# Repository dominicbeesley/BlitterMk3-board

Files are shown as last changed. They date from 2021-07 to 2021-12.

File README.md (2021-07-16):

# BlitterMk3-board
A 6502 FPGA development board targeted at the BBC Micro/Electron range of computers but hopefully also suitable for any 6502/65c02 or 65816 based computer

## Features

- Intel MAX 10 FPGA (10MXXDCF256) in size ranging from 4000 to 50000 LEs
- HDMI output from FPGA via LVDS pins (experimental)
- stereo 1 bit DAC
- uSD card
- Battery backup with optional supervisor IC and memory lockout
- i2c Real time clock
- i2c Flash EEPROM
- parallel 8-bit 55ns flash ROM 39x040 (512kB)
- up to 4 TSOP-II 44 RAM chips for up to 8MB RAM, 1 chip can be optionally battery backed
- 6502/65C02/6512/65102/65112/65816 compatible plug (configurable with jumpers/firmware)
- 5V compatible expansion headers for hosting hard CPU or Raspberry PI Zero

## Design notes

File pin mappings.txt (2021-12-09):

PORTS:

#pins

10	PORTA = 8 bit ACT/HCT io
8	PORTB = 8 bit ACT/HCT o buffer
12	PORTC = 12 bit 74CB3T
12	PORTD = 12 bit 74CB3T
15	PORTE/D/E = 12 bit 74CB3T shared pins on fpga only one enabled at a time
57

m
brdcon	lvl	dir	Mk3 pin		Mk2 pin	(*indicates changes)		65(c)02		65816		6800		6x-09		68008_48	z80		68008_52	680x0_64	680x0_68QFP	8088			8086
																									MIN	MAX		MIN	MAX

	### CMOS LEVEL IO ###

J52	cmos	io	PORTA[0]	CPUSKT_D_io[0]				D[0]	33	D[0]	33	D[0]	33	D[0]	31	D[0]	27	D[0]	14	D[0]	30	D[0]	5	D[0]	5	AD[0]		16	AD[0]		16
J52	cmos	io	PORTA[1]	CPUSKT_D_io[1]				D[1]	32	D[1]	32	D[1]	32	D[1]	30	D[1]	26	D[1]	15	D[1]	29	D[1]	4	D[1]	4	AD[1]		15	AD[1]		15
J52	cmos	io	PORTA[2]	CPUSKT_D_io[2]				D[2]	31	D[2]	31	D[2]	31	D[2]	29	D[2]	25	D[2]	12	D[2]	28	D[2]	3	D[2]	3	AD[2]		14	AD[2]		14
J52	cmos	io	PORTA[3]	CPUSKT_D_io[3]				D[3]	30	D[3]	30	D[3]	30	D[3]	28	D[3]	24	D[3]	8	D[3]	27	D[3]	2	D[3]	2	AD[3]		13	AD[3]		13
J52	cmos	io	PORTA[4]	CPUSKT_D_io[4]				D[4]	29	D[4]	29	D[4]	29	D[4]	27	D[4]	23	D[4]	7	D[4]	26	D[4]	1	D[4]	1	AD[4]		12	AD[4]		12
J52	cmos	io	PORTA[5]	CPUSKT_D_io[5]				D[5]	28	D[5]	28	D[5]	28	D[5]	26	D[5]	22	D[5]	9	D[5]	25	D[5]	64	D[5]	68	AD[5]		11	AD[5]		11
J52	cmos	io	PORTA[6]	CPUSKT_D_io[6]				D[6]	27	D[6]	27	D[6]	27	D[6]	25	D[6]	21	D[6]	10	D[6]	24	D[6]	63	D[6]	67	AD[6]		10	AD[6]		10
J52	cmos	io	PORTA[7]	CPUSKT_D_io[7]				D[7]	26	D[7]	26	D[7]	26	D[7]	24	D[7]	20	D[7]	13	D[7]	23	D[7]	62	D[7]	66	AD[7]		9	AD[7]		9

	### CMOS LEVEL OUT ###

J52	cmos	o	PORTB[0]	CPUSKT_6BE9TSCKnVPA_o			BE	36	BE	6	TSC	39	TSC	39	nVPA	39			nVPA	43	nVPA	21	nVPA	23	MNnMX		33	MNnMX		33
J52	cmos	o	PORTB[1]	CPUSKT_9Q_o			*	[nSO]1	38	[ABRT]2 3	phi1	3	Q	35	?BERR?	40			?BERR?	44	?nBERR? 22	?nBERR?	24	
J52	cmos	o	PORTB[2]	CPUSKT_PHI09EKZCLK_o			phi0	37	phi0	37	phi2	37	E	34	CLK	34			CLK	38	CLK	15	CLK	15	CLK		19	CLK		19
J52	cmos	o	PORTB[3]	CPUSKT_RDY9KnHALTZnWAIT_o		RDY	2	RDY	2	HALT	2	HALT	40			nWAIT	24	?nBGACK?36	?nBGACK?12	?nBGACK?12	READY		22	READY		22
J52	cmos	o	PORTB[4]	CPUSKT_nIRQKnIPL1_o			nIRQ	4	nIRQ	4	nIRQ	4	nIRQ	3	IPL1	41	nIRQ	16	IPL1	45	IPL1	24	IPL1	26	INTR		18	INTR		18
J52	cmos	o	PORTB[5]	CPUSKT_nNMIKnIPL02_o			nNMI	6	nNMI	6	nNMI	6	nNMI	2	IPL0/2	42	nNMI	17	IPL0	47	IPL0	25	IPL0	27	NMI		17	NMI		17
J52	cmos	o	PORTB[6]	CPUSKT_nRES_o				nRES	40	nRES	40	nRES	40	nRES	37			nRES	26	?IPL2?	46	?IPL2?	23	?IPL2?	25	RESET		21	RESET		21
			PORTB[7]	CPUSKT_9nFIRQLnDTACK_o							DBE	36	nFIRQ	4	nDTACK	31			nDTACK	34	nDTACK	10	nDTACK	10

	### TTL I/O ###

J51		i	PORTC[0]	CPUSKT_A_i[0]				A[0]	9	A[0]	9	A[0]	9	A[0]	8	A[0]	46	A[0]	30	A[0]	51	?nLDS?	8	?nLDS?	8	nSSO	-hi-	34	BHE/S7		34
J51		i	PORTC[1]	CPUSKT_A_i[1]				A[1]	10	A[1]	10	A[1]	10	A[1]	9	A[1]	47	A[1]	31	A[1]	51	A[1]	29	A[1]	32	
J51		i	PORTC[2]	CPUSKT_A_i[2]				A[2]	11	A[2]	11	A[2]	11	A[2]	10	A[2]	48	A[2]	32	A[2]	1	A[2]	30	A[2]	33
J51		i	PORTC[3]	CPUSKT_A_i[3]				A[3]	12	A[3]	12	A[3]	12	A[3]	11	A[3]	1	A[3]	33	A[3]	2	A[3]	31	A[3]	34
J51		i	PORTC[4]	CPUSKT_A_i[4]				A[4]	13	A[4]	13	A[4]	13	A[4]	12	A[4]	2	A[4]	34	A[4]	3	A[4]	32	A[4]	35
J51		i	PORTC[5]	CPUSKT_A_i[5]				A[5]	14	A[5]	14	A[5]	14	A[5]	13	A[5]	3	A[5]	35	A[5]	4	A[5]	33	A[5]	36
J51		i	PORTC[6]	CPUSKT_A_i[6]				A[6]	15	A[6]	15	A[6]	15	A[6]	14	A[6]	4	A[6]	36	A[6]	5	A[6]	34	A[6]	37
J51		i	PORTC[7]	CPUSKT_A_i[7]				A[7]	16	A[7]	16	A[7]	16	A[7]	15	A[7]	5	A[7]	37	A[7]	6	A[7]	35	A[7]	38
J51		i	PORTC[8]	CPUSKT_A_i[16]												A[16]	16			A[16]	18	A[16]	44	A[16]	47	A[16]S3		38	A[16]S3		38
J51		i	PORTC[9]	CPUSKT_A_i[17]												A[17]	17			A[17]	19	A[17]	45	A[17]	48	A[17]S4		37	A[17]S4		37
J51		i	PORTC[10]	CPUSKT_A_i[18]												A[18]	18			A[18]	20	A[18]	46	A[18]	49	A[18]S5		36	A[18]S5		36
J51		i	PORTC[11]	CPUSKT_A_i[19]												A[19]	19			A[19]	21	A[19]	47	A[19]	50	A[19]S6		35	A[19]S6		35
	
J51		i	PORTD[0]	CPUSKT_6EKEZnRD_i			-	35	E	35					?E?	38	nRD	21	?E?	42	?E?	20	?E?	22	nRD		32	nRD		32
J51		i	PORTD[1]	CPUSKT_RnWZnWR_i			RnW	34	RnW	34	RnW	32	RnW	32	RnW	30	nWR	22	RnW	33	RnW	9	RnW	9	nWR	nLOCK	29	nWR	nLOCK	29
J51		i 	PORTD[2]	CPUSKT_PHI16ABRT9BSKnDS_i	*							BS	5	nDS	29	?nHALT?	18	nDS	32	?nUDS?	7	?nUDS?	7	nDEN	nS2	26	nDEN	nS2	26
J51		i	PORTD[3]	CPUSKT_PHI26VDAKFC0ZnMREQ_i		phi2	39	VDA	39					FC0	45	nMREQ	19	FC0	50	FC0	28	FC0	30	nINTA	QS1	24	nINTA	QS1	24
J51		i	PORTD[4]	CPUSKT_SYNC6VPA9LICKFC2ZnM1_i		SYNC	7	VPA	7			LIC	38	FC2	43	M1	27	FC2	48	FC2	26	FC2	28	DTnR	nS1	27	DTnR	nS1	27
J51		i	PORTD[5]	CPUSKT_VSS6VPA9BAKnAS_i			[vss]3	1	[VPB]3	1	BA	6	BA	6	nAS	28	?nRFSH?	28	nAS	31	nAS	6	nAS	6	ALE	QS0	25	ALE	QS0	25
J51		i	PORTD[6]	CPUSKT_nSO6MX9AVMAKFC1ZnIOREQ_i	*	phi1	3	[M/X]1	38	VMA	36	AVMA	36	FC1	44	nIOREQ	20	FC1	49	FC1	27	FC1	29	IOnM	nS0	28	MnIO	nS0	28
J51		io	PORTD[7]	CPUSKT_C6nML9BUSYKnBGZnBUSACK_i 	MLB	5	MLB	5			BUSY	33	nBG	32	nBUSACK	23	nBG	35	nBG	11	nBG	11	HLDA	RQGT0	30	HLDA	RQGT0	
J51		io	PORTD[8]	CPUSKT_KnBRZnBUSREQ_o											nBR	33	nBUSREQ	25	nBR	37	nBR	13	nBR	13	HOLD	RQGT1	31	HOLD	RQGT1	31
J51		o	PORTD[9]														nRES	37			nRES	41	nRES	18	nRES	20	?nTEST?		23	?nTEST?		23
J51		o	PORTD[10]														HALT	36			nHALT	40	nHALT	17	nHALT	19				
J51		i	PORTD[11]																		?nVMA?	19	?nVMA?	21

1 nSO/MX is selected via jumper
2 ABORT/PHI1 is selected via jumper
3 jumper to allow pull pin 3 direct to gnd

	### MULTIPLEXED I/O ### only one of these ports is active at once

J51		i	PORTE[0]	CPUSKT_A_i[8]				A[8]	17	A[8]	17	A[8]	17	A[8]	16	A[8]	6	A[8]	38	A[8]	7	A[8]	36	A[8]	39	
J51		i	PORTE[1]	CPUSKT_A_i[9]				A[9]	18	A[9]	18	A[9]	18	A[9]	17	A[9]	7	A[9]	39	A[9]	8	A[9]	37	A[9]	40	
J53		i	PORTE[2]	CPUSKT_A_i[10]				A[10]	19	A[10]	19	A[10]	19	A[10]	18	A[10]	8	A[10]	40	A[10]	9	A[10]	38	A[10]	41	
J53		i	PORTE[3]	CPUSKT_A_i[11]				A[11]	20	A[11]	20	A[11]	20	A[11]	19	A[11]	9	A[11]	1	A[11]	10	A[11]	39	A[11]	42	
J53		i	PORTE[4]	CPUSKT_A_i[12]				A[12]	22	A[12]	22	A[12]	22	A[12]	20	A[12]	10	A[12]	2	A[12]	11	A[12]	40	A[12]	43	
J53		i	PORTE[5]	CPUSKT_A_i[13]				A[13]	23	A[13]	23	A[13]	23	A[13]	21	A[13]	11	A[13]	3	A[13]	12	A[13]	41	A[13]	55	
J53		i	PORTE[6]	CPUSKT_A_i[14]				A[14]	24	A[14]	24	A[14]	24	A[14]	22	A[14]	12	A[14]	4	A[14]	14	A[14]	42	A[14]	45	
J53		i	PORTE[7]	CPUSKT_A_i[15]				A[15]	25	A[15]	25	A[15]	25	A[15]	23	A[15]	14	A[15]	5	A[15]	16	A[15]	43	A[15]	46	
J54		i	PORTE[8]																		A[20]	22	A[20]	48	A[20]	51
J54		i	PORTE[9]																		A[21]	13	A[21]	50	A[21]	53
J54		i	PORTE[10]																				A[22]	51	A[22]	54
J54		i	PORTE[11]																				A[23]	52	A[23]	55

J54		io	PORTF[4]																				D[8]	61	D[8]	65	A[8]		8	AD[8]		8
J54		io	PORTF[5]																				D[9]	60	D[9]	64	A[9]		7	AD[9]		7
J54		io	PORTF[6]																				D[10]	59	D[10]	63	A[10]		6	AD[10]		6
J54		io	PORTF[7]																				D[11]	58	D[11]	62	A[11]		5	AD[11]		5
J54		io	PORTF[8]																				D[12]	57	D[12]	61	A[12]		4	AD[12]		4
J54		io	PORTF[9]																				D[13]	56	D[13]	60	A[13]		3	AD[13]		3
J54		io	PORTF[10]																				D[14]	55	D[14]	59	A[14]		2	AD[14]		2
J54		io	PORTF[11]																				D[15]	54	D[15]	58	A[15]		39	AD[15]		

# boot time configuration

t65		PORTG[3]						
swromx		PORTG[4]			
mosram		PORTG[5]			
memi		PORTG[6]
-free-		PORTG[7]
-free-		PORTG[8]

sys_type[0]	PORTG[0]
sys_type[1]	PORTG[1]
sys_type[2]	PORTG[2]

# cpu board configuration

cpu_type[0]	PORTF[0]
cpu_type[1]	PORTF[1]
cpu_type[2]	PORTF[2]
cpu_type[3]	PORTF[3]

cpu_speed[0]	PORTG[9]
cpu_speed[1]	PORTG[10]
cpu_speed[2]	PORTG[11]

	- own pin -
	- own pin -
	- own pin -

#cpu config
			cpu_type	speed
			D C B A		C B A
			3 2 1 0 	2 1 0
6502A		2MHz	- - - -		- - -

W65c02		2Mhz	- - - x		- - -
W65c02		4Mhz	- - - x		- - x
W65c02		8MHz	- - - x		- x -
W65c02		10Mhz	- - - x		- x x
W65c02		14MHz	- - - x		x - -

R65c02		2Mhz	- - x -		- - -
R65c02		4Mhz	- - x -		- - x
R65c02		8MHz	- - x -		- x -
R65c02		10Mhz	- - x -		- x x
R65c02		14MHz	- - x -		x - -

65x816		2Mhz	- - x x		- - -
65x816		4Mhz	- - x x		- - x
65x816		8MHz	- - x x		- x -
65x816		10Mhz	- - x x		- x x
65x816		14MHz	- - x x		x - -

R6512		2Mhz	- x - -		- - -
R6512		4Mhz	- x - -		- - x
R6512		8MHz	- x - -		- x -
R6512		10Mhz	- x - -		- x x
R6512		14MHz	- x - -		x - -

G65SC12		2Mhz	- x - x		- - -
G65SC12		4Mhz	- x - x		- - x
G65SC12		8MHz	- x - x		- x -
G65SC12		10Mhz	- x - x		- x x
G65SC12		14MHz	- x - x		x - -

65c102		2Mhz	- x x -		- - -
65c102		4Mhz	- x x -		- - x
65c102		8MHz	- x x -		- x -
65c102		10Mhz	- x x -		- x x
65c102		14MHz	- x x -		x - -

65c112		2Mhz	- x x x		- - -
65c112		4Mhz	- x x x		- - x
65c112		8MHz	- x x x		- x -
65c112		10Mhz	- x x x		- x x
65c112		14MHz	- x x x		x - -

6809		2	x - - -		- - -
6809		3.5	x - - -		- - x
6309		2	x - - -		x - -
6309		3.5	x - - -		x - x
6309		4	x - - -		x x -

6800		2	x - - -		x x x		???

z80		2	x - x -		- - -
z80		4	x - x -		- - x
z80		8	x - x -		- x -
z80		10	x - x -		- x x
z80		12	x - x -		x - -
z80		16	x - x -		x - x
z80		20	x - x -		x x -

8088		?	x - x x		x - -
8088		?	x - x x		x - x
8088		?	x - x x		x x -
8088		?	x - x x		x x x

8086		?	x - x x		- - -
8086		?	x - x x		- - x
8086		?	x - x x		- x -
8086		?	x - x x		- x x

68008/48	8	x x - -		- - -
68008/48	10	x x - -		- - x

68008/52	8	x x - -		- x -
68008/52	10	x x - -		- x x

680x0		8	x x - -		x - -
680x0		10	x x - -		x - x
680x0		16	x x - -		x x -
680x0		20	x x - -		x x x

spare:			x - - x
spare:			x x - x
spare:			x x x -

rpi 		model	x x x x		x - -
rpi 		model	x x x x		x - x
rpi 		model	x x x x		x x -
rpi 		model	x x x x		x x x

other		?	x x x x		- ? ?	 (8)

# sys type config

		sys_type
		2 1 0
Model B		- - -
Elk		- - x
Model B+	- x -
Master 128	- x x

# note 65816 ABORT is pin shared with phi1 - need a cmos output and jumper for 816, moved to 6x09 Q pin if req
# note nSO, if required for 6502 will need a cmos output (for c02) and jumper
# note BERR was tied to vcc on mk.2 give own pin shared with 6x09 Q on mk.3
# is DBE/BE for 65xx needed, if not save a cmos output and add pull up
# is VPA required for 68008 - if not get rid and add pull up (used for IRQ not sure about other stuff)

TODO: check all pins against datasheets
Z80: the rfsh line is not connected on mk.2 board in beeb but D7 is connected to D7 by bodge wire!?
Z80: connect nRFSH to CPUSKT_VSS6VPA9BAKnAS_i (noted in mk2 vhdl) CHECK!
z80: connect nHALT to CPUSKT_PHI16ABRT9BSKnDS_i? CHECK!

All 68k - ignore E? (not used in mk.2 vhdl)
68008_52 - connect IPL0/2 together as per 48 pin device?
68008_52 - ignore bgack?
680x0	 - ignore VMA?

CHECK: is 8088 IOnM really inverse of 8086 MnIO

POSS TIE two pins of PORTD for stronger clock?

CHECK: PORTE/F/G overlap esp for A/D overlap in m68k cycles

ADD PORTB for extra config pins (12 bits) and share with C/D - frees up more pins?

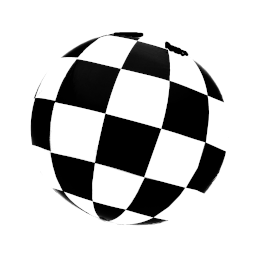
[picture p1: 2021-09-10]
assets/boing.png

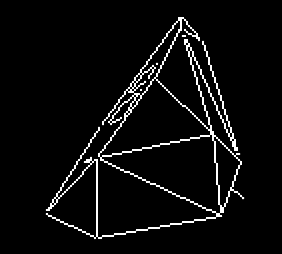
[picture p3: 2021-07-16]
assets/cobra-cropped.png

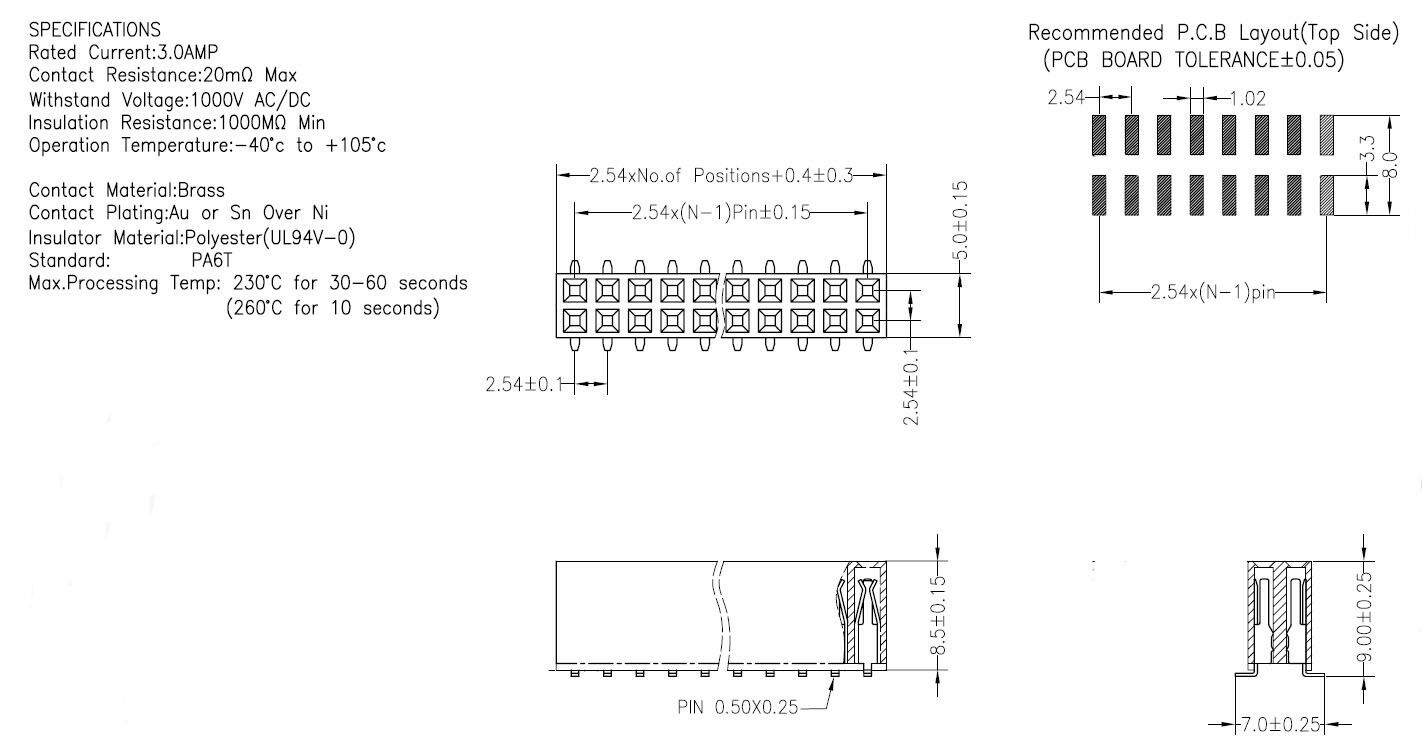
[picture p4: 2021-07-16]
datasheets/s-l1600 (2).jpg

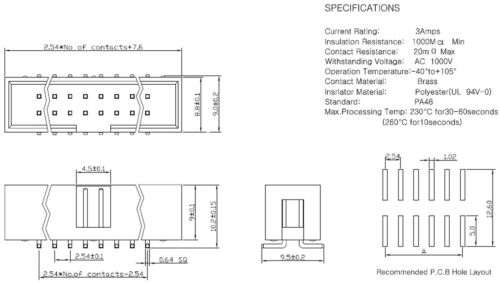
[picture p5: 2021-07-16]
datasheets/s-l500.jpg

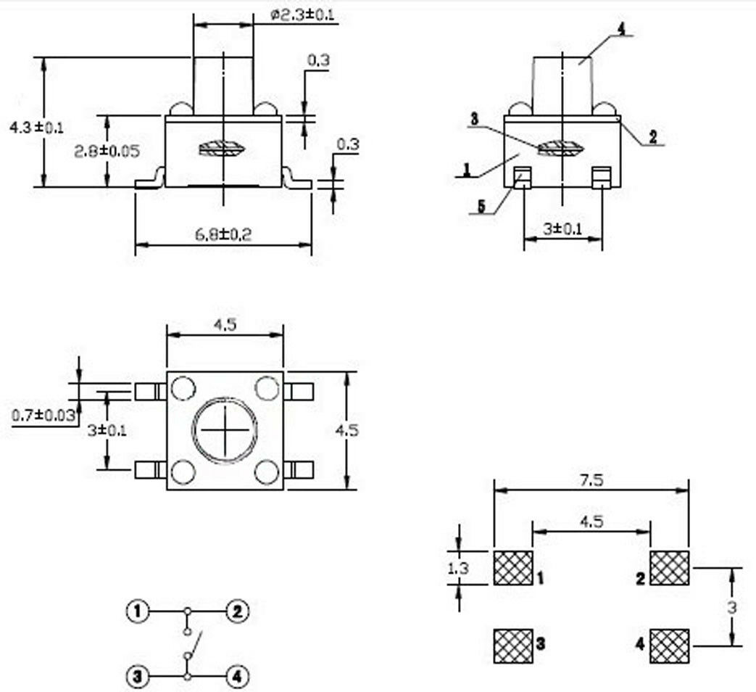
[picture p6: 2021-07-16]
datasheets/s-l1600 (1).jpg

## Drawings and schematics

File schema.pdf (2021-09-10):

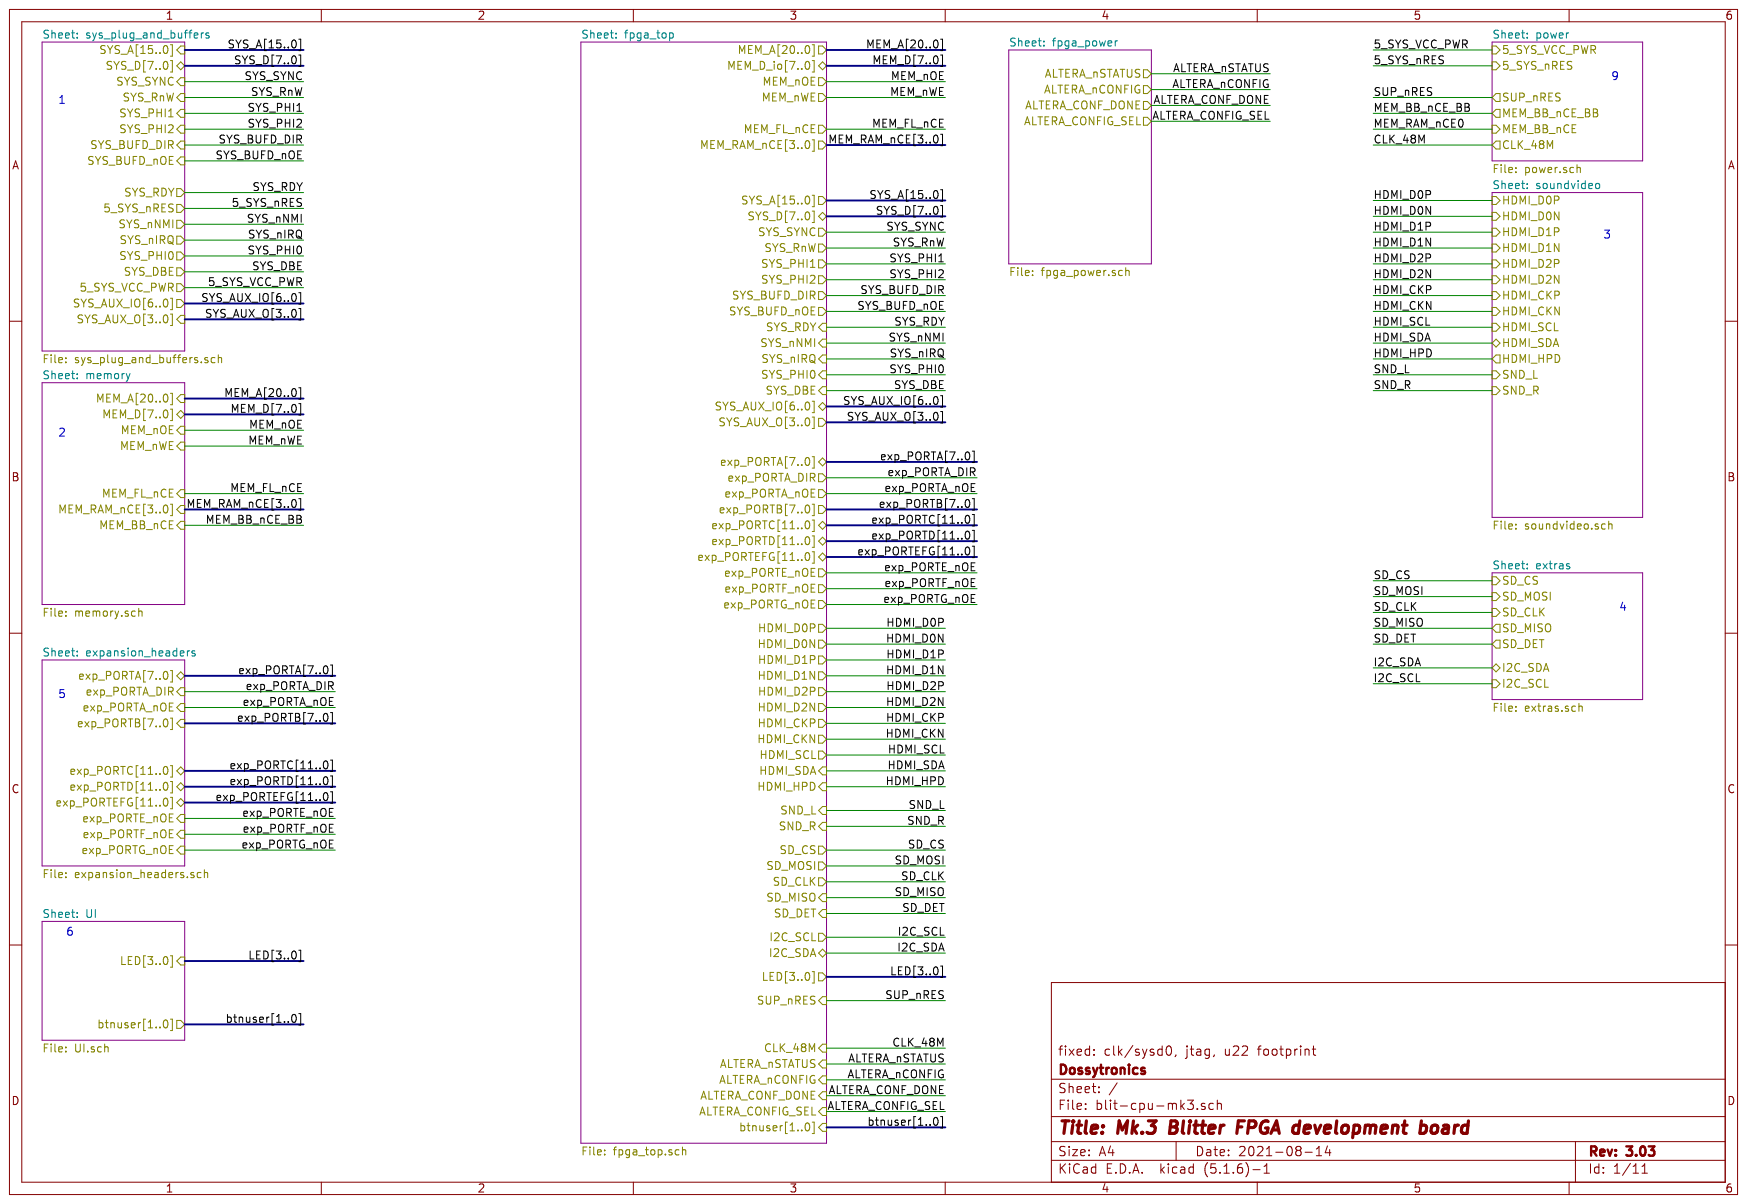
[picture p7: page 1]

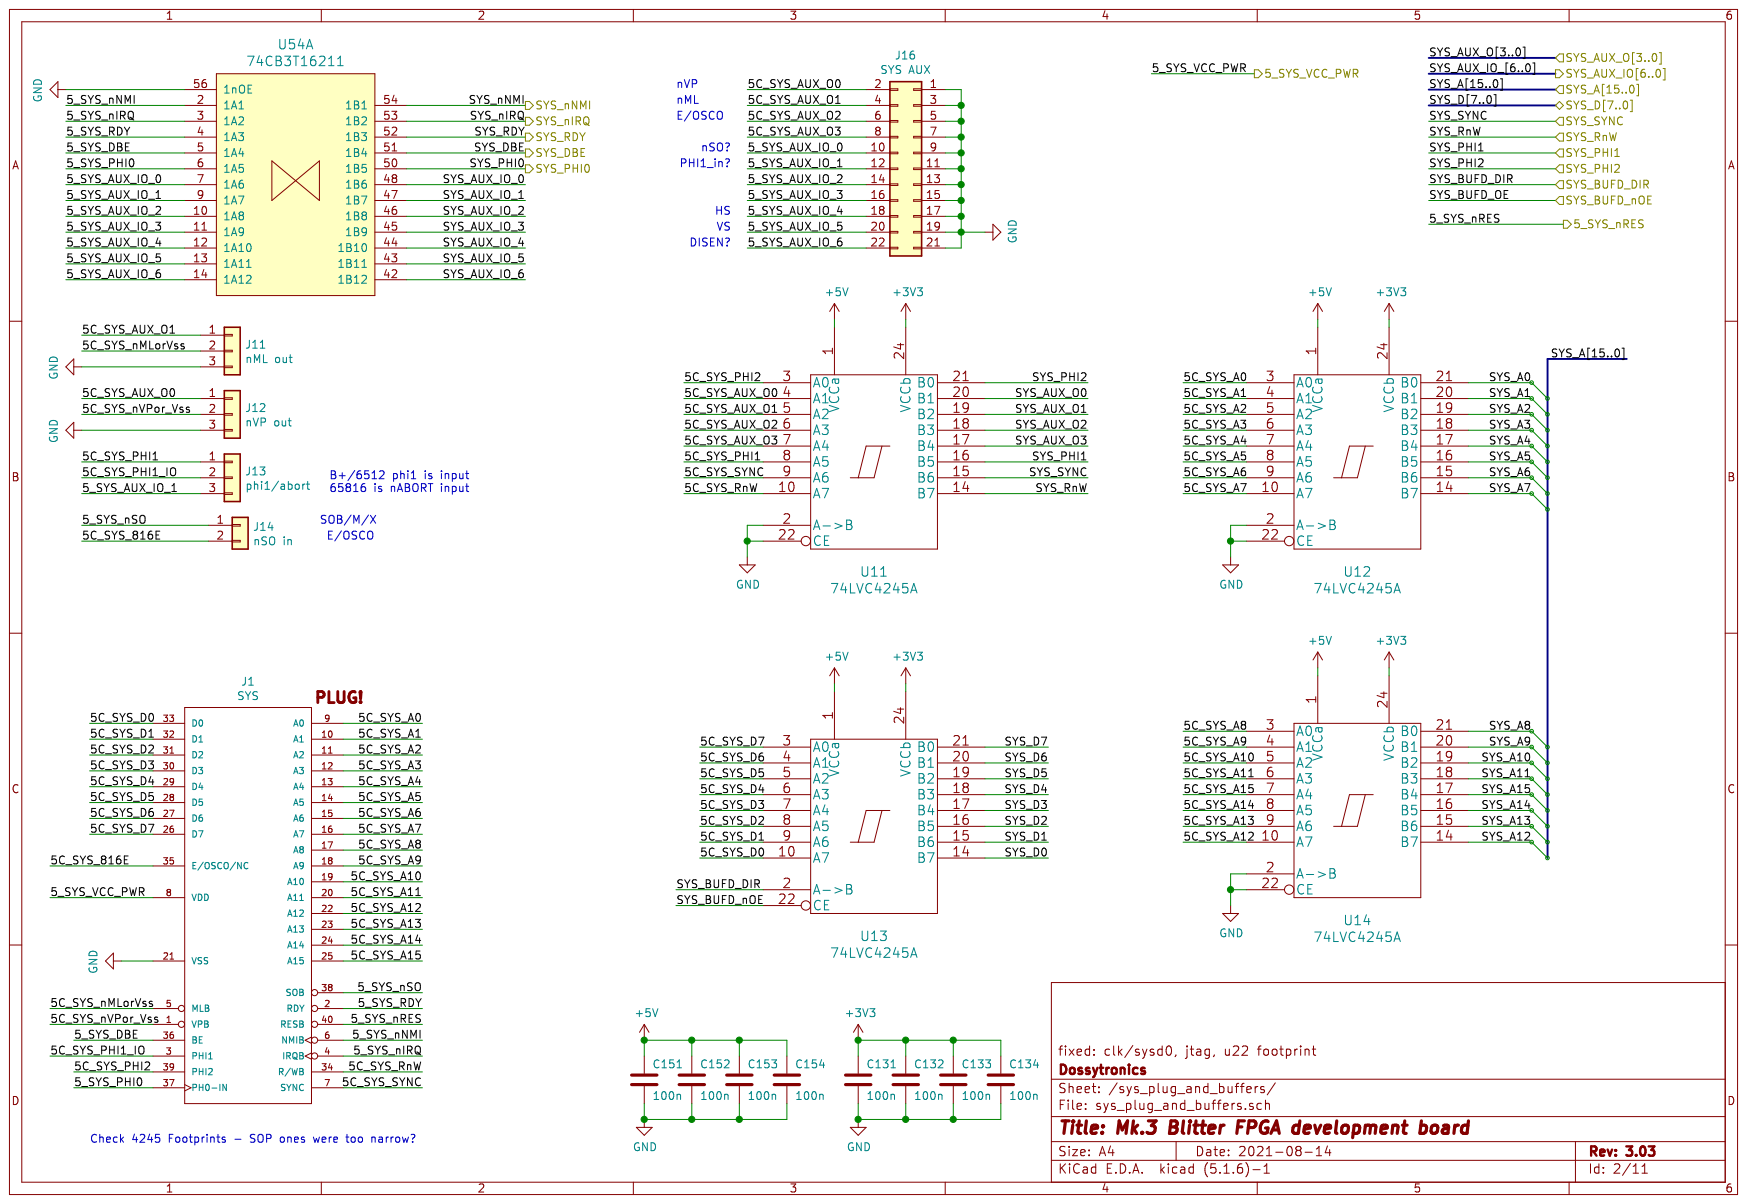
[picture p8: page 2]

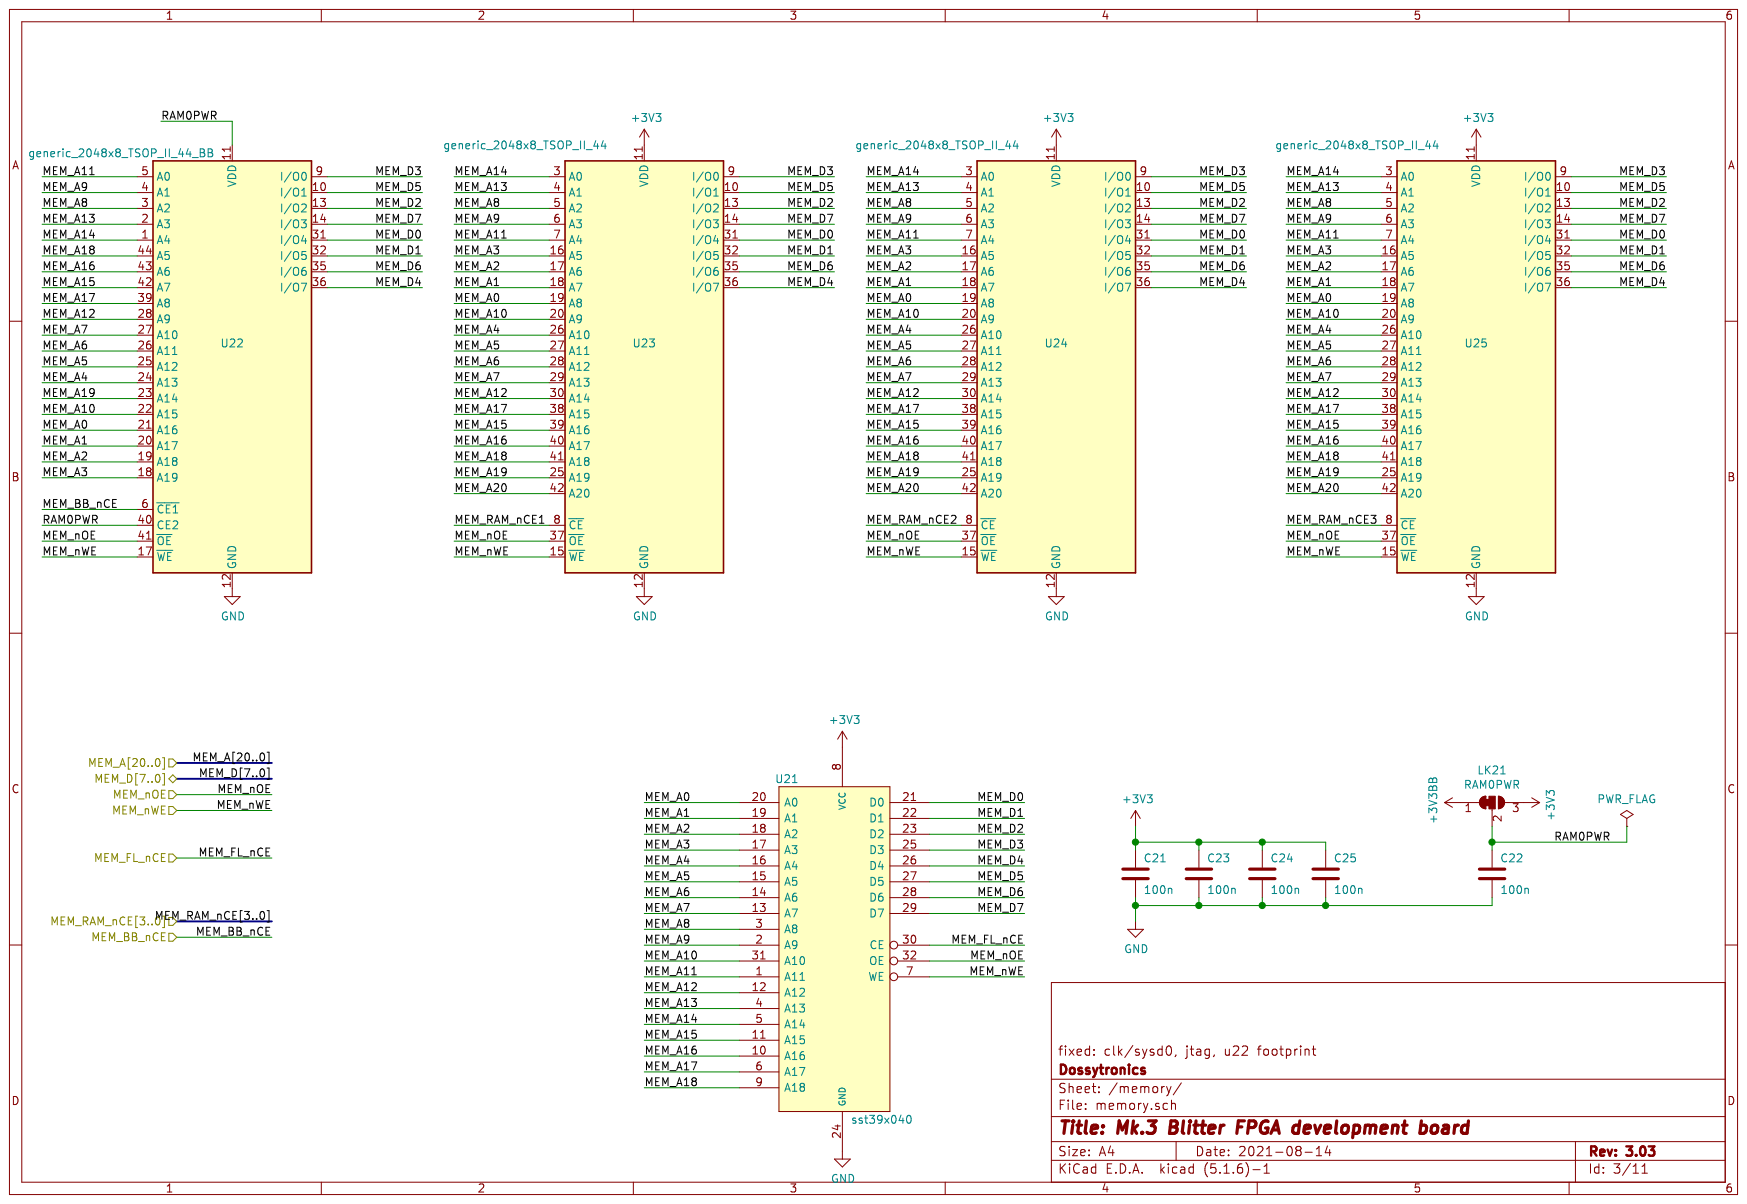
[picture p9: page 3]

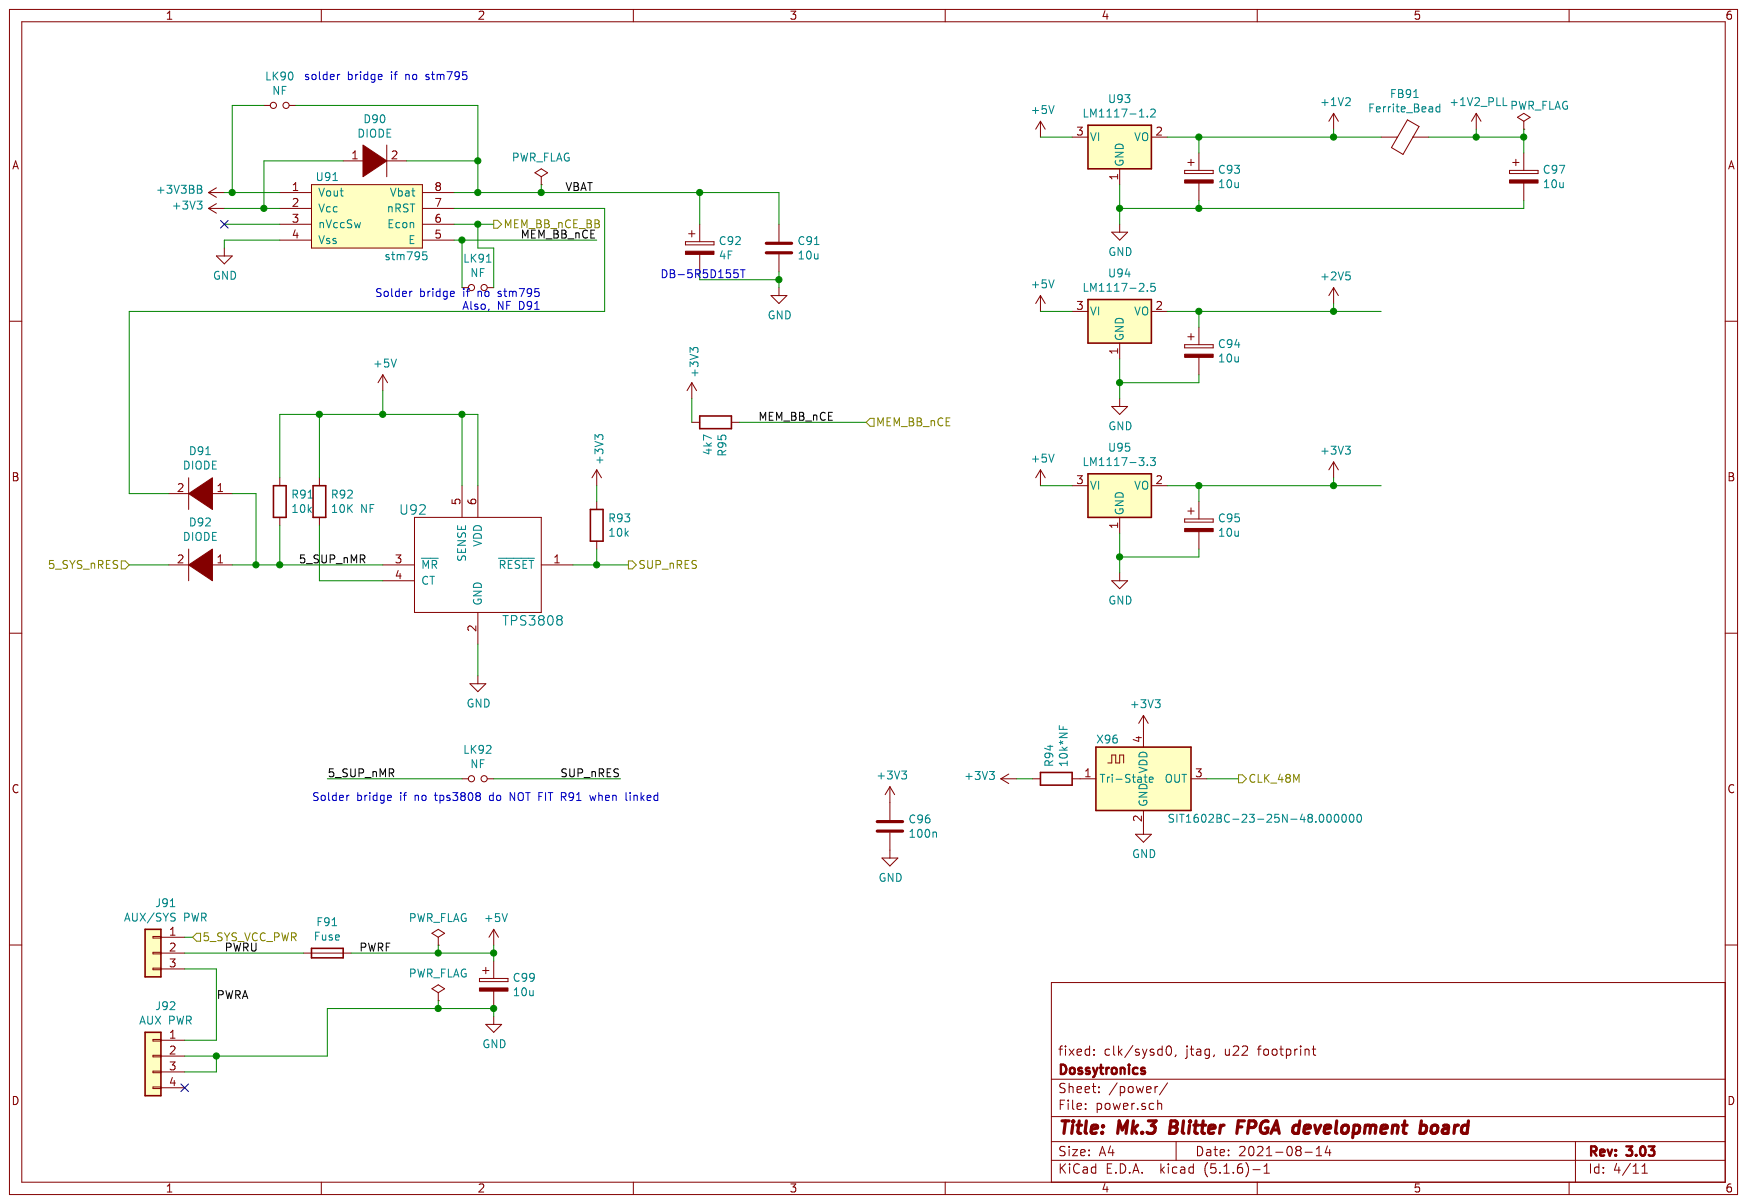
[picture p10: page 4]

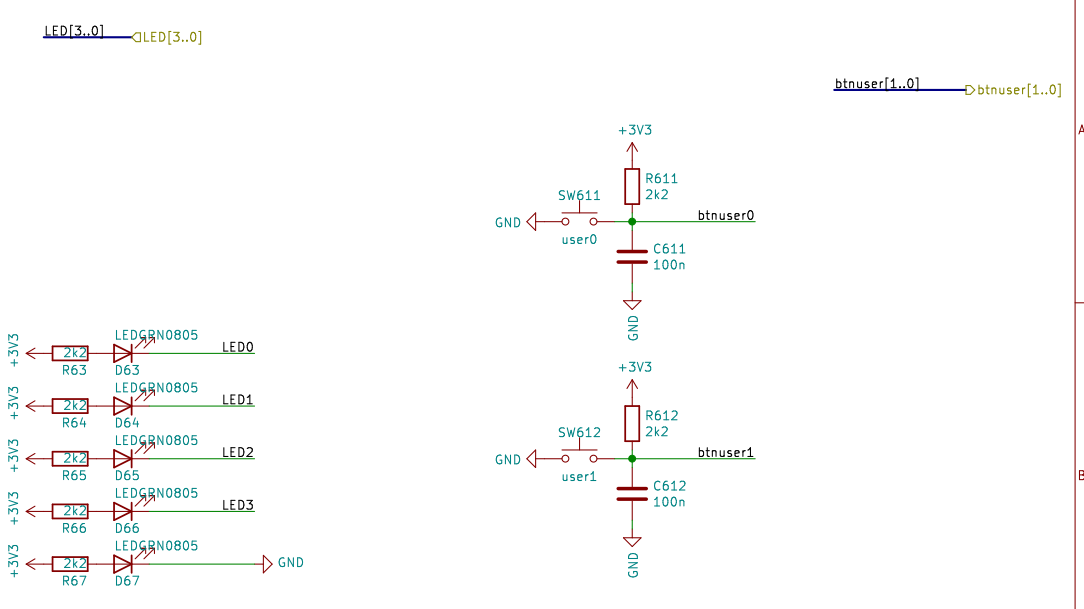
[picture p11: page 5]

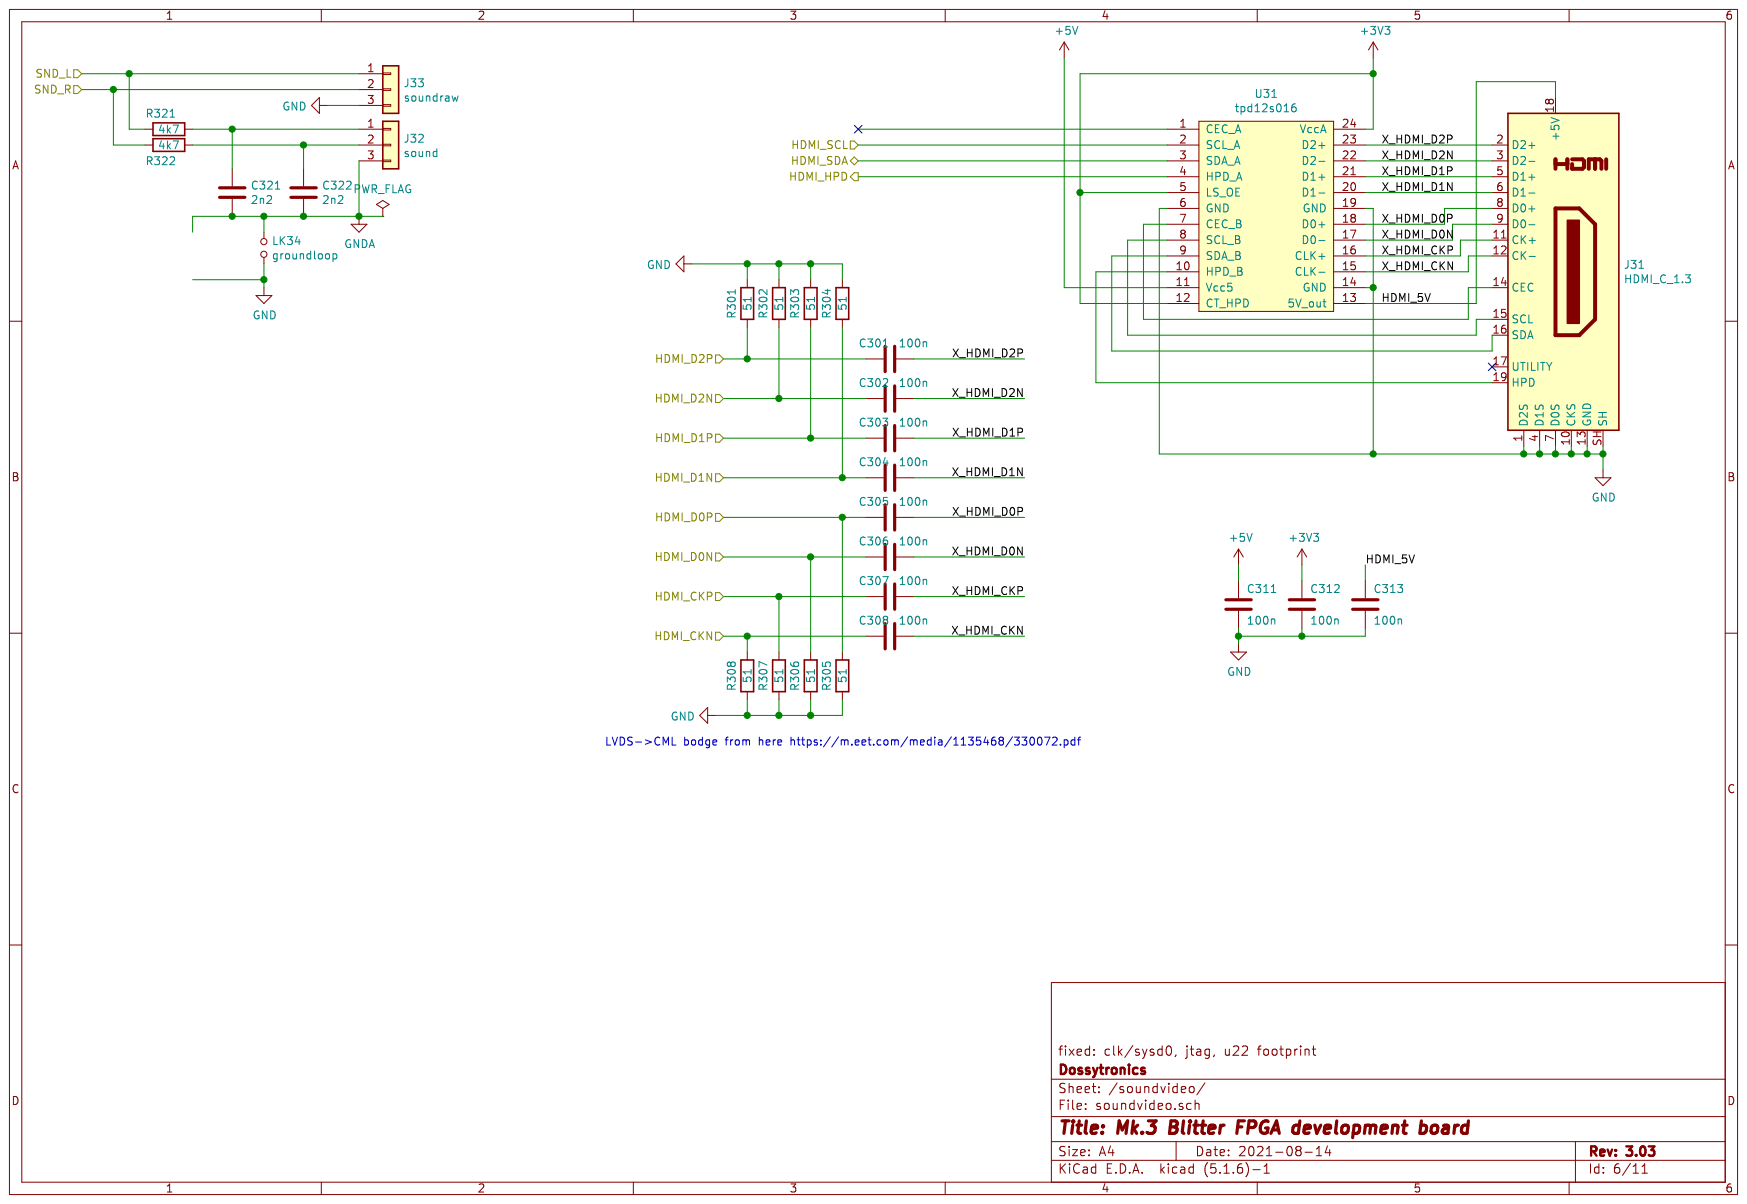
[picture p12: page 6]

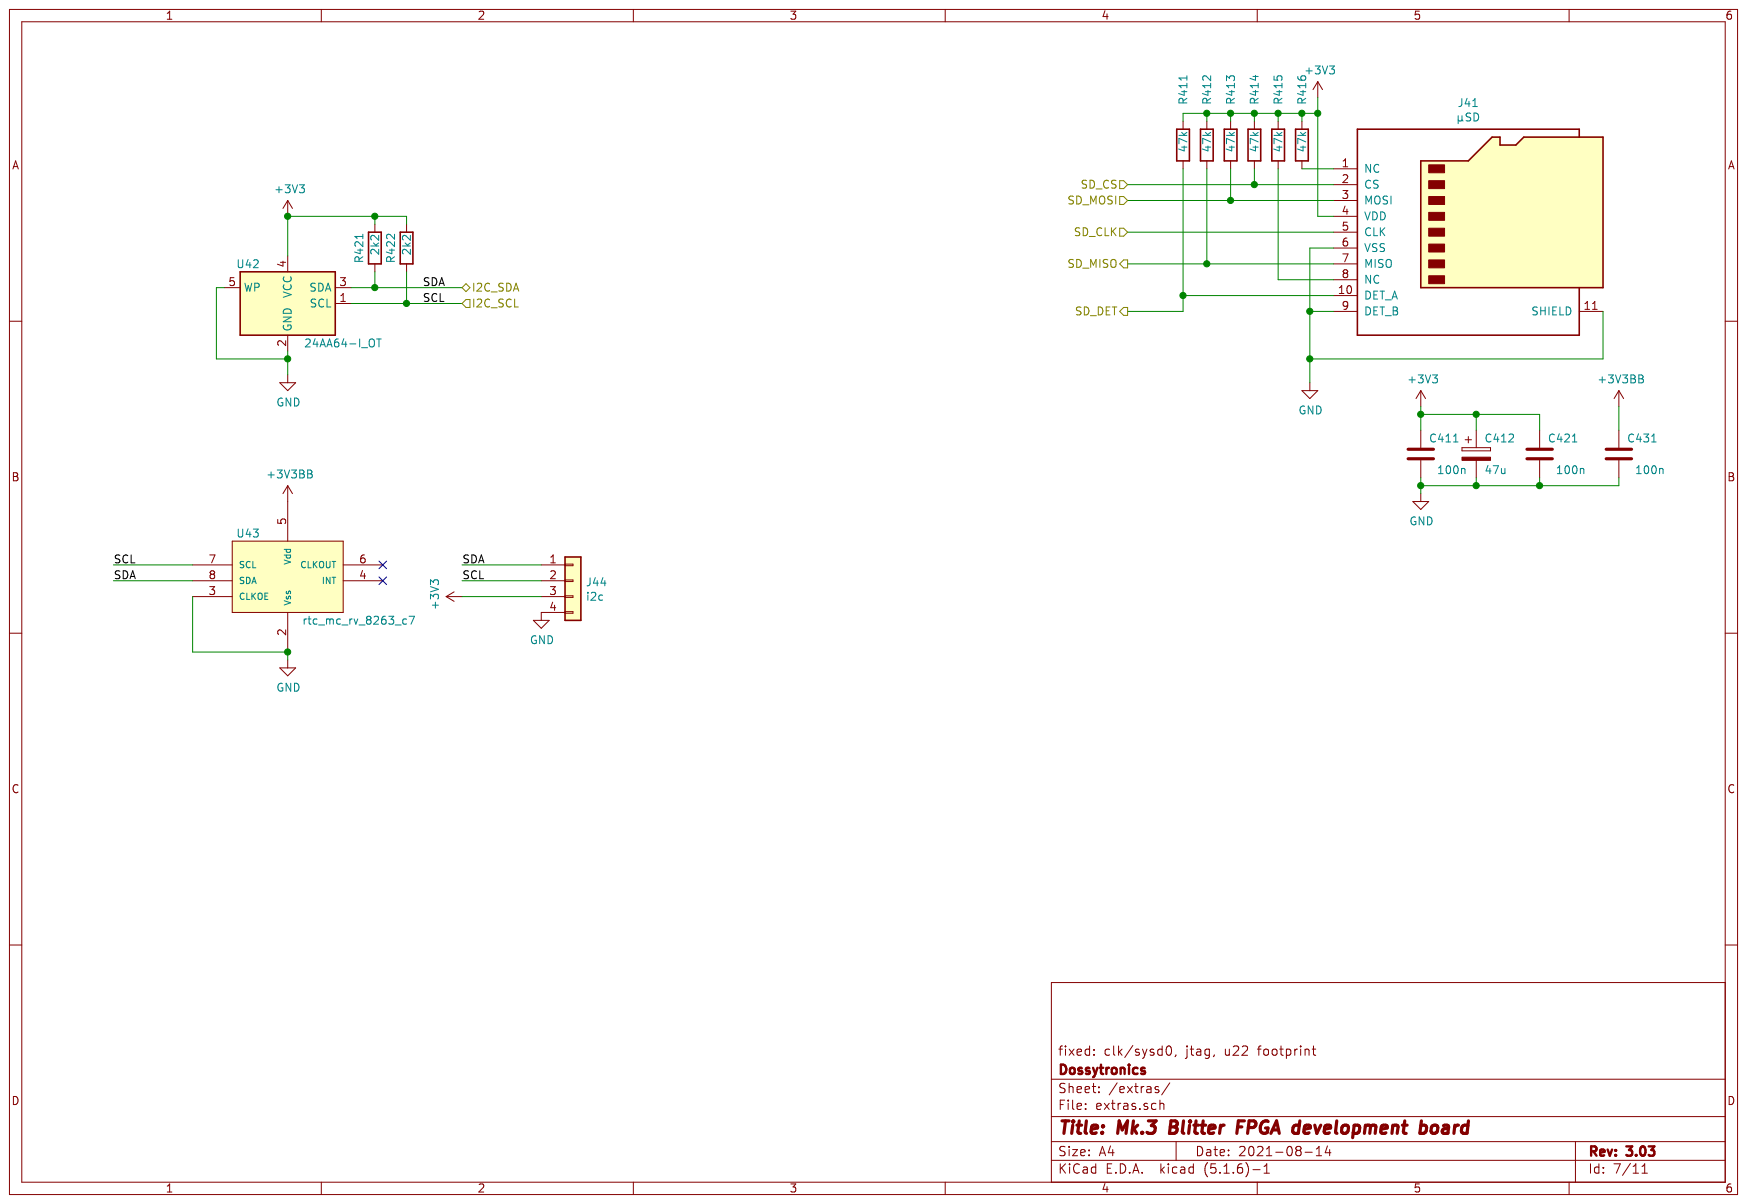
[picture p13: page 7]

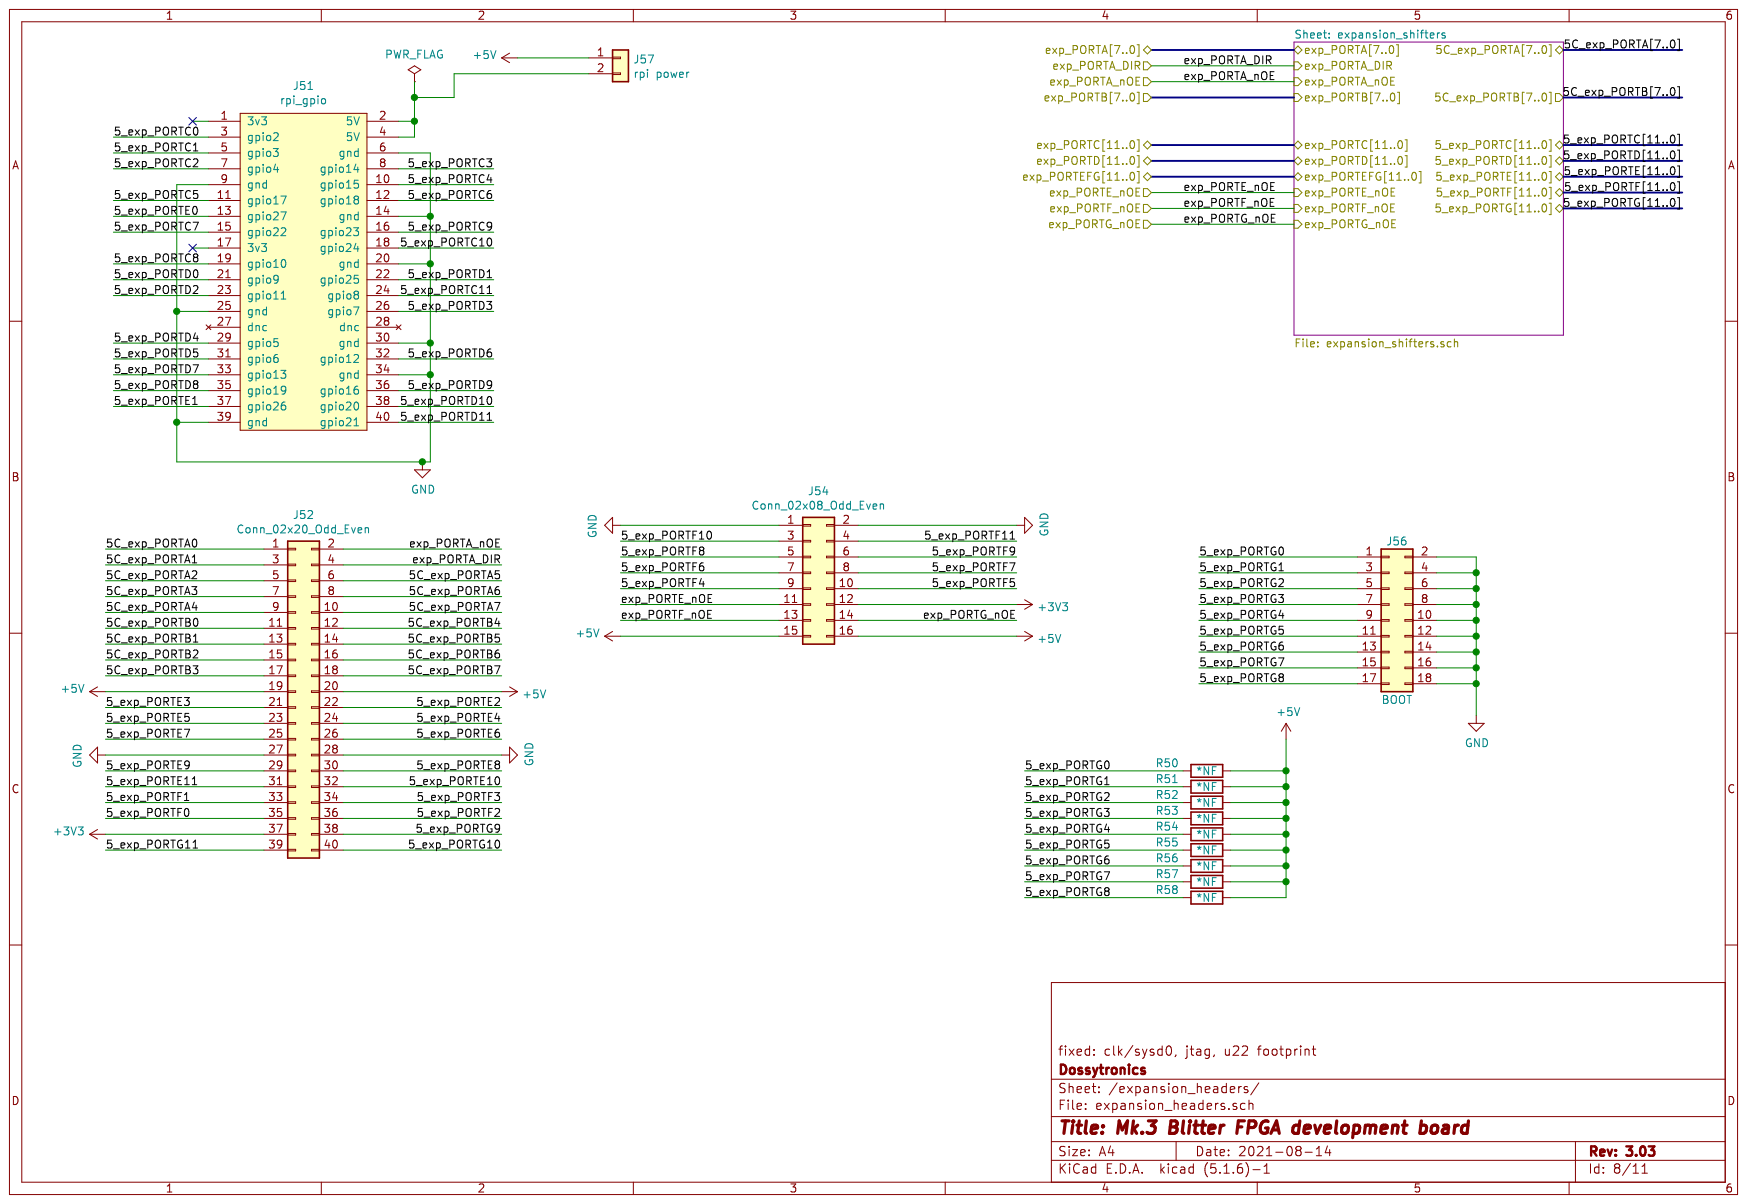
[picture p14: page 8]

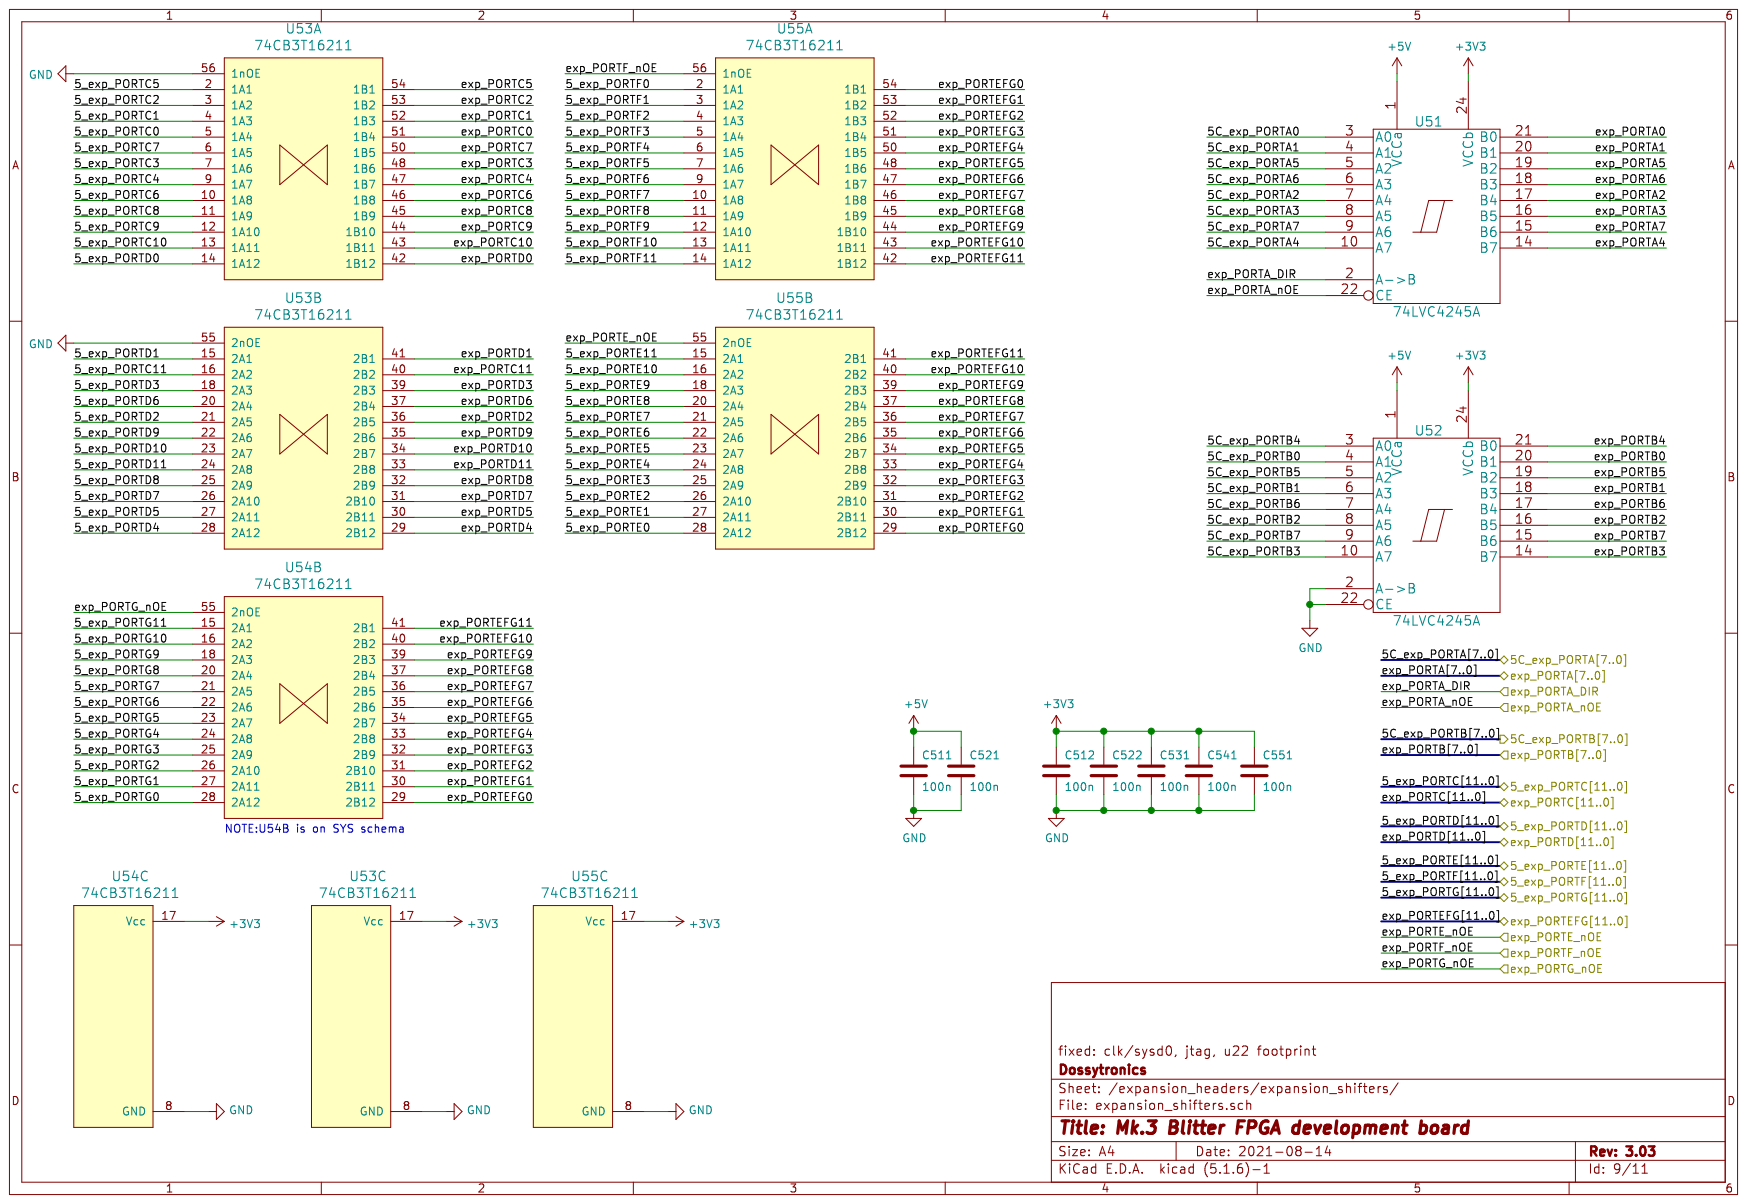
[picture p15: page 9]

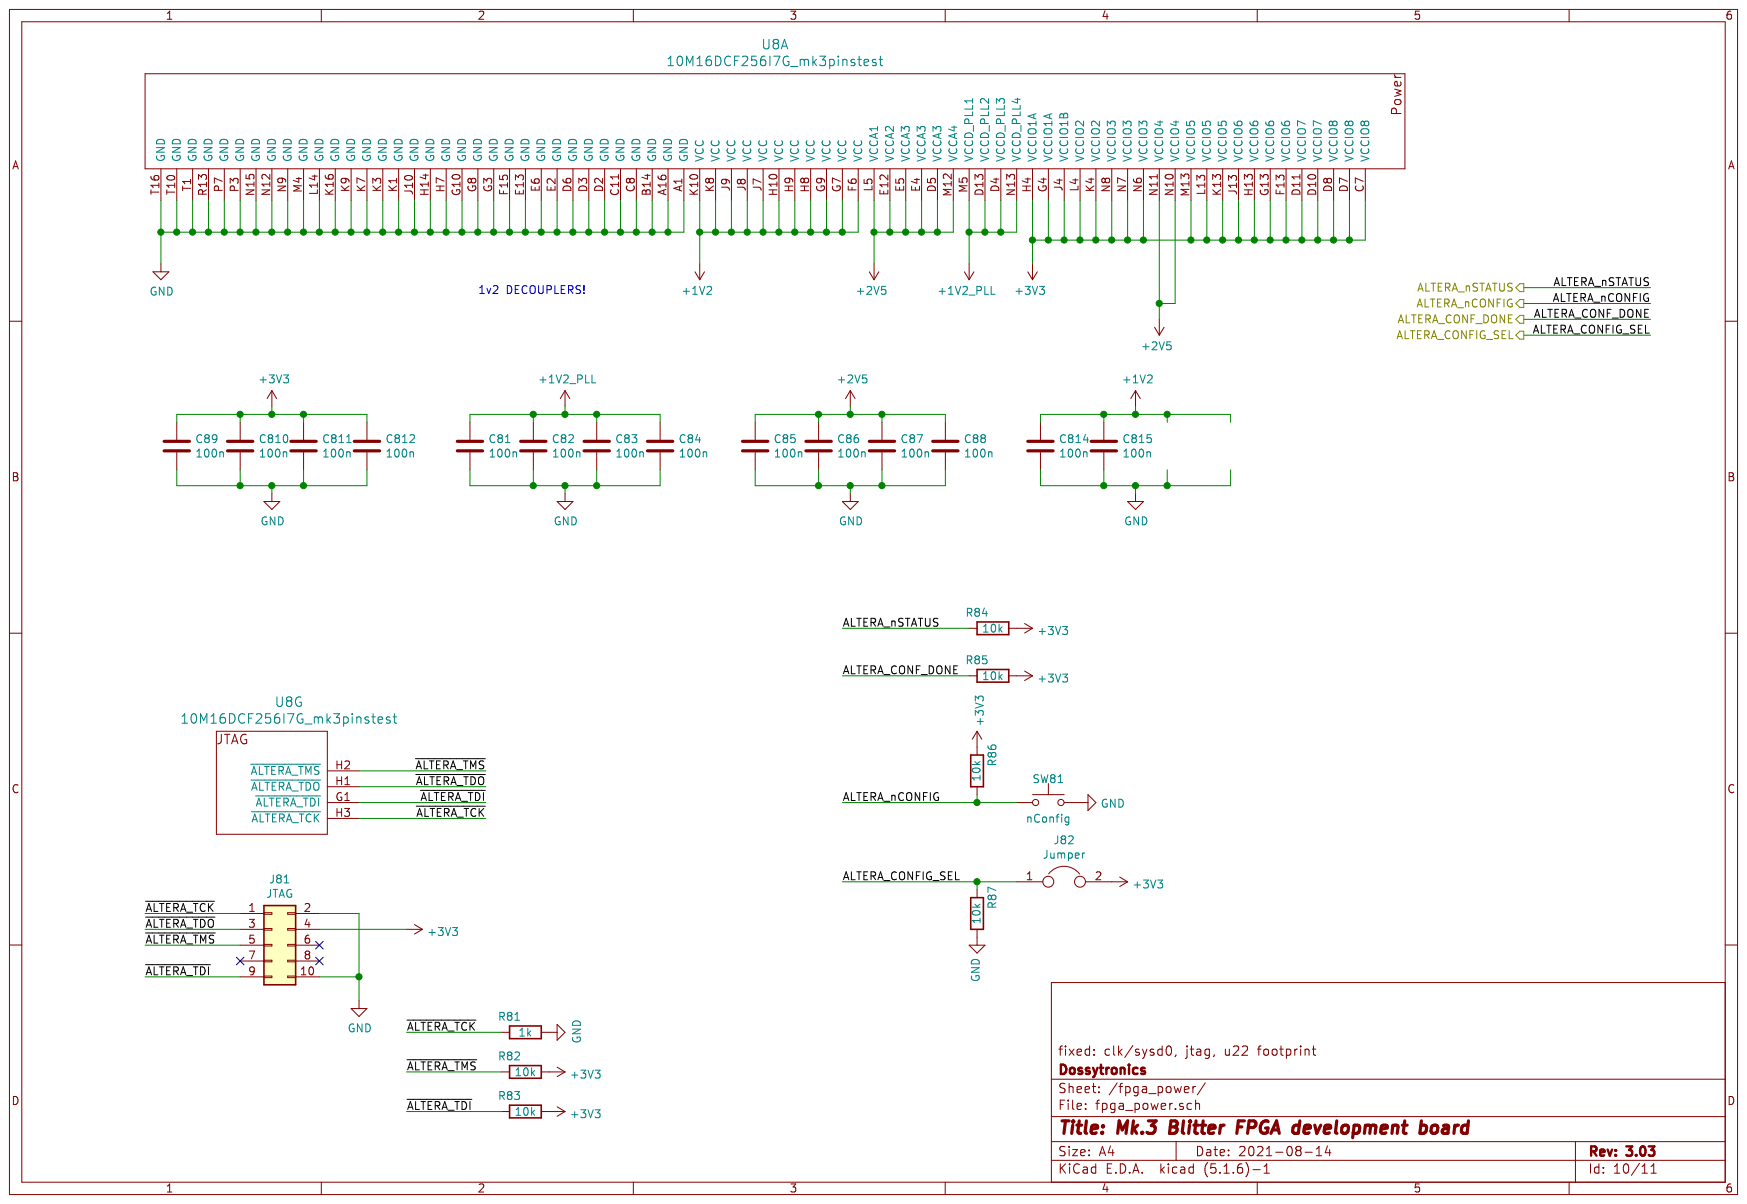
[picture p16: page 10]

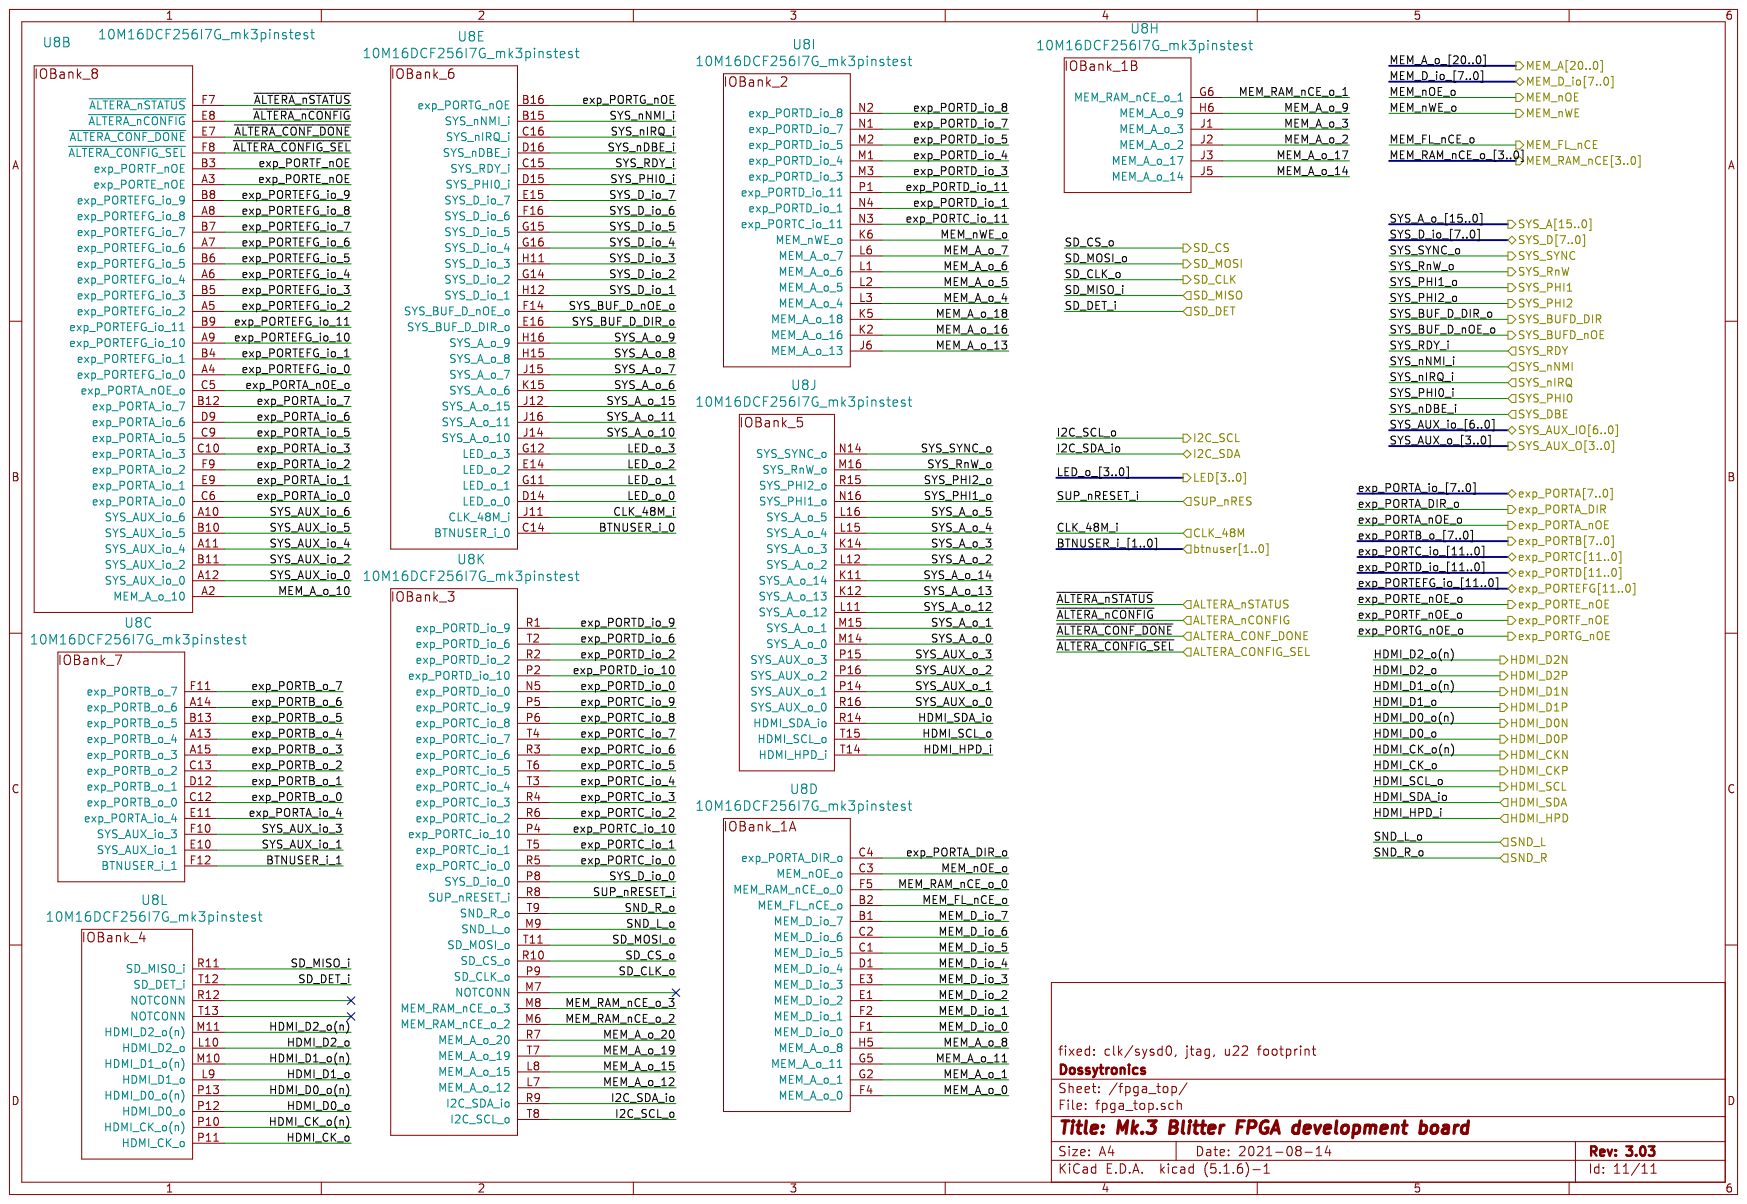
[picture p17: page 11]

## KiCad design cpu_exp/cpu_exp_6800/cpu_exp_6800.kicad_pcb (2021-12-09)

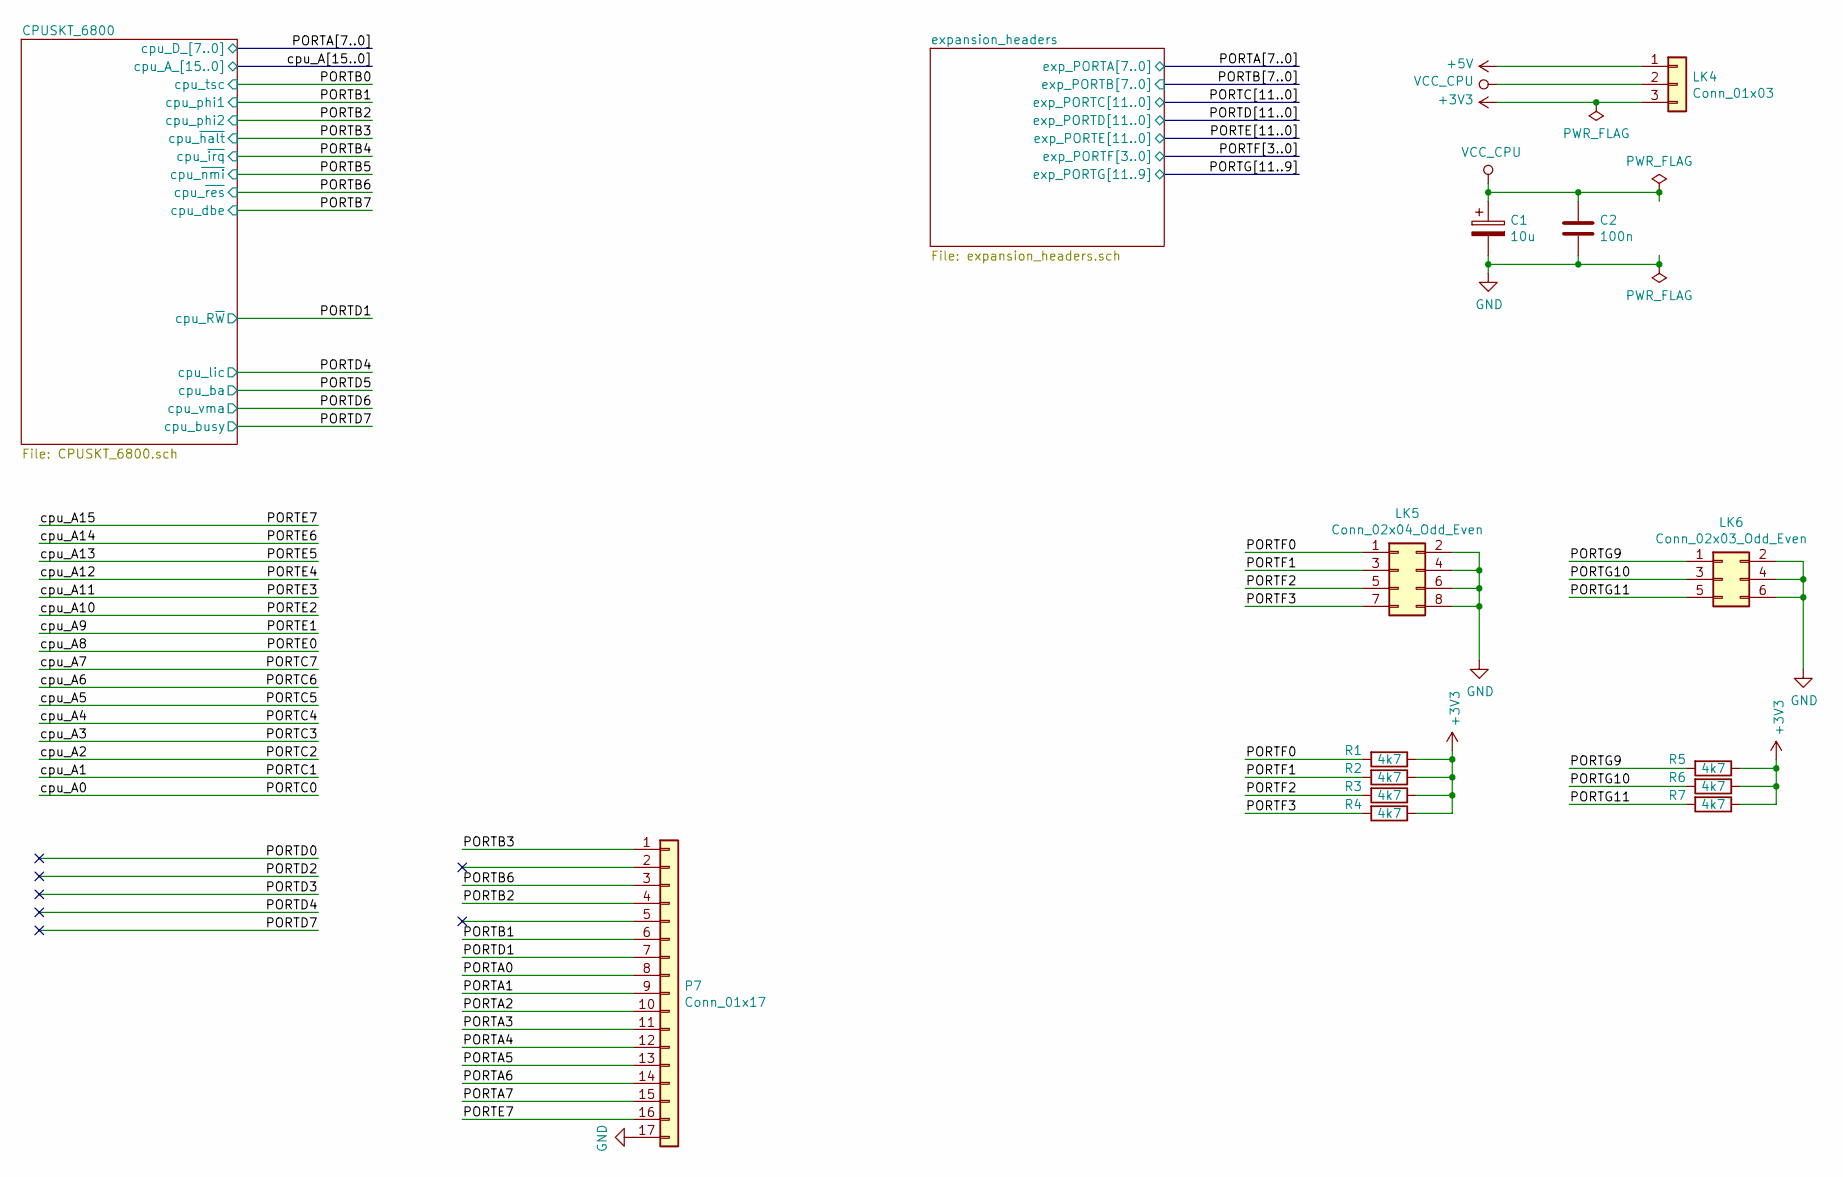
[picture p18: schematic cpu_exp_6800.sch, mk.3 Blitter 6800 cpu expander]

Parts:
C1: 10u; C_1206
C2: 100n; C_1206
LK4: Conn_01x03; PinHeader_1x03_P2.54mm_Vertical
LK5: Conn_02x04_Odd_Even; PinHeader_2x04_P2.54mm_Vertical
LK6: Conn_02x03_Odd_Even; PinHeader_2x03_P2.54mm_Vertical
P7: Conn_01x17; PinHeader_1x17_P2.54mm_Vertical
R1, R2, R3, R4, R5, R6, R7: 4k7; R_1206

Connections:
+3V3: LK4.3, R1.1, R2.1, R3.1, R4.1, R5.1, R6.1, R7.1; also elsewhere on the board
+5V: LK4.1; also elsewhere on the board
/PORTA0: P7.8; also elsewhere on the board
/PORTA1: P7.9; also elsewhere on the board
/PORTA2: P7.10; also elsewhere on the board
/PORTA3: P7.11; also elsewhere on the board
/PORTA4: P7.12; also elsewhere on the board
/PORTA5: P7.13; also elsewhere on the board
/PORTA6: P7.14; also elsewhere on the board
/PORTA7: P7.15; also elsewhere on the board
/PORTB1: P7.6; also elsewhere on the board
/PORTB2: P7.4; also elsewhere on the board
/PORTB3: P7.1; also elsewhere on the board
/PORTB6: P7.3; also elsewhere on the board
/PORTD1: P7.7; also elsewhere on the board
/PORTE7: P7.16; also elsewhere on the board
/PORTF0: LK5.1, R1.2; also elsewhere on the board
/PORTF1: LK5.3, R2.2; also elsewhere on the board
/PORTF2: LK5.5, R3.2; also elsewhere on the board
/PORTF3: LK5.7, R4.2; also elsewhere on the board
/PORTG9: LK6.1, R5.2; also elsewhere on the board
/PORTG10: LK6.3, R6.2; also elsewhere on the board
/PORTG11: LK6.5, R7.2; also elsewhere on the board
GND: C1.2, C2.2, LK5.2, LK5.4, LK5.6, LK5.8, LK6.2, LK6.4, LK6.6, P7.17; also elsewhere on the board
VCC_CPU: C1.1, C2.1, LK4.2; also elsewhere on the board

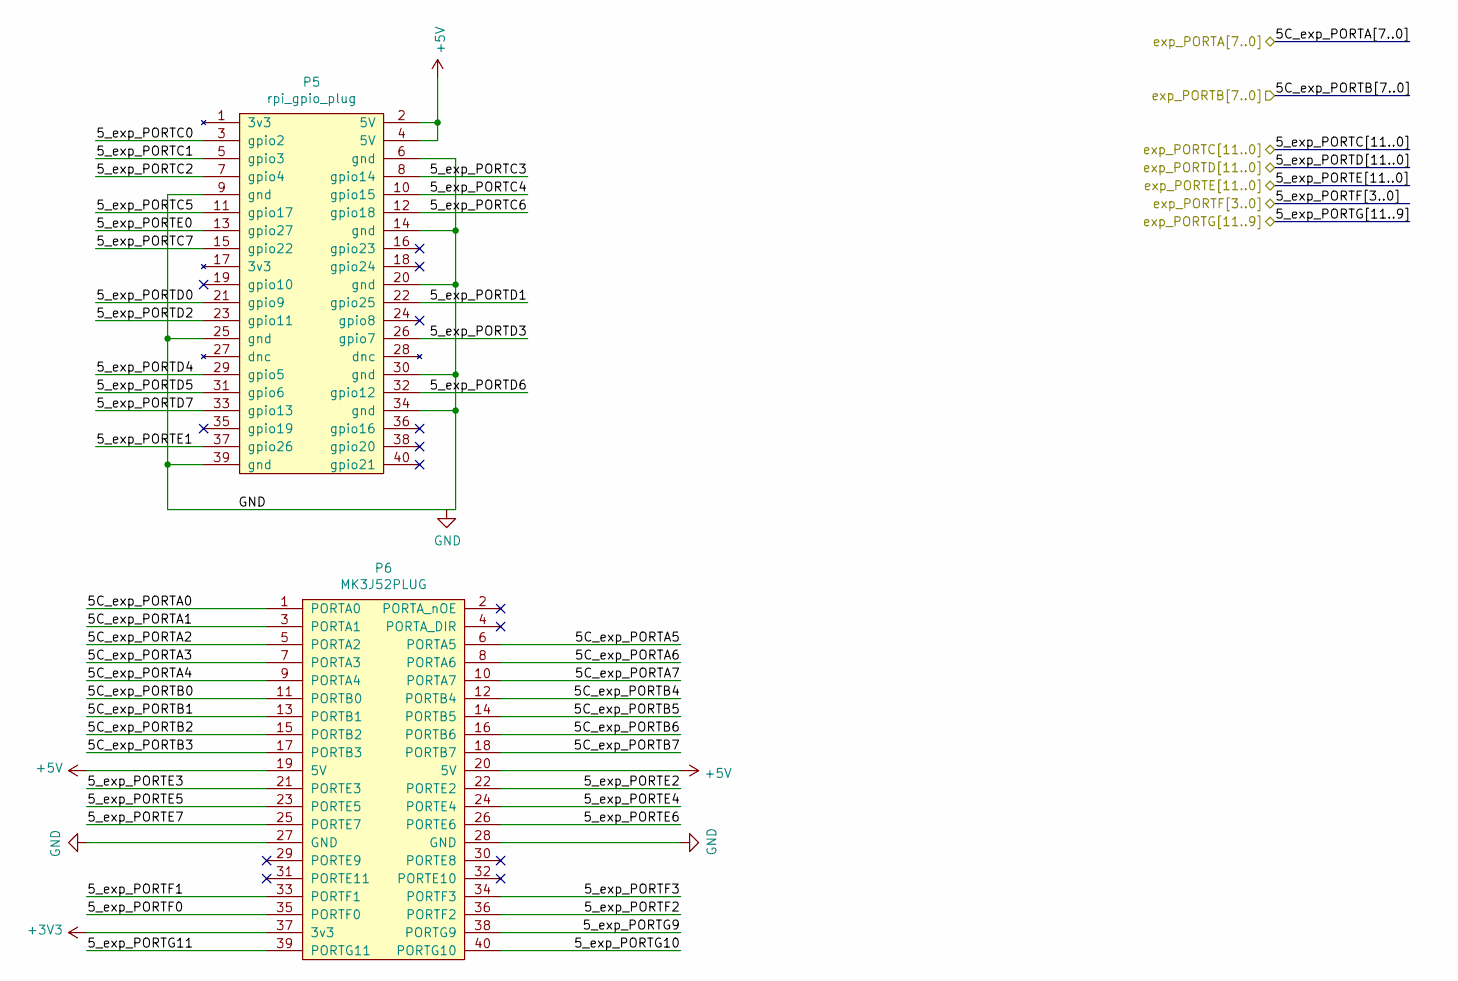
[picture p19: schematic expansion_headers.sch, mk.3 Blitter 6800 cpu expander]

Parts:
P5: rpi_gpio_plug; PinHeader_2x20_P2.54mm_Vertical_SMD-dom
P6: MK3J52PLUG; PinSocket_2x20_P2.54mm_Vertical_SMD-dom

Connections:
+3V3: P6.37 (3v3); also elsewhere on the board
+5V: P5.2 (5V), P5.4 (5V), P6.19 (5V), P6.20 (5V); also elsewhere on the board
/PORTA0: P6.1 (PORTA0); also elsewhere on the board
/PORTA1: P6.3 (PORTA1); also elsewhere on the board
/PORTA2: P6.5 (PORTA2); also elsewhere on the board
/PORTA3: P6.7 (PORTA3); also elsewhere on the board
/PORTA4: P6.9 (PORTA4); also elsewhere on the board
/PORTA5: P6.6 (PORTA5); also elsewhere on the board
/PORTA6: P6.8 (PORTA6); also elsewhere on the board
/PORTA7: P6.10 (PORTA7); also elsewhere on the board
/PORTB0: P6.11 (PORTB0); also elsewhere on the board
/PORTB1: P6.13 (PORTB1); also elsewhere on the board
/PORTB2: P6.15 (PORTB2); also elsewhere on the board
/PORTB3: P6.17 (PORTB3); also elsewhere on the board
/PORTB4: P6.12 (PORTB4); also elsewhere on the board
/PORTB5: P6.14 (PORTB5); also elsewhere on the board
/PORTB6: P6.16 (PORTB6); also elsewhere on the board
/PORTB7: P6.18 (PORTB7); also elsewhere on the board
/PORTC0: P5.3 (gpio2); also elsewhere on the board
/PORTC1: P5.5 (gpio3); also elsewhere on the board
/PORTC2: P5.7 (gpio4); also elsewhere on the board
/PORTC3: P5.8 (gpio14); also elsewhere on the board
/PORTC4: P5.10 (gpio15); also elsewhere on the board
/PORTC5: P5.11 (gpio17); also elsewhere on the board
/PORTC6: P5.12 (gpio18); also elsewhere on the board
/PORTC7: P5.15 (gpio22); also elsewhere on the board
/PORTD0: P5.21 (gpio9)
/PORTD1: P5.22 (gpio25); also elsewhere on the board
/PORTD2: P5.23 (gpio11)
/PORTD3: P5.26 (gpio7)
/PORTD4: P5.29 (gpio5)
/PORTD5: P5.31 (gpio6); also elsewhere on the board
/PORTD6: P5.32 (gpio12); also elsewhere on the board
/PORTD7: P5.33 (gpio13)
/PORTE0: P5.13 (gpio27); also elsewhere on the board
/PORTE1: P5.37 (gpio26); also elsewhere on the board
/PORTE2: P6.22 (PORTE2); also elsewhere on the board
/PORTE3: P6.21 (PORTE3); also elsewhere on the board
/PORTE4: P6.24 (PORTE4); also elsewhere on the board
/PORTE5: P6.23 (PORTE5); also elsewhere on the board
/PORTE6: P6.26 (PORTE6); also elsewhere on the board
/PORTE7: P6.25 (PORTE7); also elsewhere on the board
/PORTF0: P6.35 (PORTF0); also elsewhere on the board
/PORTF1: P6.33 (PORTF1); also elsewhere on the board
/PORTF2: P6.36 (PORTF2); also elsewhere on the board
/PORTF3: P6.34 (PORTF3); also elsewhere on the board
/PORTG9: P6.38 (PORTG9); also elsewhere on the board
/PORTG10: P6.40 (PORTG10); also elsewhere on the board
/PORTG11: P6.39 (PORTG11); also elsewhere on the board
GND: P5.6 (gnd), P5.9 (gnd), P5.14 (gnd), P5.20 (gnd), P5.25 (gnd), P5.30 (gnd), P5.34 (gnd), P5.39 (gnd), P6.27 (GND), P6.28 (GND); also elsewhere on the board

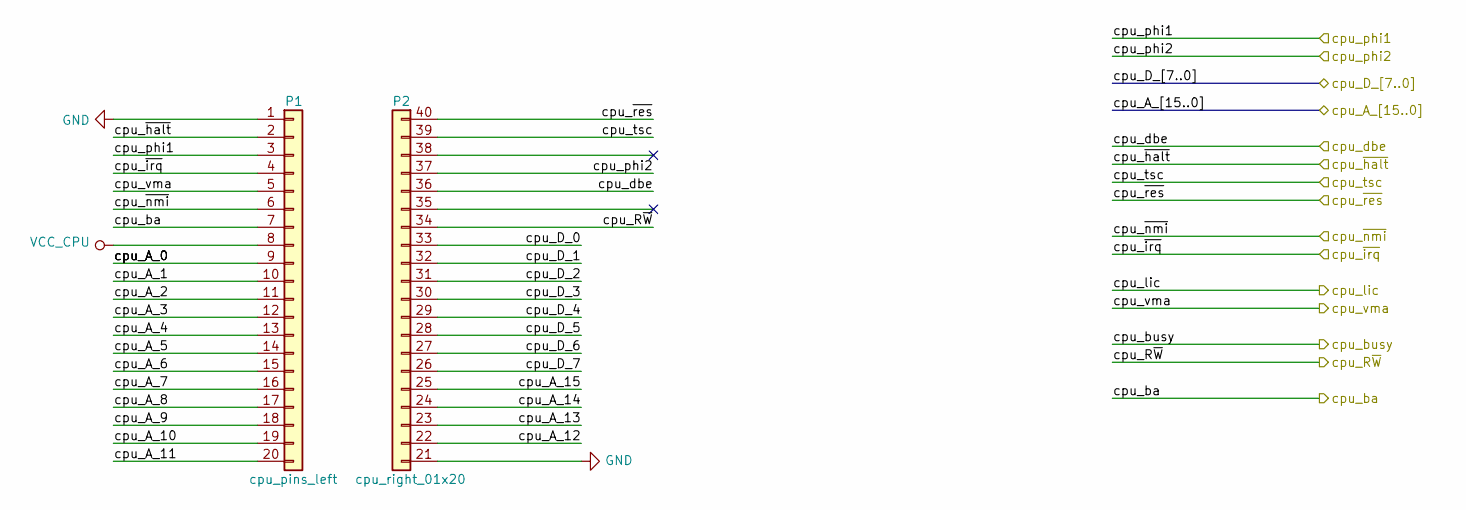
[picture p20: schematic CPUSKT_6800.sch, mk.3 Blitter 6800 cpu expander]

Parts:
P1: cpu_pins_left; PinSocket_1x20_P2.54mm_Vertical
P2: cpu_right_01x20; Pin_Header_Straight_1x20_Pitch2.54mm_21_40

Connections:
/PORTA0: P2.33; also elsewhere on the board
/PORTA1: P2.32; also elsewhere on the board
/PORTA2: P2.31; also elsewhere on the board
/PORTA3: P2.30; also elsewhere on the board
/PORTA4: P2.29; also elsewhere on the board
/PORTA5: P2.28; also elsewhere on the board
/PORTA6: P2.27; also elsewhere on the board
/PORTA7: P2.26; also elsewhere on the board
/PORTB0: P2.39; also elsewhere on the board
/PORTB1: P1.3; also elsewhere on the board
/PORTB2: P2.37; also elsewhere on the board
/PORTB3: P1.2; also elsewhere on the board
/PORTB4: P1.4; also elsewhere on the board
/PORTB5: P1.6; also elsewhere on the board
/PORTB6: P2.40; also elsewhere on the board
/PORTB7: P2.36; also elsewhere on the board
/PORTC0: P1.9; also elsewhere on the board
/PORTC1: P1.10; also elsewhere on the board
/PORTC2: P1.11; also elsewhere on the board
/PORTC3: P1.12; also elsewhere on the board
/PORTC4: P1.13; also elsewhere on the board
/PORTC5: P1.14; also elsewhere on the board
/PORTC6: P1.15; also elsewhere on the board
/PORTC7: P1.16; also elsewhere on the board
/PORTD1: P2.34; also elsewhere on the board
/PORTD5: P1.7; also elsewhere on the board
/PORTD6: P1.5; also elsewhere on the board
/PORTE0: P1.17; also elsewhere on the board
/PORTE1: P1.18; also elsewhere on the board
/PORTE2: P1.19; also elsewhere on the board
/PORTE3: P1.20; also elsewhere on the board
/PORTE4: P2.22; also elsewhere on the board
/PORTE5: P2.23; also elsewhere on the board
/PORTE6: P2.24; also elsewhere on the board
/PORTE7: P2.25; also elsewhere on the board
GND: P1.1, P2.21; also elsewhere on the board
VCC_CPU: P1.8; also elsewhere on the board

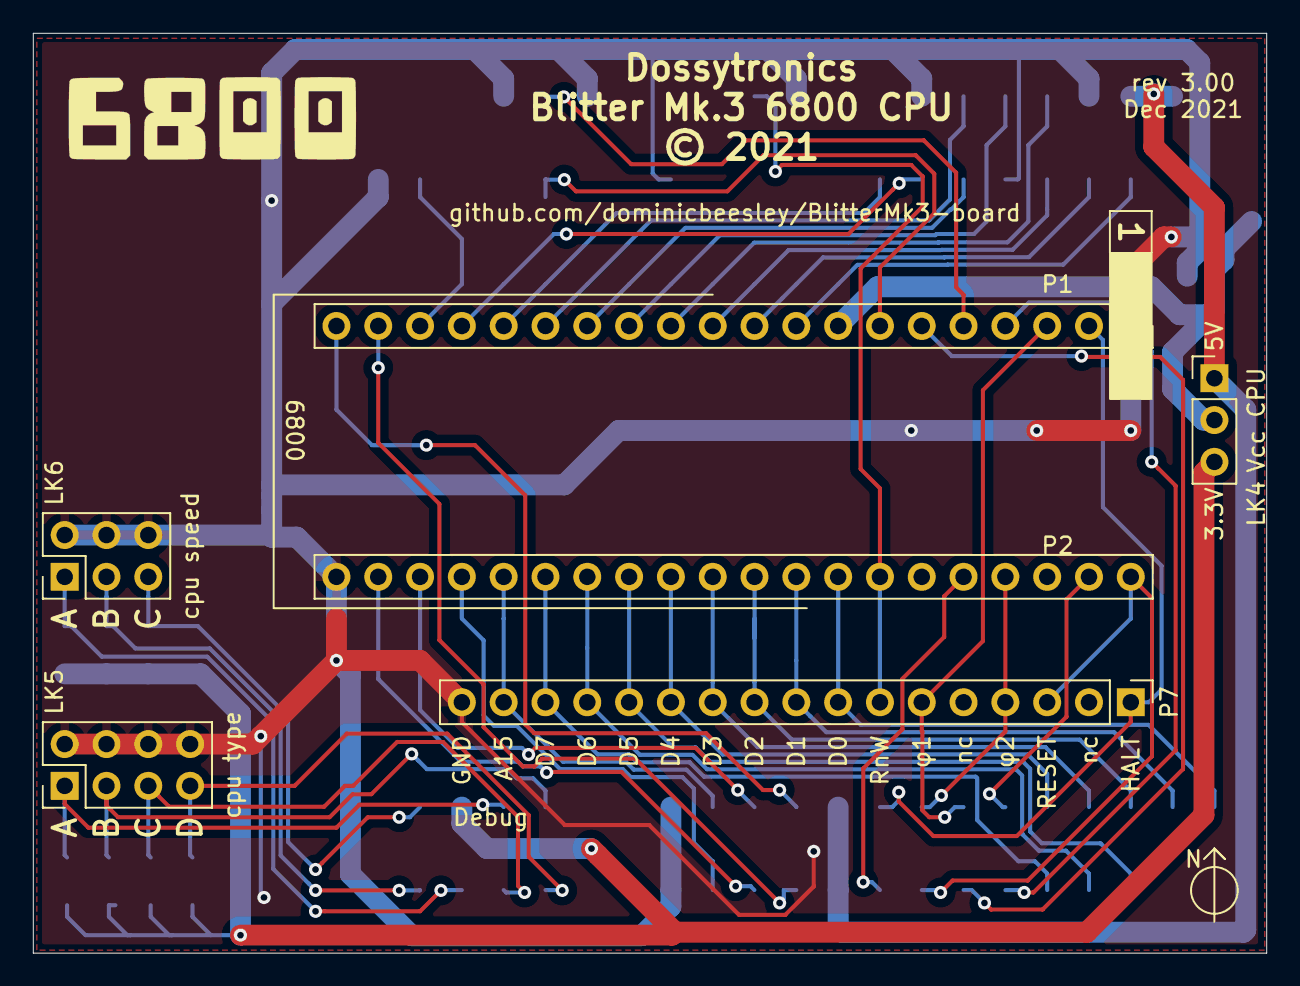
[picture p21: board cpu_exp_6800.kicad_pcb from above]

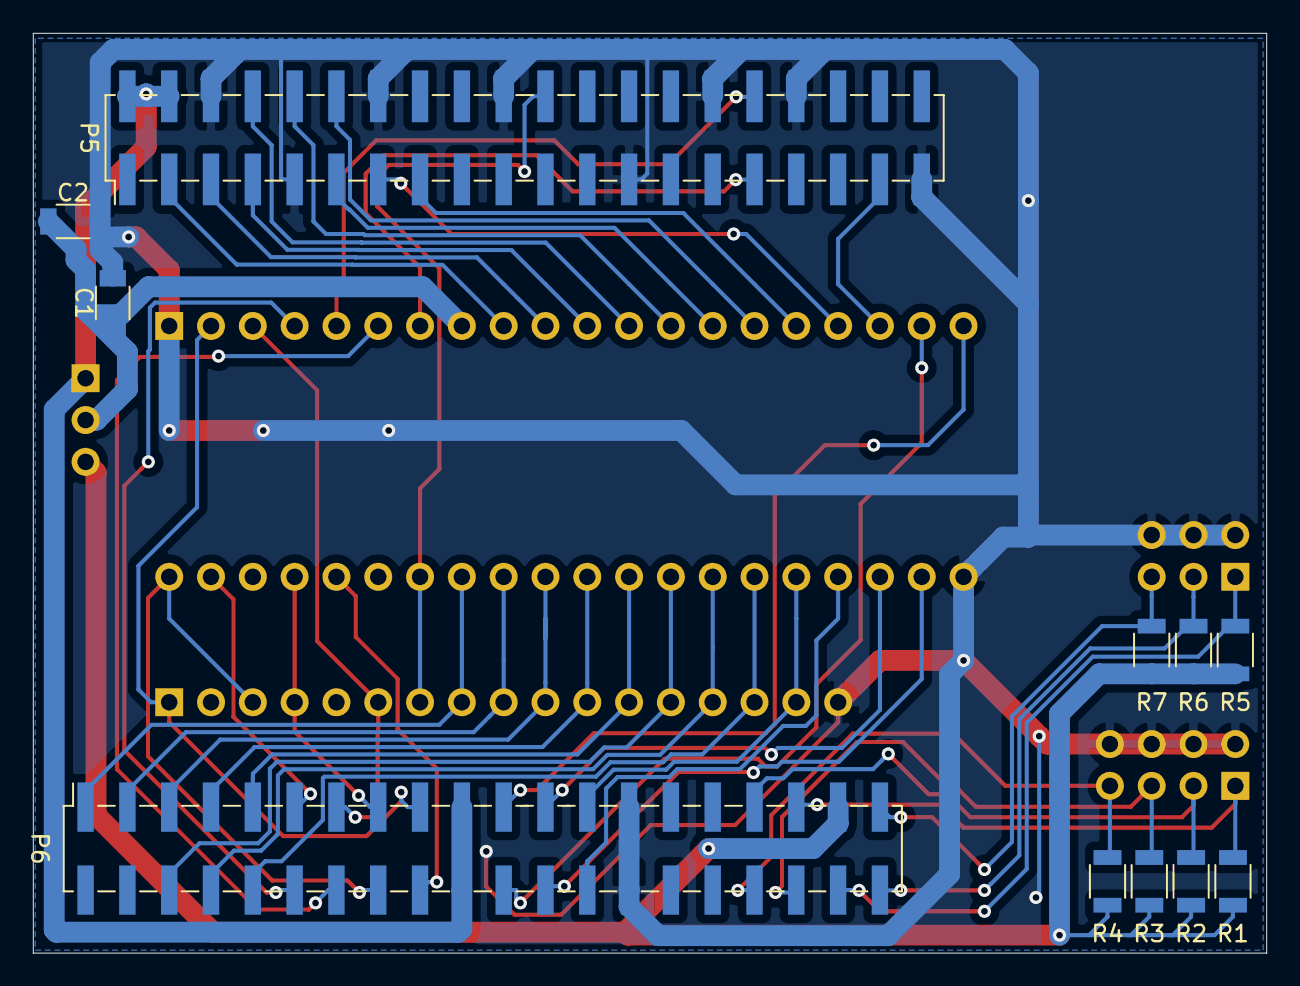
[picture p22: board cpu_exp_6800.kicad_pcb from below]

Board: 2 copper layers, 74.9 x 55.9 mm, 17 parts (11 on the bottom side), 46 nets.

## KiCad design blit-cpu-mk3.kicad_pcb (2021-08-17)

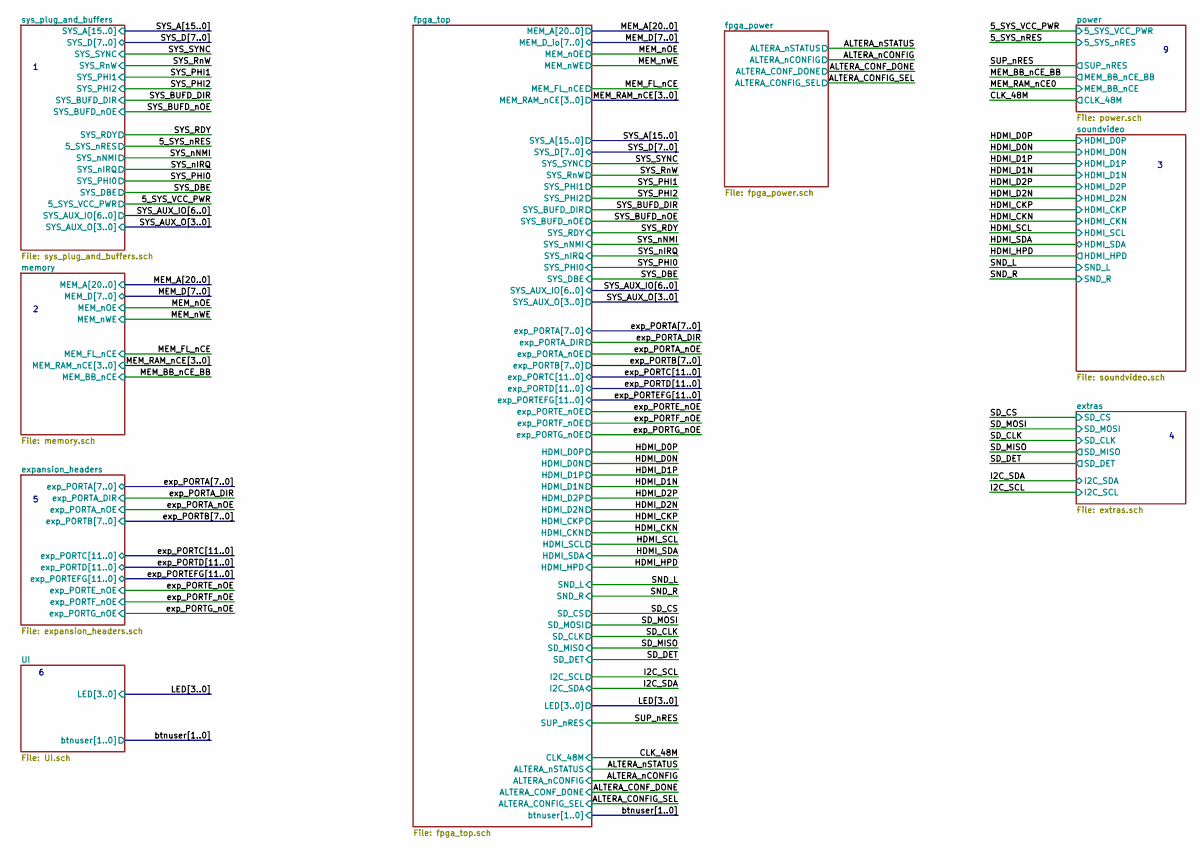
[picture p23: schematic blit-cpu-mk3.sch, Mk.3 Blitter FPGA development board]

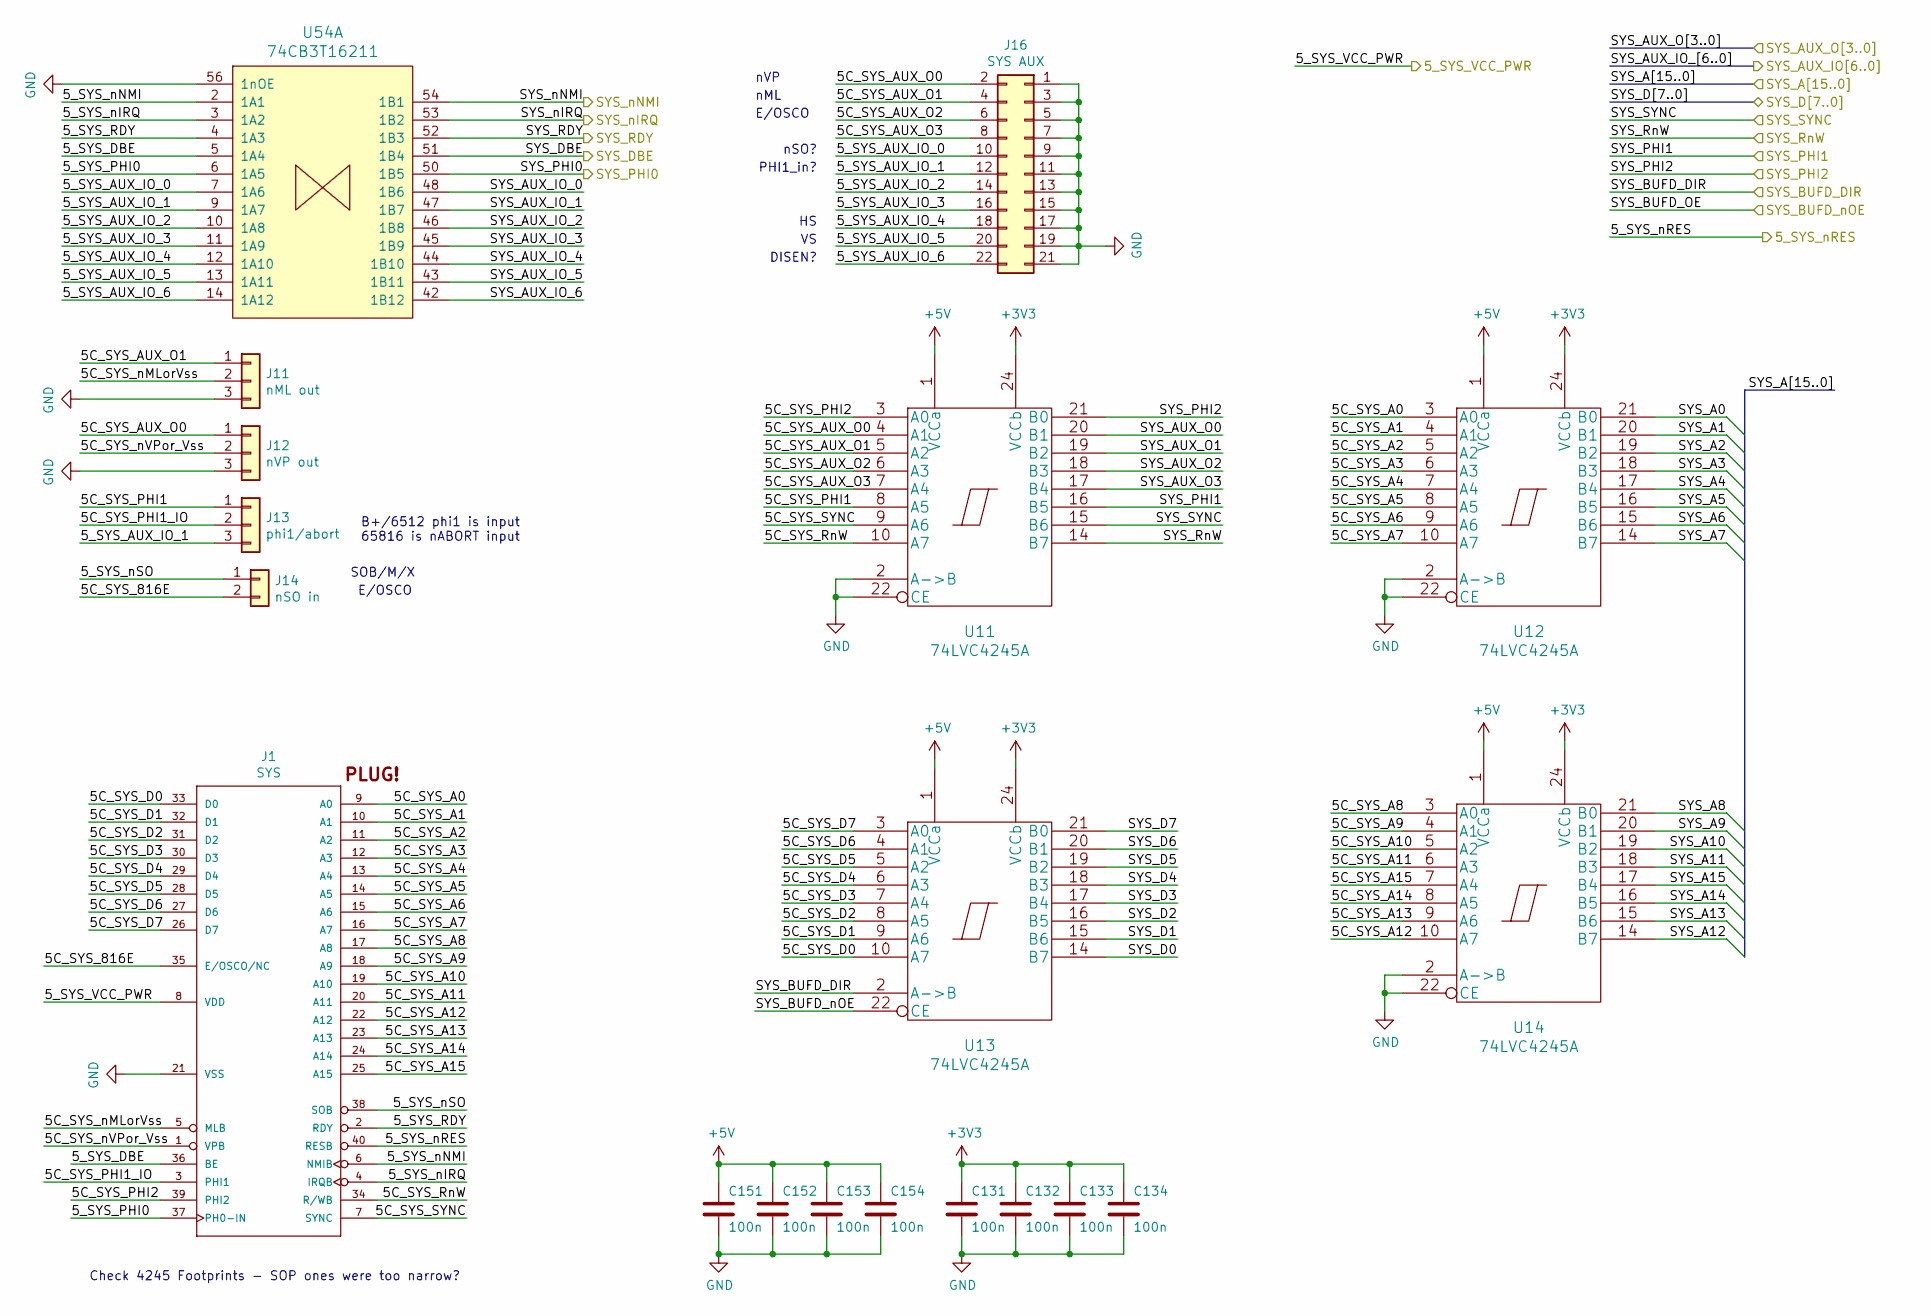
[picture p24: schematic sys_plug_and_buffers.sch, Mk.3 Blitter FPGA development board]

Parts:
C131, C132, C133, C134, C151, C152, C153, C154: 100n; C_0805
J1: SYS; DIP-40_W16.51mm_SMDSocket_LongPads-flipped
J11: nML out; PinHeader_1x03_P2.54mm_Vertical
J12: nVP out; PinHeader_1x03_P2.54mm_Vertical
J13: phi1/abort; PinHeader_1x03_P2.54mm_Vertical
J14: nSO in; PinHeader_1x02_P2.54mm_Vertical
J16: SYS AUX; PinHeader_2x11_P2.54mm_Vertical
U11, U12, U13, U14: 74LVC4245A; TSSOP-24_4.4x7.8mm_Pitch0.65mm
U54: 74CB3T16211; TSSOP-56_6.1x14mm_Pitch0.5mm

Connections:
+3V3: C131.1, C132.1, C133.1, C134.1, U11.23 (VCCb), U11.24 (VCCb), U12.23 (VCCb), U12.24 (VCCb), U13.23 (VCCb), U13.24 (VCCb), U14.23 (VCCb), U14.24 (VCCb); also elsewhere on the board
+5V: C151.1, C152.1, C153.1, C154.1, U11.1 (VCCa), U12.1 (VCCa), U13.1 (VCCa), U14.1 (VCCa); also elsewhere on the board
/5_SYS_VCC_PWR: J1.8 (VDD); also elsewhere on the board
/5_SYS_nRES: J1.40 (RESB); also elsewhere on the board
/SYS_BUFD_DIR: U13.2 (A->B); also elsewhere on the board
/SYS_BUFD_nOE: U13.22 (CE); also elsewhere on the board
/SYS_DBE: U54.51 (1B4); also elsewhere on the board
/SYS_PHI0: U54.50 (1B5); also elsewhere on the board
/SYS_PHI1: U11.16 (B5); also elsewhere on the board
/SYS_PHI2: U11.21 (B0); also elsewhere on the board
/SYS_RDY: U54.52 (1B3); also elsewhere on the board
/SYS_RnW: U11.14 (B7); also elsewhere on the board
/SYS_SYNC: U11.15 (B6); also elsewhere on the board
/SYS_nIRQ: U54.53 (1B2); also elsewhere on the board
/SYS_nNMI: U54.54 (1B1); also elsewhere on the board
/sys_plug_and_buffers/5C_SYS_816E: J1.35 (E/OSCO/NC), J14.2
/sys_plug_and_buffers/5C_SYS_A0: J1.9 (A0), U12.3 (A0)
/sys_plug_and_buffers/5C_SYS_A1: J1.10 (A1), U12.4 (A1)
/sys_plug_and_buffers/5C_SYS_A2: J1.11 (A2), U12.5 (A2)
/sys_plug_and_buffers/5C_SYS_A3: J1.12 (A3), U12.6 (A3)
/sys_plug_and_buffers/5C_SYS_A4: J1.13 (A4), U12.7 (A4)
/sys_plug_and_buffers/5C_SYS_A5: J1.14 (A5), U12.8 (A5)
/sys_plug_and_buffers/5C_SYS_A6: J1.15 (A6), U12.9 (A6)
/sys_plug_and_buffers/5C_SYS_A7: J1.16 (A7), U12.10 (A7)
/sys_plug_and_buffers/5C_SYS_A8: J1.17 (A8), U14.3 (A0)
/sys_plug_and_buffers/5C_SYS_A9: J1.18 (A9), U14.4 (A1)
/sys_plug_and_buffers/5C_SYS_A10: J1.19 (A10), U14.5 (A2)
/sys_plug_and_buffers/5C_SYS_A11: J1.20 (A11), U14.6 (A3)
/sys_plug_and_buffers/5C_SYS_A12: J1.22 (A12), U14.10 (A7)
/sys_plug_and_buffers/5C_SYS_A13: J1.23 (A13), U14.9 (A6)
/sys_plug_and_buffers/5C_SYS_A14: J1.24 (A14), U14.8 (A5)
/sys_plug_and_buffers/5C_SYS_A15: J1.25 (A15), U14.7 (A4)
/sys_plug_and_buffers/5C_SYS_AUX_O0: J12.1, J16.2, U11.4 (A1)
/sys_plug_and_buffers/5C_SYS_AUX_O1: J11.1, J16.4, U11.5 (A2)
/sys_plug_and_buffers/5C_SYS_AUX_O2: J16.6, U11.6 (A3)
/sys_plug_and_buffers/5C_SYS_AUX_O3: J16.8, U11.7 (A4)
/sys_plug_and_buffers/5C_SYS_D0: J1.33 (D0), U13.10 (A7)
/sys_plug_and_buffers/5C_SYS_D1: J1.32 (D1), U13.9 (A6)
/sys_plug_and_buffers/5C_SYS_D2: J1.31 (D2), U13.8 (A5)
/sys_plug_and_buffers/5C_SYS_D3: J1.30 (D3), U13.7 (A4)
/sys_plug_and_buffers/5C_SYS_D4: J1.29 (D4), U13.6 (A3)
/sys_plug_and_buffers/5C_SYS_D5: J1.28 (D5), U13.5 (A2)
/sys_plug_and_buffers/5C_SYS_D6: J1.27 (D6), U13.4 (A1)
/sys_plug_and_buffers/5C_SYS_D7: J1.26 (D7), U13.3 (A0)
/sys_plug_and_buffers/5C_SYS_PHI1: J13.1, U11.8 (A5)
/sys_plug_and_buffers/5C_SYS_PHI1_IO: J1.3 (PHI1), J13.2
/sys_plug_and_buffers/5C_SYS_PHI2: J1.39 (PHI2), U11.3 (A0)
/sys_plug_and_buffers/5C_SYS_RnW: J1.34 (R/WB), U11.10 (A7)
/sys_plug_and_buffers/5C_SYS_SYNC: J1.7 (SYNC), U11.9 (A6)
/sys_plug_and_buffers/5C_SYS_nMLorVss: J1.5 (MLB), J11.2
/sys_plug_and_buffers/5C_SYS_nVPor_Vss: J1.1 (VPB), J12.2
/sys_plug_and_buffers/5_SYS_AUX_IO_0: J16.10, U54.7 (1A6)
/sys_plug_and_buffers/5_SYS_AUX_IO_1: J13.3, J16.12, U54.9 (1A7)
/sys_plug_and_buffers/5_SYS_AUX_IO_2: J16.14, U54.10 (1A8)
/sys_plug_and_buffers/5_SYS_AUX_IO_3: J16.16, U54.11 (1A9)
/sys_plug_and_buffers/5_SYS_AUX_IO_4: J16.18, U54.12 (1A10)
/sys_plug_and_buffers/5_SYS_AUX_IO_5: J16.20, U54.13 (1A11)
/sys_plug_and_buffers/5_SYS_AUX_IO_6: J16.22, U54.14 (1A12)
/sys_plug_and_buffers/5_SYS_DBE: J1.36 (BE), U54.5 (1A4)
/sys_plug_and_buffers/5_SYS_PHI0: J1.37 (PH0-IN), U54.6 (1A5)
/sys_plug_and_buffers/5_SYS_RDY: J1.2 (RDY), U54.4 (1A3)
/sys_plug_and_buffers/5_SYS_nIRQ: J1.4 (IRQB), U54.3 (1A2)
/sys_plug_and_buffers/5_SYS_nNMI: J1.6 (NMIB), U54.2 (1A1)
/sys_plug_and_buffers/5_SYS_nSO: J1.38 (SOB), J14.1
/sys_plug_and_buffers/SYS_A0: U12.21 (B0); also elsewhere on the board
/sys_plug_and_buffers/SYS_A1: U12.20 (B1); also elsewhere on the board
/sys_plug_and_buffers/SYS_A2: U12.19 (B2); also elsewhere on the board
/sys_plug_and_buffers/SYS_A3: U12.18 (B3); also elsewhere on the board
/sys_plug_and_buffers/SYS_A4: U12.17 (B4); also elsewhere on the board
/sys_plug_and_buffers/SYS_A5: U12.16 (B5); also elsewhere on the board
/sys_plug_and_buffers/SYS_A6: U12.15 (B6); also elsewhere on the board
/sys_plug_and_buffers/SYS_A7: U12.14 (B7); also elsewhere on the board
/sys_plug_and_buffers/SYS_A8: U14.21 (B0); also elsewhere on the board
/sys_plug_and_buffers/SYS_A9: U14.20 (B1); also elsewhere on the board
/sys_plug_and_buffers/SYS_A10: U14.19 (B2); also elsewhere on the board
/sys_plug_and_buffers/SYS_A11: U14.18 (B3); also elsewhere on the board
/sys_plug_and_buffers/SYS_A12: U14.14 (B7); also elsewhere on the board
/sys_plug_and_buffers/SYS_A13: U14.15 (B6); also elsewhere on the board
/sys_plug_and_buffers/SYS_A14: U14.16 (B5); also elsewhere on the board
/sys_plug_and_buffers/SYS_A15: U14.17 (B4); also elsewhere on the board
/sys_plug_and_buffers/SYS_AUX_IO_0: U54.48 (1B6); also elsewhere on the board
/sys_plug_and_buffers/SYS_AUX_IO_1: U54.47 (1B7); also elsewhere on the board
/sys_plug_and_buffers/SYS_AUX_IO_2: U54.46 (1B8); also elsewhere on the board
/sys_plug_and_buffers/SYS_AUX_IO_3: U54.45 (1B9); also elsewhere on the board
/sys_plug_and_buffers/SYS_AUX_IO_4: U54.44 (1B10); also elsewhere on the board
/sys_plug_and_buffers/SYS_AUX_IO_5: U54.43 (1B11); also elsewhere on the board
/sys_plug_and_buffers/SYS_AUX_IO_6: U54.42 (1B12); also elsewhere on the board
/sys_plug_and_buffers/SYS_AUX_O0: U11.20 (B1); also elsewhere on the board
/sys_plug_and_buffers/SYS_AUX_O1: U11.19 (B2); also elsewhere on the board
/sys_plug_and_buffers/SYS_AUX_O2: U11.18 (B3); also elsewhere on the board
/sys_plug_and_buffers/SYS_AUX_O3: U11.17 (B4); also elsewhere on the board
/sys_plug_and_buffers/SYS_D0: U13.14 (B7); also elsewhere on the board
/sys_plug_and_buffers/SYS_D1: U13.15 (B6); also elsewhere on the board
/sys_plug_and_buffers/SYS_D2: U13.16 (B5); also elsewhere on the board
/sys_plug_and_buffers/SYS_D3: U13.17 (B4); also elsewhere on the board
/sys_plug_and_buffers/SYS_D4: U13.18 (B3); also elsewhere on the board
/sys_plug_and_buffers/SYS_D5: U13.19 (B2); also elsewhere on the board
/sys_plug_and_buffers/SYS_D6: U13.20 (B1); also elsewhere on the board
/sys_plug_and_buffers/SYS_D7: U13.21 (B0); also elsewhere on the board

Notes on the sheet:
B+/6512 phi1 is input 65816 is nABORT input
DISEN?
PHI1_in?
SOB/M/X
nSO?
nML
nVP
E/OSCO
Check 4245 Footprints - SOP ones were too narrow?

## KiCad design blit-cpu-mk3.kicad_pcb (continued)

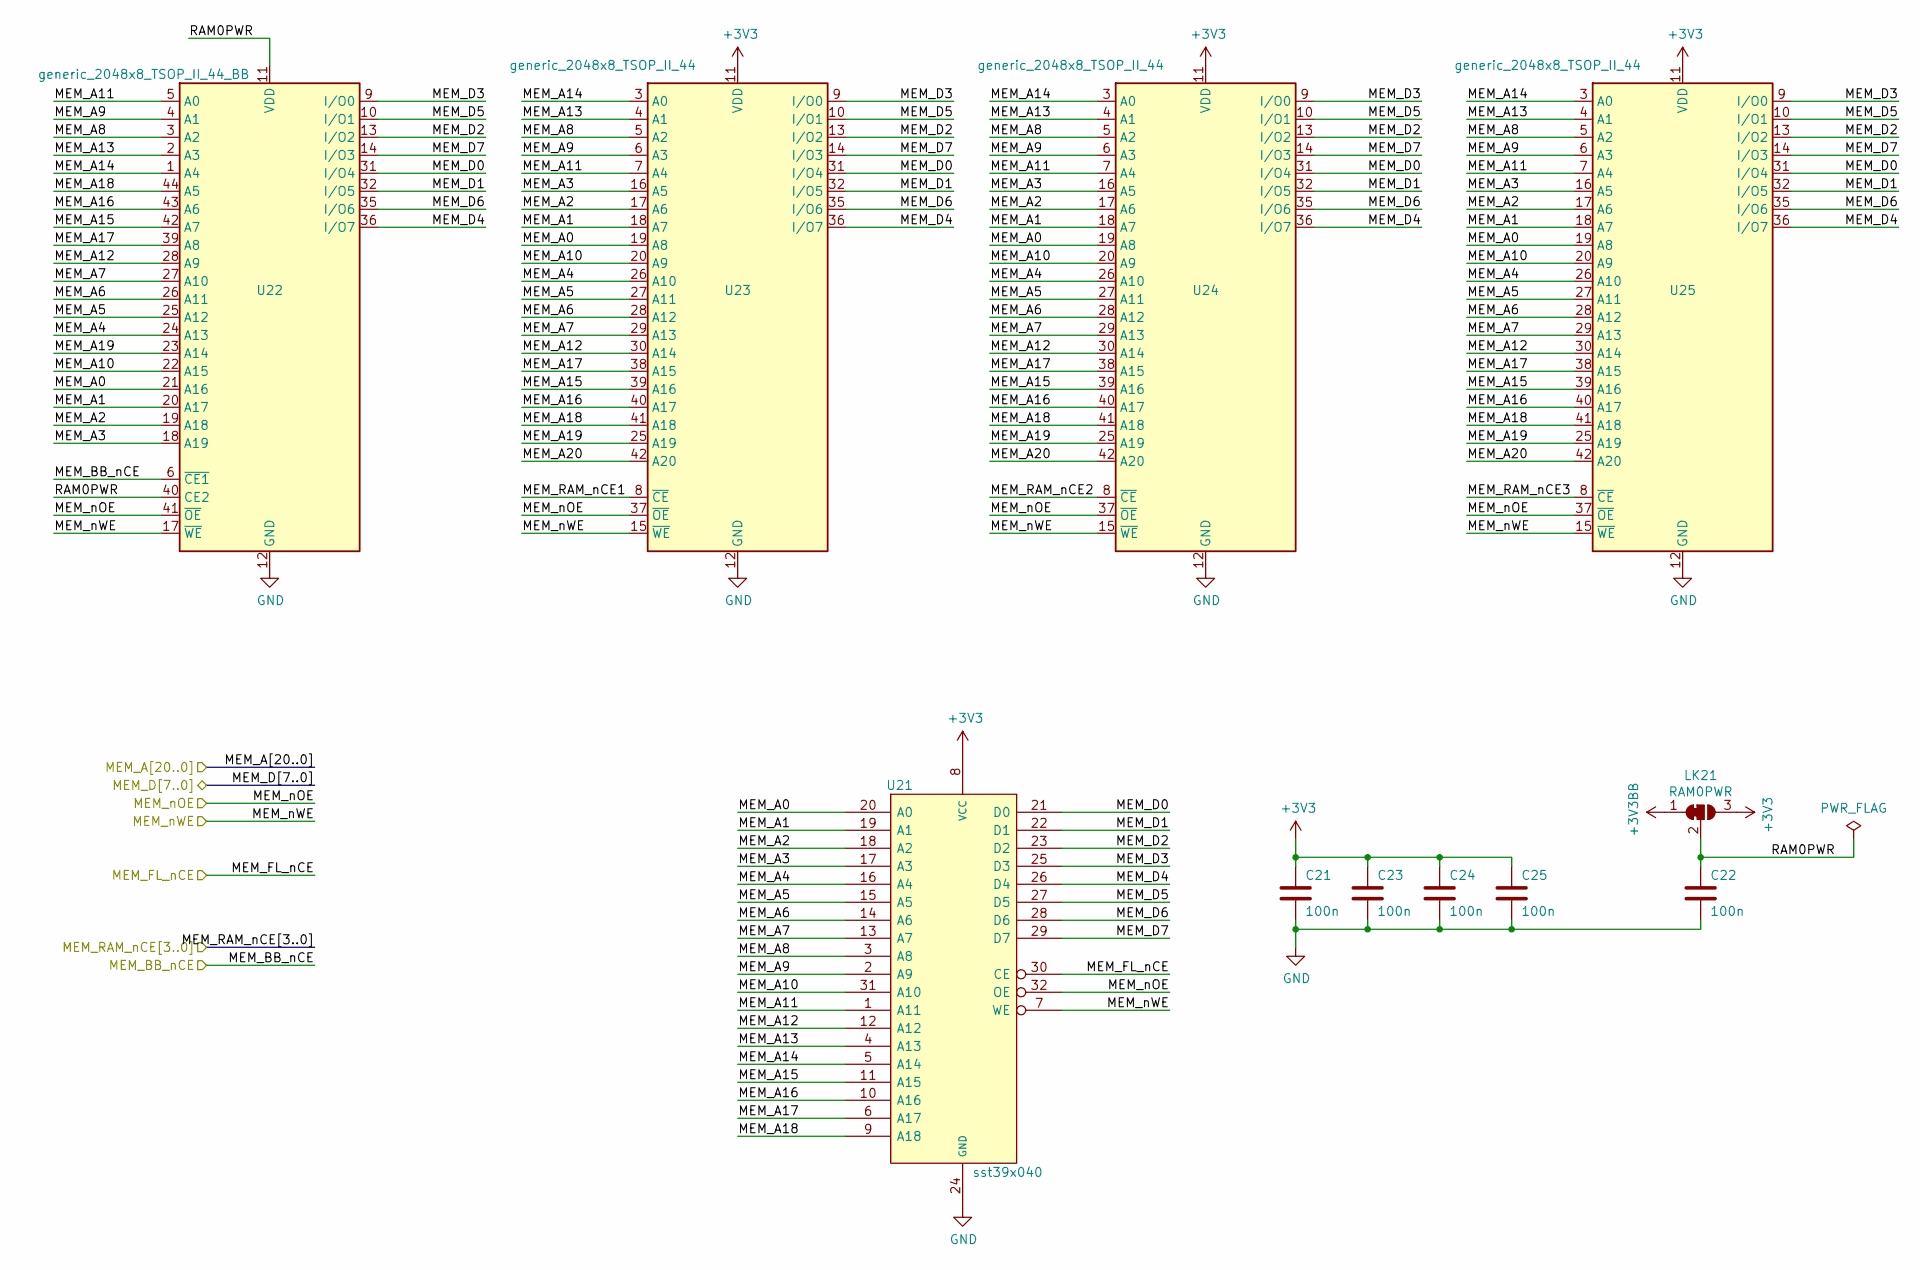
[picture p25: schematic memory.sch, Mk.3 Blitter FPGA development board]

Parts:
C21, C22, C23, C24, C25: 100n; C_0805
LK21: RAM0PWR; SolderJumper-3_P1.3mm_Bridged12_RoundedPad1.0x1.5mm
U21: sst39x040; TSOP-F-32_14x8mm_Pitch0.5mm
U22: generic_2048x8_TSOP_II_44_BB; TSOP-II-44_10.16x18.41mm_P0.8mm
U23, U24, U25: generic_2048x8_TSOP_II_44; TSOP-II-44_10.16x18.41mm_P0.8mm

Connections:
+3V3: C21.1, C23.1, C24.1, C25.1, LK21.3 (B), U21.8 (VCC), U23.11 (VDD), U23.33 (VDD), U24.11 (VDD), U24.33 (VDD), U25.11 (VDD), U25.33 (VDD); also elsewhere on the board
+3V3BB: LK21.1 (A); also elsewhere on the board
/MEM_BB_nCE_BB: U22.6 (~CE1); also elsewhere on the board
/MEM_FL_nCE: U21.30 (CE); also elsewhere on the board
/MEM_nOE: U21.32 (OE), U22.41 (~OE), U23.37 (~OE), U24.37 (~OE), U25.37 (~OE); also elsewhere on the board
/MEM_nWE: U21.7 (WE), U22.17 (~WE), U23.15 (~WE), U24.15 (~WE), U25.15 (~WE); also elsewhere on the board
/memory/MEM_A0: U21.20 (A0), U22.21 (A16), U23.19 (A8), U24.19 (A8), U25.19 (A8); also elsewhere on the board
/memory/MEM_A1: U21.19 (A1), U22.20 (A17), U23.18 (A7), U24.18 (A7), U25.18 (A7); also elsewhere on the board
/memory/MEM_A2: U21.18 (A2), U22.19 (A18), U23.17 (A6), U24.17 (A6), U25.17 (A6); also elsewhere on the board
/memory/MEM_A3: U21.17 (A3), U22.18 (A19), U23.16 (A5), U24.16 (A5), U25.16 (A5); also elsewhere on the board
/memory/MEM_A4: U21.16 (A4), U22.24 (A13), U23.26 (A10), U24.26 (A10), U25.26 (A10); also elsewhere on the board
/memory/MEM_A5: U21.15 (A5), U22.25 (A12), U23.27 (A11), U24.27 (A11), U25.27 (A11); also elsewhere on the board
/memory/MEM_A6: U21.14 (A6), U22.26 (A11), U23.28 (A12), U24.28 (A12), U25.28 (A12); also elsewhere on the board
/memory/MEM_A7: U21.13 (A7), U22.27 (A10), U23.29 (A13), U24.29 (A13), U25.29 (A13); also elsewhere on the board
/memory/MEM_A8: U21.3 (A8), U22.3 (A2), U23.5 (A2), U24.5 (A2), U25.5 (A2); also elsewhere on the board
/memory/MEM_A9: U21.2 (A9), U22.4 (A1), U23.6 (A3), U24.6 (A3), U25.6 (A3); also elsewhere on the board
/memory/MEM_A10: U21.31 (A10), U22.22 (A15), U23.20 (A9), U24.20 (A9), U25.20 (A9); also elsewhere on the board
/memory/MEM_A11: U21.1 (A11), U22.5 (A0), U23.7 (A4), U24.7 (A4), U25.7 (A4); also elsewhere on the board
/memory/MEM_A12: U21.12 (A12), U22.28 (A9), U23.30 (A14), U24.30 (A14), U25.30 (A14); also elsewhere on the board
/memory/MEM_A13: U21.4 (A13), U22.2 (A3), U23.4 (A1), U24.4 (A1), U25.4 (A1); also elsewhere on the board
/memory/MEM_A14: U21.5 (A14), U22.1 (A4), U23.3 (A0), U24.3 (A0), U25.3 (A0); also elsewhere on the board
/memory/MEM_A15: U21.11 (A15), U22.42 (A7), U23.39 (A16), U24.39 (A16), U25.39 (A16); also elsewhere on the board
/memory/MEM_A16: U21.10 (A16), U22.43 (A6), U23.40 (A17), U24.40 (A17), U25.40 (A17); also elsewhere on the board
/memory/MEM_A17: U21.6 (A17), U22.39 (A8), U23.38 (A15), U24.38 (A15), U25.38 (A15); also elsewhere on the board
/memory/MEM_A18: U21.9 (A18), U22.44 (A5), U23.41 (A18), U24.41 (A18), U25.41 (A18); also elsewhere on the board
/memory/MEM_A19: U22.23 (A14), U23.25 (A19), U24.25 (A19), U25.25 (A19); also elsewhere on the board
/memory/MEM_A20: U23.42 (A20), U24.42 (A20), U25.42 (A20); also elsewhere on the board
/memory/MEM_D0: U21.21 (D0), U22.31 (I/O4), U23.31 (I/O4), U24.31 (I/O4), U25.31 (I/O4); also elsewhere on the board
/memory/MEM_D1: U21.22 (D1), U22.32 (I/O5), U23.32 (I/O5), U24.32 (I/O5), U25.32 (I/O5); also elsewhere on the board
/memory/MEM_D2: U21.23 (D2), U22.13 (I/O2), U23.13 (I/O2), U24.13 (I/O2), U25.13 (I/O2); also elsewhere on the board
/memory/MEM_D3: U21.25 (D3), U22.9 (I/O0), U23.9 (I/O0), U24.9 (I/O0), U25.9 (I/O0); also elsewhere on the board
/memory/MEM_D4: U21.26 (D4), U22.36 (I/O7), U23.36 (I/O7), U24.36 (I/O7), U25.36 (I/O7); also elsewhere on the board
/memory/MEM_D5: U21.27 (D5), U22.10 (I/O1), U23.10 (I/O1), U24.10 (I/O1), U25.10 (I/O1); also elsewhere on the board
/memory/MEM_D6: U21.28 (D6), U22.35 (I/O6), U23.35 (I/O6), U24.35 (I/O6), U25.35 (I/O6); also elsewhere on the board
/memory/MEM_D7: U21.29 (D7), U22.14 (I/O3), U23.14 (I/O3), U24.14 (I/O3), U25.14 (I/O3); also elsewhere on the board
/memory/MEM_RAM_nCE1: U23.8 (~CE); also elsewhere on the board
/memory/MEM_RAM_nCE2: U24.8 (~CE); also elsewhere on the board
/memory/MEM_RAM_nCE3: U25.8 (~CE); also elsewhere on the board
/memory/RAM0PWR: C22.1, LK21.2 (C), U22.11 (VDD), U22.33 (VDD), U22.40 (CE2)

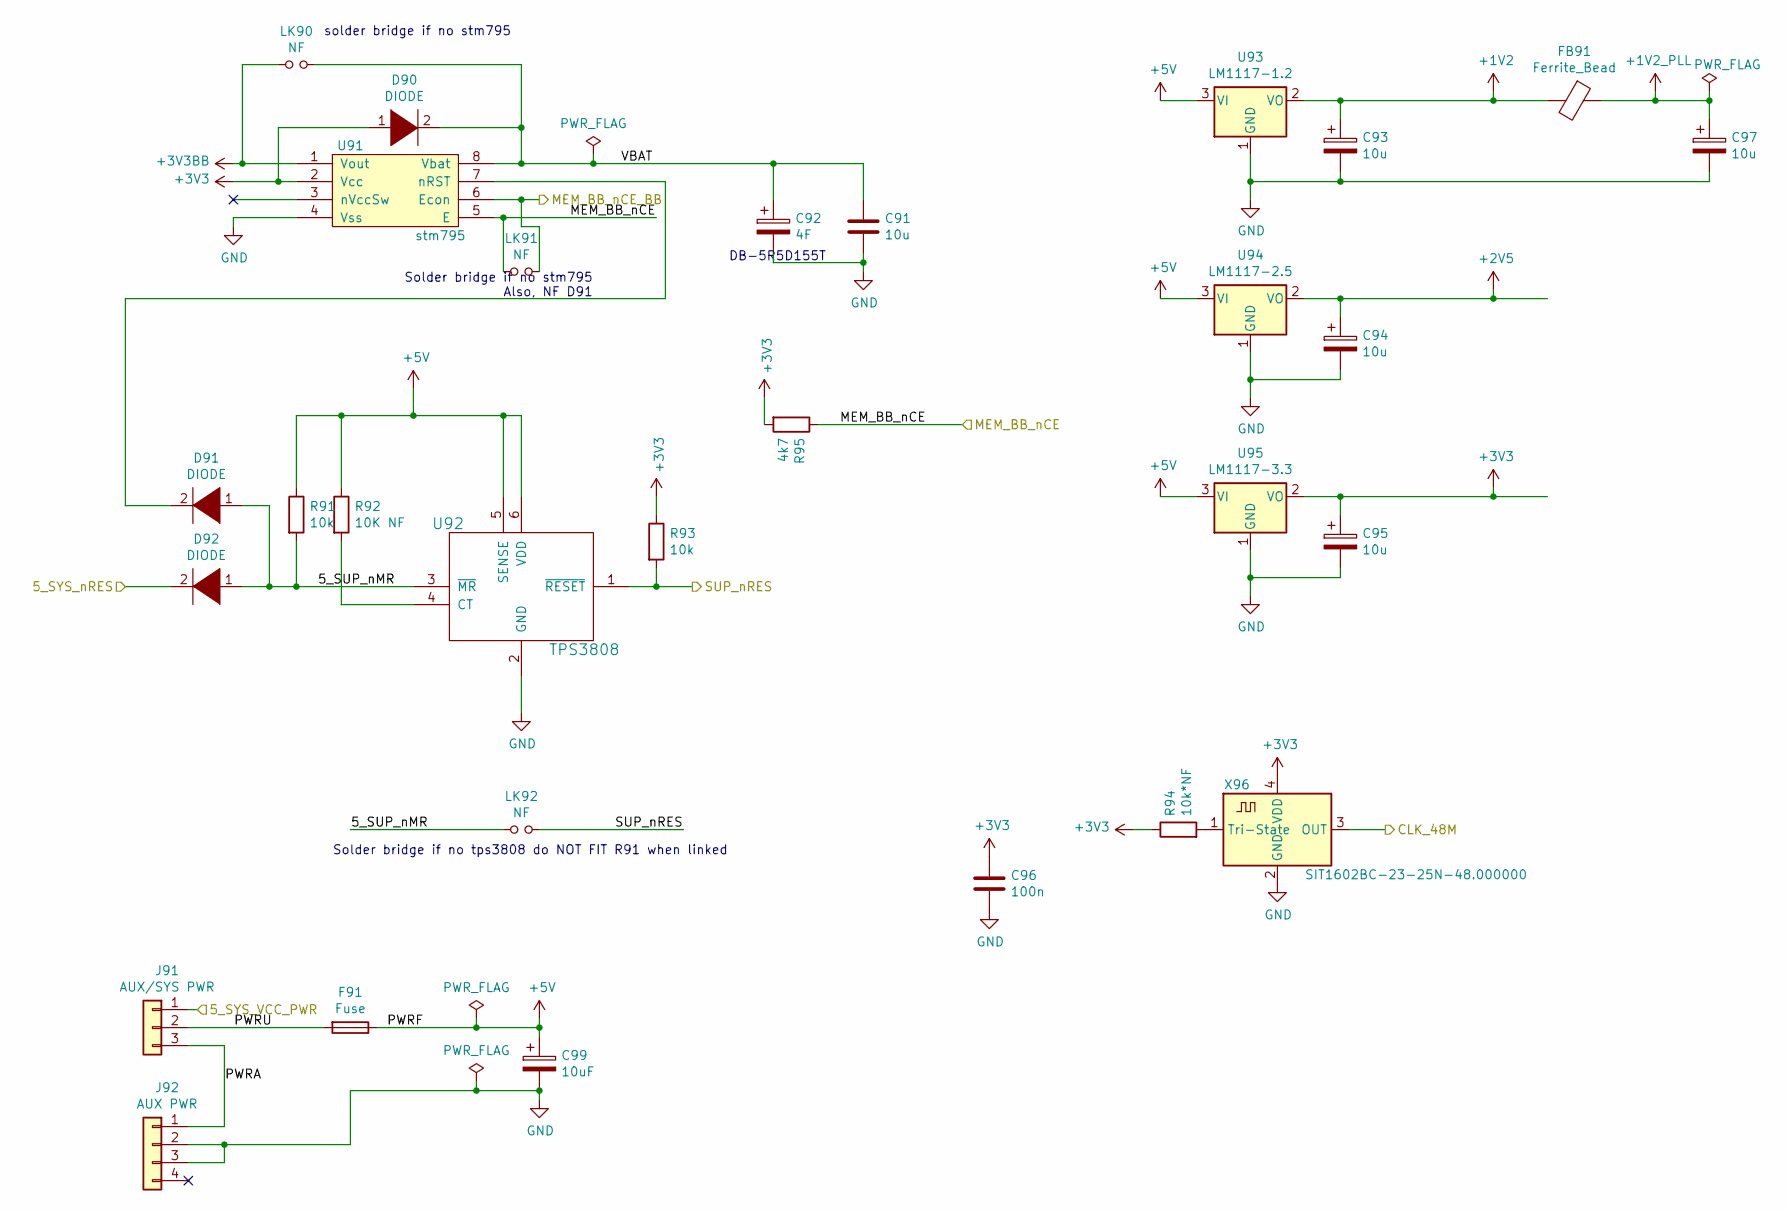
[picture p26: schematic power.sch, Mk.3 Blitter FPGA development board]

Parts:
C91, C93, C94, C95, C97: 10u; C_0805
C92: 4F; CP_Radial_D21.5mm_P5.00mmP11.5mm
C96: 100n; C_0805
C99: 10uF; C_0805
D90, D91, D92: DIODE; D_SOT-23_BAT54
F91: Fuse; R_1812
FB91: Ferrite_Bead; R_0402
J91: AUX/SYS PWR; PinHeader_1x03_P2.54mm_Vertical
J92: AUX PWR; Molex_KK-6410-04_04x2.54mm_Straight
LK90, LK91, LK92: NF; SolderJumper-2_P1.3mm_Open_RoundedPad1.0x1.5mm-domsmallctyd
R91, R93: 10k; R_0805
R92: 10K NF; R_0805
R94: 10k*NF; R_0805
R95: 4k7; R_0805
U91: stm795; SOIC-8_3.9x4.9mm_Pitch1.27mm
U92: TPS3808; SOT-23-6
U93: LM1117-1.2; SOT-223-3_TabPin2
U94: LM1117-2.5; SOT-223-3_TabPin2
U95: LM1117-3.3; SOT-223-3_TabPin2
X96: SIT1602BC-23-25N-48.000000; Oscillator_SMD_SiT1602-4pin_3.2x2.5mm

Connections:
+1V2: C93.1, FB91.2, U93.2 (VO); also elsewhere on the board
+1V2_PLL: C97.1, FB91.1; also elsewhere on the board
+2V5: C94.1, U94.2 (VO); also elsewhere on the board
+3V3: C95.1, C96.1, D90.1 (K), R93.1, R94.1, R95.2, U91.2 (Vcc), U95.2 (VO), X96.4 (VDD); also elsewhere on the board
+3V3BB: LK90.1, U91.1 (Vout); also elsewhere on the board
+5V: C99.1, F91.1, R91.1, R92.1, U92.5 (SENSE), U92.6 (VDD), U93.3 (VI), U94.3 (VI), U95.3 (VI); also elsewhere on the board
/5_SYS_VCC_PWR: J91.1; also elsewhere on the board
/5_SYS_nRES: D92.2 (A); also elsewhere on the board
/CLK_48M: X96.3 (OUT); also elsewhere on the board
/MEM_BB_nCE_BB: LK91.2, U91.6 (Econ); also elsewhere on the board
/MEM_RAM_nCE0: LK91.1, R95.1, U91.5 (E); also elsewhere on the board
/SUP_nRES: LK92.2, R93.2, U92.1 (~RESET); also elsewhere on the board
/power/5_SUP_nMR: D91.1 (K), D92.1 (K), LK92.1, R91.2, U92.3 (~MR)
/power/PWRA: J91.3, J92.1
/power/PWRU: F91.2, J91.2
/power/VBAT: C91.1, C92.1, D90.2 (A), LK90.2, U91.8 (Vbat)
unnamed: D91.2 (A), U91.7 (nRST)
unnamed: R92.2, U92.4 (CT)
unnamed: R94.2, X96.1 (Tri-State)

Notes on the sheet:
Solder bridge if no stm795 Also, NF D91
Solder bridge if no tps3808 do NOT FIT R91 when linked
DB-5R5D155T
solder bridge if no stm795

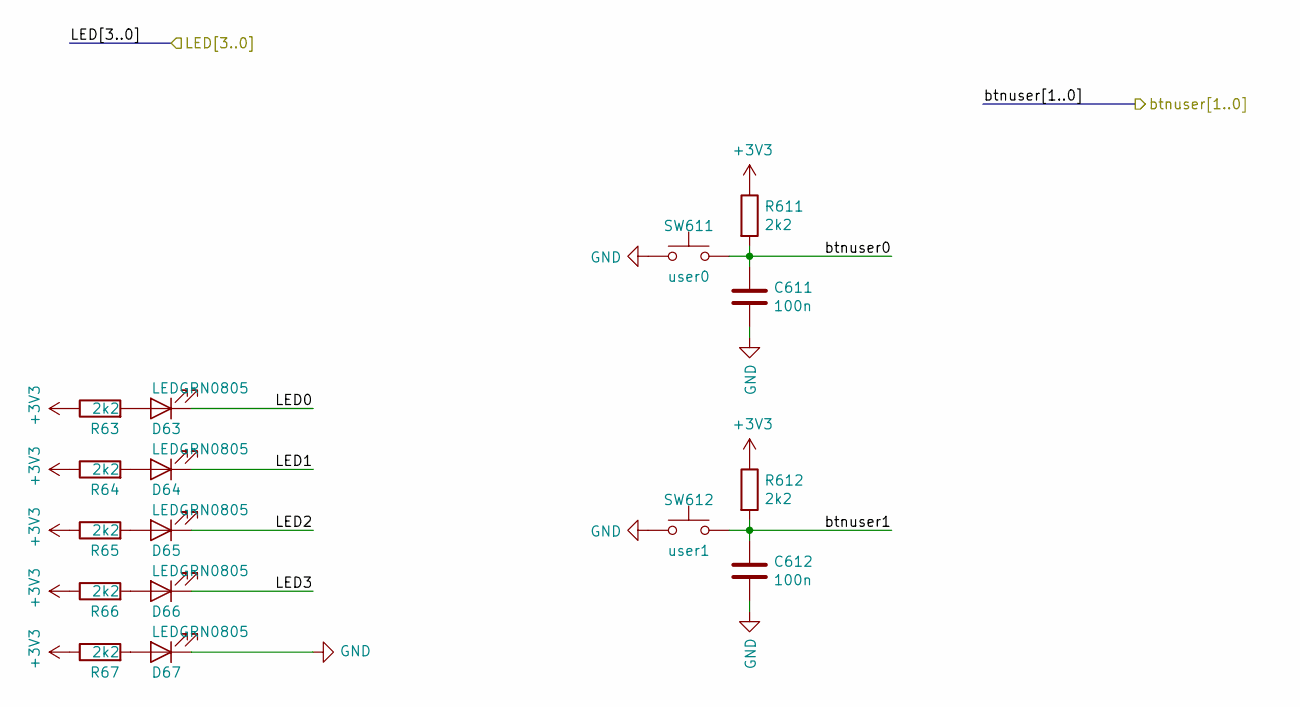
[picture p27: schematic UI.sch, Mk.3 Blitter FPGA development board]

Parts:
C611, C612: 100n; C_0805
D63, D64, D65, D66, D67: LEDGRN0805; LED_0805
R63, R64, R65, R66, R67, R611, R612: 2k2; R_0805
SW611: user0; SW_SPST_GEN
SW612: user1; SW_SPST_GEN

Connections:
+3V3: R63.1, R64.1, R65.1, R66.1, R67.1, R611.1, R612.1; also elsewhere on the board
/UI/LED0: D63.1 (K); also elsewhere on the board
/UI/LED1: D64.1 (K); also elsewhere on the board
/UI/LED2: D65.1 (K); also elsewhere on the board
/UI/LED3: D66.1 (K); also elsewhere on the board
/fpga_top/BTNUSER_i_0: C611.1, R611.2, SW611.1; also elsewhere on the board
/fpga_top/BTNUSER_i_1: C612.1, R612.2, SW612.1; also elsewhere on the board
unnamed: D63.2 (A), R63.2
unnamed: D64.2 (A), R64.2
unnamed: D65.2 (A), R65.2
unnamed: D66.2 (A), R66.2
unnamed: D67.2 (A), R67.2

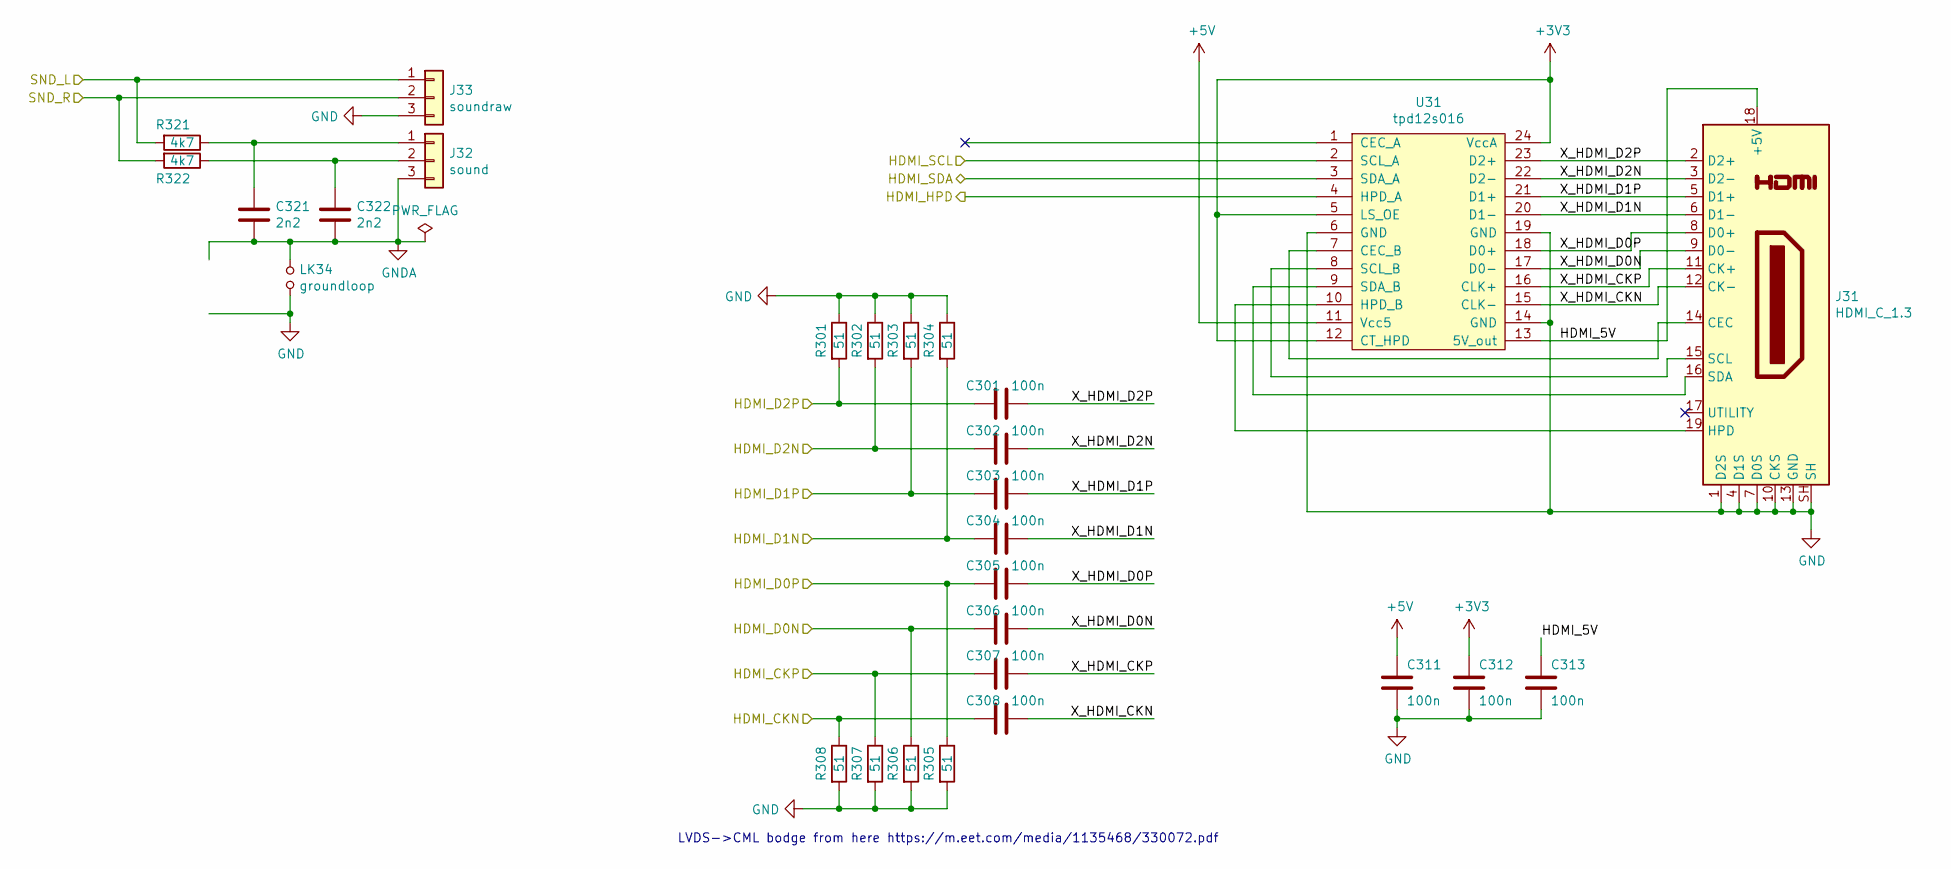
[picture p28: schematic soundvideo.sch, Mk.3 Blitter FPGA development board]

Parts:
C301, C302, C303, C304, C305, C306, C307, C308: 100n; C_0402
C311, C312, C313: 100n; C_0805
C321, C322: 2n2; C_0805
J31: HDMI_C_1.3; HDMI_Mini_Female_2001-1-2-21-00-BK-round-holes
J32: sound; PinHeader_1x03_P2.54mm_Vertical
J33: soundraw; PinHeader_1x03_P2.54mm_Vertical
LK34: groundloop; SolderJumper-2_P1.3mm_Open_RoundedPad1.0x1.5mm-domsmallctyd
R301, R302, R303, R304, R305, R306, R307, R308: 51; R_0402
R321, R322: 4k7; R_0805
U31: tpd12s016; TSSOP-24_4.4x7.8mm_Pitch0.65mm

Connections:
+3V3: C312.1, U31.5 (LS_OE), U31.12 (CT_HPD), U31.24 (VccA); also elsewhere on the board
+5V: C311.1, U31.11 (Vcc5); also elsewhere on the board
/HDMI_CKN: C308.2, R308.1; also elsewhere on the board
/HDMI_CKP: C307.2, R307.1; also elsewhere on the board
/HDMI_D0N: C306.2, R306.1; also elsewhere on the board
/HDMI_D0P: C305.2, R305.1; also elsewhere on the board
/HDMI_D1N: C304.2, R304.2; also elsewhere on the board
/HDMI_D1P: C303.2, R303.2; also elsewhere on the board
/HDMI_D2N: C302.2, R302.2; also elsewhere on the board
/HDMI_D2P: C301.2, R301.2; also elsewhere on the board
/HDMI_HPD: U31.4 (HPD_A); also elsewhere on the board
/HDMI_SCL: U31.2 (SCL_A); also elsewhere on the board
/HDMI_SDA: U31.3 (SDA_A); also elsewhere on the board
/SND_L: J33.1, R321.2; also elsewhere on the board
/SND_R: J33.2, R322.2; also elsewhere on the board
/soundvideo/HDMI_5V: C313.1, J31.18 (+5V), U31.13 (5V_out)
/soundvideo/X_HDMI_CKN: C308.1, J31.12 (CK-), U31.15 (CLK-)
/soundvideo/X_HDMI_CKP: C307.1, J31.11 (CK+), U31.16 (CLK+)
/soundvideo/X_HDMI_D0N: C306.1, J31.9 (D0-), U31.17 (D0-)
/soundvideo/X_HDMI_D0P: C305.1, J31.8 (D0+), U31.18 (D0+)
/soundvideo/X_HDMI_D1N: C304.1, J31.6 (D1-), U31.20 (D1-)
/soundvideo/X_HDMI_D1P: C303.1, J31.5 (D1+), U31.21 (D1+)
/soundvideo/X_HDMI_D2N: C302.1, J31.3 (D2-), U31.22 (D2-)
/soundvideo/X_HDMI_D2P: C301.1, J31.2 (D2+), U31.23 (D2+)
GNDA: C321.2, C322.2, J32.3, LK34.1
unnamed: C321.1, J32.1, R321.1
unnamed: C322.1, J32.2, R322.1
unnamed: J31.14 (CEC), U31.7 (CEC_B)
unnamed: J31.15 (SCL), U31.8 (SCL_B)
unnamed: J31.16 (SDA), U31.9 (SDA_B)
unnamed: J31.19 (HPD), U31.10 (HPD_B)

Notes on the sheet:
LVDS->CML bodge from here https://m.eet.com/media/1135468/330072.pdf

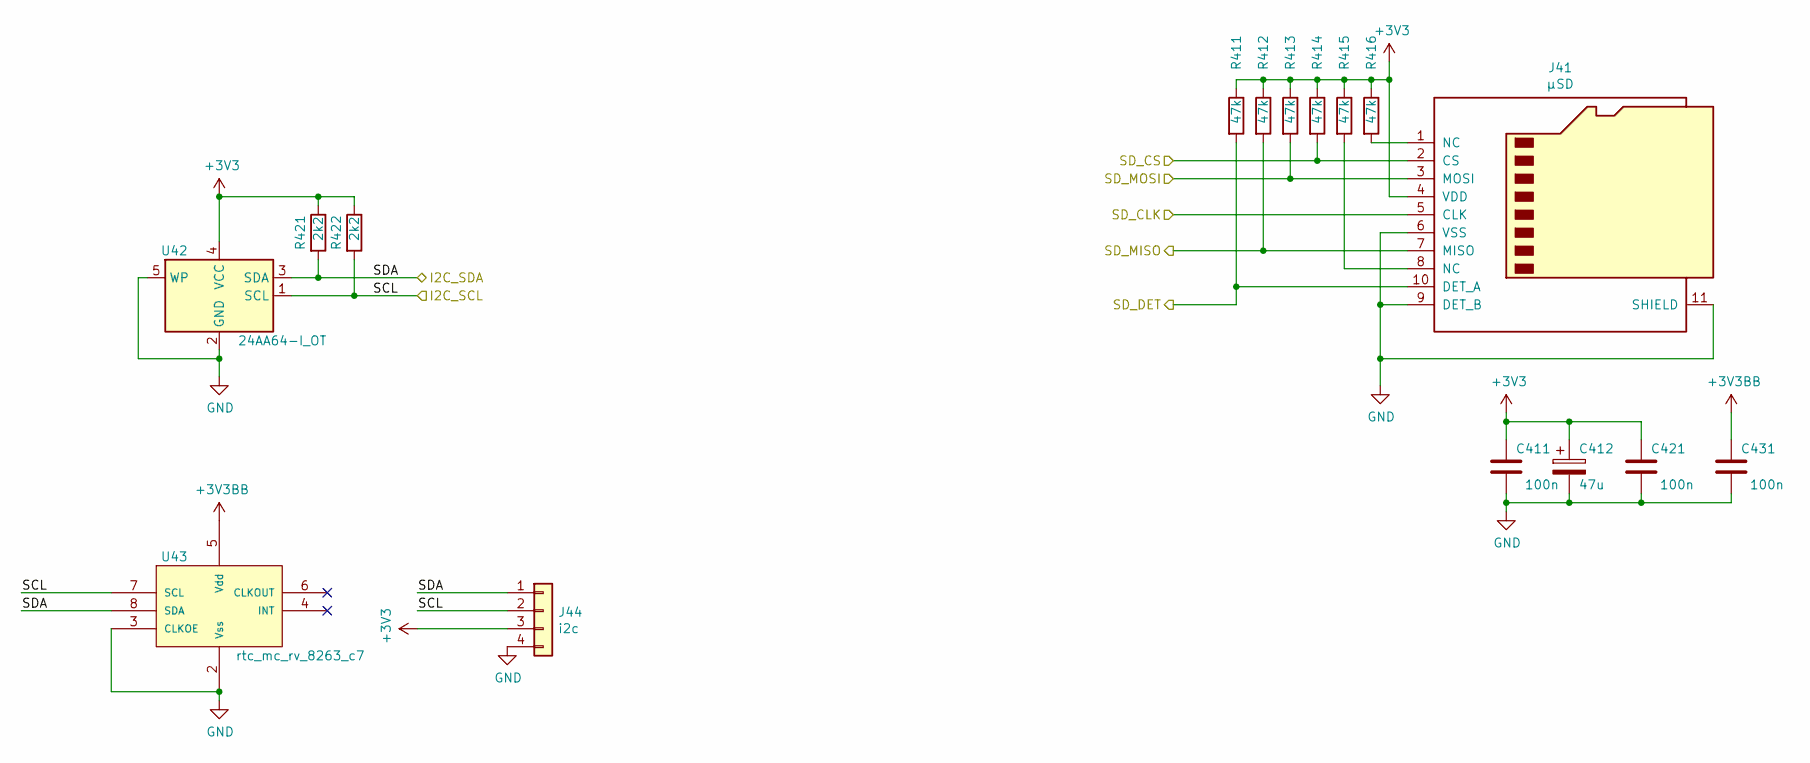
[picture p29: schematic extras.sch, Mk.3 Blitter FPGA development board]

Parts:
C411, C421, C431: 100n; C_0805
C412: 47u; C_0805
J41: μSD; hirose_micro_sd_card_socket
J44: i2c; PinHeader_1x04_P2.54mm_Vertical
R411, R412, R413, R414, R415, R416: 47k; R_0805
R421, R422: 2k2; R_0805
U42: 24AA64-I_OT; SOT-23-5
U43: rtc_mc_rv_8263_c7; 8pin_mini_rtc

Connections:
+3V3: C411.1, C412.1, C421.1, J41.4 (VDD), J44.3, R411.1, R412.1, R413.1, R414.1, R415.1, R416.1, R421.1, R422.1, U42.4 (VCC); also elsewhere on the board
+3V3BB: C431.1, U43.5 (Vdd); also elsewhere on the board
/I2C_SCL: J44.2, R422.2, U42.1 (SCL), U43.7 (SCL); also elsewhere on the board
/I2C_SDA: J44.1, R421.2, U42.3 (SDA), U43.8 (SDA); also elsewhere on the board
/SD_CLK: J41.5 (CLK); also elsewhere on the board
/SD_CS: J41.2 (CS), R414.2; also elsewhere on the board
/SD_DET: J41.10 (DET_A), R411.2; also elsewhere on the board
/SD_MISO: J41.7 (MISO), R412.2; also elsewhere on the board
/SD_MOSI: J41.3 (MOSI), R413.2; also elsewhere on the board
unnamed: J41.1 (NC), R416.2
unnamed: J41.8 (NC), R415.2


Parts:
J51: rpi_gpio; PinSocket_2x20_P2.54mm_Vertical_SMD-dom
J52: Conn_02x20_Odd_Even; PinHeader_2x20_P2.54mm_Vertical_SMD-dom
J54: Conn_02x08_Odd_Even; PinHeader_2x08_P2.54mm_Vertical_SMD-dom
J56: BOOT; PinHeader_2x09_P2.54mm_Vertical
J57: rpi power; PinHeader_1x02_P2.54mm_Vertical
R50, R51, R52, R53, R54, R55, R56, R57, R58: *NF; R_0805

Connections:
+3V3: J52.37, J54.12; also elsewhere on the board
+5V: J52.19, J52.20, J54.15, J54.16, J57.1, R50.1, R51.1, R52.1, R53.1, R54.1, R55.1, R56.1, R57.1, R58.1; also elsewhere on the board
/exp_PORTA_DIR: J52.4; also elsewhere on the board
/exp_PORTA_nOE: J52.2; also elsewhere on the board
/exp_PORTE_nOE: J54.11; also elsewhere on the board
/exp_PORTF_nOE: J54.13; also elsewhere on the board
/exp_PORTG_nOE: J54.14; also elsewhere on the board
/expansion_headers/5C_exp_PORTA0: J52.1; also elsewhere on the board
/expansion_headers/5C_exp_PORTA1: J52.3; also elsewhere on the board
/expansion_headers/5C_exp_PORTA2: J52.5; also elsewhere on the board
/expansion_headers/5C_exp_PORTA3: J52.7; also elsewhere on the board
/expansion_headers/5C_exp_PORTA4: J52.9; also elsewhere on the board
/expansion_headers/5C_exp_PORTA5: J52.6; also elsewhere on the board
/expansion_headers/5C_exp_PORTA6: J52.8; also elsewhere on the board
/expansion_headers/5C_exp_PORTA7: J52.10; also elsewhere on the board
/expansion_headers/5C_exp_PORTB0: J52.11; also elsewhere on the board
/expansion_headers/5C_exp_PORTB1: J52.13; also elsewhere on the board
/expansion_headers/5C_exp_PORTB2: J52.15; also elsewhere on the board
/expansion_headers/5C_exp_PORTB3: J52.17; also elsewhere on the board
/expansion_headers/5C_exp_PORTB4: J52.12; also elsewhere on the board
/expansion_headers/5C_exp_PORTB5: J52.14; also elsewhere on the board
/expansion_headers/5C_exp_PORTB6: J52.16; also elsewhere on the board
/expansion_headers/5C_exp_PORTB7: J52.18; also elsewhere on the board
/expansion_headers/5_exp_PORTC0: J51.3 (gpio2); also elsewhere on the board
/expansion_headers/5_exp_PORTC1: J51.5 (gpio3); also elsewhere on the board
/expansion_headers/5_exp_PORTC2: J51.7 (gpio4); also elsewhere on the board
/expansion_headers/5_exp_PORTC3: J51.8 (gpio14); also elsewhere on the board
/expansion_headers/5_exp_PORTC4: J51.10 (gpio15); also elsewhere on the board
/expansion_headers/5_exp_PORTC5: J51.11 (gpio17); also elsewhere on the board
/expansion_headers/5_exp_PORTC6: J51.12 (gpio18); also elsewhere on the board
/expansion_headers/5_exp_PORTC7: J51.15 (gpio22); also elsewhere on the board
/expansion_headers/5_exp_PORTC8: J51.19 (gpio10); also elsewhere on the board
/expansion_headers/5_exp_PORTC9: J51.16 (gpio23); also elsewhere on the board
/expansion_headers/5_exp_PORTC10: J51.18 (gpio24); also elsewhere on the board
/expansion_headers/5_exp_PORTC11: J51.24 (gpio8); also elsewhere on the board
/expansion_headers/5_exp_PORTD0: J51.21 (gpio9); also elsewhere on the board
/expansion_headers/5_exp_PORTD1: J51.22 (gpio25); also elsewhere on the board
/expansion_headers/5_exp_PORTD2: J51.23 (gpio11); also elsewhere on the board
/expansion_headers/5_exp_PORTD3: J51.26 (gpio7); also elsewhere on the board
/expansion_headers/5_exp_PORTD4: J51.29 (gpio5); also elsewhere on the board
/expansion_headers/5_exp_PORTD5: J51.31 (gpio6); also elsewhere on the board
/expansion_headers/5_exp_PORTD6: J51.32 (gpio12); also elsewhere on the board
/expansion_headers/5_exp_PORTD7: J51.33 (gpio13); also elsewhere on the board
/expansion_headers/5_exp_PORTD8: J51.35 (gpio19); also elsewhere on the board
/expansion_headers/5_exp_PORTD9: J51.36 (gpio16); also elsewhere on the board
/expansion_headers/5_exp_PORTD10: J51.38 (gpio20); also elsewhere on the board
/expansion_headers/5_exp_PORTD11: J51.40 (gpio21); also elsewhere on the board
/expansion_headers/5_exp_PORTE0: J51.13 (gpio27); also elsewhere on the board
/expansion_headers/5_exp_PORTE1: J51.37 (gpio26); also elsewhere on the board
/expansion_headers/5_exp_PORTE2: J52.22; also elsewhere on the board
/expansion_headers/5_exp_PORTE3: J52.21; also elsewhere on the board
/expansion_headers/5_exp_PORTE4: J52.24; also elsewhere on the board
/expansion_headers/5_exp_PORTE5: J52.23; also elsewhere on the board
/expansion_headers/5_exp_PORTE6: J52.26; also elsewhere on the board
/expansion_headers/5_exp_PORTE7: J52.25; also elsewhere on the board
/expansion_headers/5_exp_PORTE8: J52.30; also elsewhere on the board
/expansion_headers/5_exp_PORTE9: J52.29; also elsewhere on the board
/expansion_headers/5_exp_PORTE10: J52.32; also elsewhere on the board
/expansion_headers/5_exp_PORTE11: J52.31; also elsewhere on the board
/expansion_headers/5_exp_PORTF0: J52.35; also elsewhere on the board
/expansion_headers/5_exp_PORTF1: J52.33; also elsewhere on the board
/expansion_headers/5_exp_PORTF2: J52.36; also elsewhere on the board
/expansion_headers/5_exp_PORTF3: J52.34; also elsewhere on the board
/expansion_headers/5_exp_PORTF4: J54.9; also elsewhere on the board
/expansion_headers/5_exp_PORTF5: J54.10; also elsewhere on the board
/expansion_headers/5_exp_PORTF6: J54.7; also elsewhere on the board
/expansion_headers/5_exp_PORTF7: J54.8; also elsewhere on the board
/expansion_headers/5_exp_PORTF8: J54.5; also elsewhere on the board
/expansion_headers/5_exp_PORTF9: J54.6; also elsewhere on the board
/expansion_headers/5_exp_PORTF10: J54.3; also elsewhere on the board
/expansion_headers/5_exp_PORTF11: J54.4; also elsewhere on the board
/expansion_headers/5_exp_PORTG0: J56.1, R50.2; also elsewhere on the board
/expansion_headers/5_exp_PORTG1: J56.3, R51.2; also elsewhere on the board
/expansion_headers/5_exp_PORTG2: J56.5, R52.2; also elsewhere on the board
/expansion_headers/5_exp_PORTG3: J56.7, R53.2; also elsewhere on the board
/expansion_headers/5_exp_PORTG4: J56.9, R54.2; also elsewhere on the board
/expansion_headers/5_exp_PORTG5: J56.11, R55.2; also elsewhere on the board
/expansion_headers/5_exp_PORTG6: J56.13, R56.2; also elsewhere on the board
/expansion_headers/5_exp_PORTG7: J56.15, R57.2; also elsewhere on the board
/expansion_headers/5_exp_PORTG8: J56.17, R58.2; also elsewhere on the board
/expansion_headers/5_exp_PORTG9: J52.38; also elsewhere on the board
/expansion_headers/5_exp_PORTG10: J52.40; also elsewhere on the board
/expansion_headers/5_exp_PORTG11: J52.39; also elsewhere on the board
unnamed: J51.2 (5V), J51.4 (5V), J57.2

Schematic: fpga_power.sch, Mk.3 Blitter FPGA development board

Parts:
C81, C82, C83, C84, C85, C86, C87, C88, C89, C810, C811, C812, C814, C815: 100n; C_0402
J81: JTAG; IDC-Header_2x05_P2.54mm_Vertical
J82: Jumper; PinHeader_1x02_P2.54mm_Vertical
R81: 1k; R_0805
R82, R83, R84, R85, R86, R87: 10k; R_0805
SW81: nConfig; SW_SPST_GEN
U8: 10M16DCF256I7G_mk3pinstest; MAX10_FBGA_256_dom

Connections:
+1V2: C814.1, C815.1, U8.F6 (VCC), U8.G7 (VCC), U8.G9 (VCC), U8.H8 (VCC), U8.H9 (VCC), U8.H10 (VCC), U8.J7 (VCC), U8.J8 (VCC), U8.J9 (VCC), U8.K8 (VCC), U8.K10 (VCC); also elsewhere on the board
+1V2_PLL: C81.1, C82.1, C83.1, C84.1, U8.D4 (VCCD_PLL3), U8.D13 (VCCD_PLL2), U8.M5 (VCCD_PLL1), U8.N13 (VCCD_PLL4); also elsewhere on the board
+2V5: C85.1, C86.1, C87.1, C88.1, U8.D5 (VCCA3), U8.E4 (VCCA3), U8.E5 (VCCA3), U8.E12 (VCCA2), U8.L5 (VCCA1), U8.M12 (VCCA4), U8.N10 (VCCIO4), U8.N11 (VCCIO4); also elsewhere on the board
+3V3: C89.1, C810.1, C811.1, C812.1, J81.4, J82.2, R82.1, R83.1, R84.1, R85.1, R86.2, U8.C7 (VCCIO8), U8.D7 (VCCIO8), U8.D8 (VCCIO8), U8.D10 (VCCIO7), U8.D11 (VCCIO7), U8.F13 (VCCIO6), U8.G4 (VCCIO1A), U8.G13 (VCCIO6), U8.H4 (VCCIO1A), U8.H13 (VCCIO6), U8.J4 (VCCIO1B), U8.J13 (VCCIO6), U8.K4 (VCCIO2), U8.K13 (VCCIO5), U8.L4 (VCCIO2), U8.L13 (VCCIO5), U8.M13 (VCCIO5), U8.N6 (VCCIO3), U8.N7 (VCCIO3), U8.N8 (VCCIO3); also elsewhere on the board
/ALTERA_CONFIG_SEL: J82.1, R87.2; also elsewhere on the board
/ALTERA_CONF_DONE: R85.2; also elsewhere on the board
/ALTERA_nCONFIG: R86.1, SW81.1; also elsewhere on the board
/ALTERA_nSTATUS: R84.2; also elsewhere on the board
/fpga_power/~ALTERA_TCK~: J81.1, R81.2, U8.H3 (~ALTERA_TCK~)
/fpga_power/~ALTERA_TDI~: J81.9, R83.2, U8.G1 (~ALTERA_TDI~)
/fpga_power/~ALTERA_TDO~: J81.3, U8.H1 (~ALTERA_TDO~)
/fpga_power/~ALTERA_TMS~: J81.5, R82.2, U8.H2 (~ALTERA_TMS~)

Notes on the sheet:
1v2 DECOUPLERS!

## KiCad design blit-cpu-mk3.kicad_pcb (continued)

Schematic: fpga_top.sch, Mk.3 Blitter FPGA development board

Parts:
U8: 10M16DCF256I7G_mk3pinstest; MAX10_FBGA_256_dom

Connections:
/ALTERA_CONFIG_SEL: U8.F8 (~ALTERA_CONFIG_SEL~); also elsewhere on the board
/ALTERA_CONF_DONE: U8.E7 (~ALTERA_CONF_DONE~); also elsewhere on the board
/ALTERA_nCONFIG: U8.E8 (~ALTERA_nCONFIG~); also elsewhere on the board
/ALTERA_nSTATUS: U8.F7 (~ALTERA_nSTATUS~); also elsewhere on the board
/CLK_48M: U8.J11 (CLK_48M_i); also elsewhere on the board
/HDMI_CKN: U8.P10 (HDMI_CK_o(n)); also elsewhere on the board
/HDMI_CKP: U8.P11 (HDMI_CK_o); also elsewhere on the board
/HDMI_D0N: U8.P13 (HDMI_D0_o(n)); also elsewhere on the board
/HDMI_D0P: U8.P12 (HDMI_D0_o); also elsewhere on the board
/HDMI_D1N: U8.M10 (HDMI_D1_o(n)); also elsewhere on the board
/HDMI_D1P: U8.L9 (HDMI_D1_o); also elsewhere on the board
/HDMI_D2N: U8.M11 (HDMI_D2_o(n)); also elsewhere on the board
/HDMI_D2P: U8.L10 (HDMI_D2_o); also elsewhere on the board
/HDMI_HPD: U8.T14 (HDMI_HPD_i); also elsewhere on the board
/HDMI_SCL: U8.T15 (HDMI_SCL_o); also elsewhere on the board
/HDMI_SDA: U8.R14 (HDMI_SDA_io); also elsewhere on the board
/I2C_SCL: U8.T8 (I2C_SCL_o); also elsewhere on the board
/I2C_SDA: U8.R9 (I2C_SDA_io); also elsewhere on the board
/MEM_FL_nCE: U8.B2 (MEM_FL_nCE_o); also elsewhere on the board
/MEM_RAM_nCE0: U8.F5 (MEM_RAM_nCE_o_0); also elsewhere on the board
/MEM_nOE: U8.C3 (MEM_nOE_o); also elsewhere on the board
/MEM_nWE: U8.K6 (MEM_nWE_o); also elsewhere on the board
/SD_CLK: U8.P9 (SD_CLK_o); also elsewhere on the board
/SD_CS: U8.R10 (SD_CS_o); also elsewhere on the board
/SD_DET: U8.T12 (SD_DET_i); also elsewhere on the board
/SD_MISO: U8.R11 (SD_MISO_i); also elsewhere on the board
/SD_MOSI: U8.T11 (SD_MOSI_o); also elsewhere on the board
/SND_L: U8.M9 (SND_L_o); also elsewhere on the board
/SND_R: U8.T9 (SND_R_o); also elsewhere on the board
/SUP_nRES: U8.R8 (SUP_nRESET_i); also elsewhere on the board
/SYS_BUFD_DIR: U8.E16 (SYS_BUF_D_DIR_o); also elsewhere on the board
/SYS_BUFD_nOE: U8.F14 (SYS_BUF_D_nOE_o); also elsewhere on the board
/SYS_DBE: U8.D16 (SYS_nDBE_i); also elsewhere on the board
/SYS_PHI0: U8.D15 (SYS_PHI0_i); also elsewhere on the board
/SYS_PHI1: U8.N16 (SYS_PHI1_o); also elsewhere on the board
/SYS_PHI2: U8.R15 (SYS_PHI2_o); also elsewhere on the board
/SYS_RDY: U8.C15 (SYS_RDY_i); also elsewhere on the board
/SYS_RnW: U8.M16 (SYS_RnW_o); also elsewhere on the board
/SYS_SYNC: U8.N14 (SYS_SYNC_o); also elsewhere on the board
/SYS_nIRQ: U8.C16 (SYS_nIRQ_i); also elsewhere on the board
/SYS_nNMI: U8.B15 (SYS_nNMI_i); also elsewhere on the board
/UI/LED0: U8.D14 (LED_o_0); also elsewhere on the board
/UI/LED1: U8.G11 (LED_o_1); also elsewhere on the board
/UI/LED2: U8.E14 (LED_o_2); also elsewhere on the board
/UI/LED3: U8.G12 (LED_o_3); also elsewhere on the board
/exp_PORTA_DIR: U8.C4 (exp_PORTA_DIR_o); also elsewhere on the board
/exp_PORTA_nOE: U8.C5 (exp_PORTA_nOE_o); also elsewhere on the board
/exp_PORTE_nOE: U8.A3 (exp_PORTE_nOE); also elsewhere on the board
/exp_PORTF_nOE: U8.B3 (exp_PORTF_nOE); also elsewhere on the board
/exp_PORTG_nOE: U8.B16 (exp_PORTG_nOE); also elsewhere on the board
/fpga_top/BTNUSER_i_0: U8.C14 (BTNUSER_i_0); also elsewhere on the board
/fpga_top/BTNUSER_i_1: U8.F12 (BTNUSER_i_1); also elsewhere on the board
/fpga_top/exp_PORTA_io_0: U8.C6 (exp_PORTA_io_0); also elsewhere on the board
/fpga_top/exp_PORTA_io_1: U8.E9 (exp_PORTA_io_1); also elsewhere on the board
/fpga_top/exp_PORTA_io_2: U8.F9 (exp_PORTA_io_2); also elsewhere on the board
/fpga_top/exp_PORTA_io_3: U8.C10 (exp_PORTA_io_3); also elsewhere on the board
/fpga_top/exp_PORTA_io_4: U8.E11 (exp_PORTA_io_4); also elsewhere on the board
/fpga_top/exp_PORTA_io_5: U8.C9 (exp_PORTA_io_5); also elsewhere on the board
/fpga_top/exp_PORTA_io_6: U8.D9 (exp_PORTA_io_6); also elsewhere on the board
/fpga_top/exp_PORTA_io_7: U8.B12 (exp_PORTA_io_7); also elsewhere on the board
/fpga_top/exp_PORTB_o_0: U8.C12 (exp_PORTB_o_0); also elsewhere on the board
/fpga_top/exp_PORTB_o_1: U8.D12 (exp_PORTB_o_1); also elsewhere on the board
/fpga_top/exp_PORTB_o_2: U8.C13 (exp_PORTB_o_2); also elsewhere on the board
/fpga_top/exp_PORTB_o_3: U8.A15 (exp_PORTB_o_3); also elsewhere on the board
/fpga_top/exp_PORTB_o_4: U8.A13 (exp_PORTB_o_4); also elsewhere on the board
/fpga_top/exp_PORTB_o_5: U8.B13 (exp_PORTB_o_5); also elsewhere on the board
/fpga_top/exp_PORTB_o_6: U8.A14 (exp_PORTB_o_6); also elsewhere on the board
/fpga_top/exp_PORTB_o_7: U8.F11 (exp_PORTB_o_7); also elsewhere on the board
/fpga_top/exp_PORTC_io_0: U8.R5 (exp_PORTC_io_0); also elsewhere on the board
/fpga_top/exp_PORTC_io_1: U8.T5 (exp_PORTC_io_1); also elsewhere on the board
/fpga_top/exp_PORTC_io_2: U8.R6 (exp_PORTC_io_2); also elsewhere on the board
/fpga_top/exp_PORTC_io_3: U8.R4 (exp_PORTC_io_3); also elsewhere on the board
/fpga_top/exp_PORTC_io_4: U8.T3 (exp_PORTC_io_4); also elsewhere on the board
/fpga_top/exp_PORTC_io_5: U8.T6 (exp_PORTC_io_5); also elsewhere on the board
/fpga_top/exp_PORTC_io_6: U8.R3 (exp_PORTC_io_6); also elsewhere on the board
/fpga_top/exp_PORTC_io_7: U8.T4 (exp_PORTC_io_7); also elsewhere on the board
/fpga_top/exp_PORTC_io_8: U8.P6 (exp_PORTC_io_8); also elsewhere on the board
/fpga_top/exp_PORTC_io_9: U8.P5 (exp_PORTC_io_9); also elsewhere on the board
/fpga_top/exp_PORTC_io_10: U8.P4 (exp_PORTC_io_10); also elsewhere on the board
/fpga_top/exp_PORTC_io_11: U8.N3 (exp_PORTC_io_11); also elsewhere on the board
/fpga_top/exp_PORTD_io_0: U8.N5 (exp_PORTD_io_0); also elsewhere on the board
/fpga_top/exp_PORTD_io_1: U8.N4 (exp_PORTD_io_1); also elsewhere on the board
/fpga_top/exp_PORTD_io_2: U8.R2 (exp_PORTD_io_2); also elsewhere on the board
/fpga_top/exp_PORTD_io_3: U8.M3 (exp_PORTD_io_3); also elsewhere on the board
/fpga_top/exp_PORTD_io_4: U8.M1 (exp_PORTD_io_4); also elsewhere on the board
/fpga_top/exp_PORTD_io_5: U8.M2 (exp_PORTD_io_5); also elsewhere on the board
/fpga_top/exp_PORTD_io_6: U8.T2 (exp_PORTD_io_6); also elsewhere on the board
/fpga_top/exp_PORTD_io_7: U8.N1 (exp_PORTD_io_7); also elsewhere on the board
/fpga_top/exp_PORTD_io_8: U8.N2 (exp_PORTD_io_8); also elsewhere on the board
/fpga_top/exp_PORTD_io_9: U8.R1 (exp_PORTD_io_9); also elsewhere on the board
/fpga_top/exp_PORTD_io_10: U8.P2 (exp_PORTD_io_10); also elsewhere on the board
/fpga_top/exp_PORTD_io_11: U8.P1 (exp_PORTD_io_11); also elsewhere on the board
/fpga_top/exp_PORTEFG_io_0: U8.A4 (exp_PORTEFG_io_0); also elsewhere on the board
/fpga_top/exp_PORTEFG_io_1: U8.B4 (exp_PORTEFG_io_1); also elsewhere on the board
/fpga_top/exp_PORTEFG_io_2: U8.A5 (exp_PORTEFG_io_2); also elsewhere on the board
/fpga_top/exp_PORTEFG_io_3: U8.B5 (exp_PORTEFG_io_3); also elsewhere on the board
/fpga_top/exp_PORTEFG_io_4: U8.A6 (exp_PORTEFG_io_4); also elsewhere on the board
/fpga_top/exp_PORTEFG_io_5: U8.B6 (exp_PORTEFG_io_5); also elsewhere on the board
/fpga_top/exp_PORTEFG_io_6: U8.A7 (exp_PORTEFG_io_6); also elsewhere on the board
/fpga_top/exp_PORTEFG_io_7: U8.B7 (exp_PORTEFG_io_7); also elsewhere on the board
/fpga_top/exp_PORTEFG_io_8: U8.A8 (exp_PORTEFG_io_8); also elsewhere on the board
/fpga_top/exp_PORTEFG_io_9: U8.B8 (exp_PORTEFG_io_9); also elsewhere on the board
/fpga_top/exp_PORTEFG_io_10: U8.A9 (exp_PORTEFG_io_10); also elsewhere on the board
/fpga_top/exp_PORTEFG_io_11: U8.B9 (exp_PORTEFG_io_11); also elsewhere on the board
/memory/MEM_A0: U8.F4 (MEM_A_o_0); also elsewhere on the board
/memory/MEM_A1: U8.G2 (MEM_A_o_1); also elsewhere on the board
/memory/MEM_A2: U8.J2 (MEM_A_o_2); also elsewhere on the board
/memory/MEM_A3: U8.J1 (MEM_A_o_3); also elsewhere on the board
/memory/MEM_A4: U8.L3 (MEM_A_o_4); also elsewhere on the board
/memory/MEM_A5: U8.L2 (MEM_A_o_5); also elsewhere on the board
/memory/MEM_A6: U8.L1 (MEM_A_o_6); also elsewhere on the board
/memory/MEM_A7: U8.L6 (MEM_A_o_7); also elsewhere on the board
/memory/MEM_A8: U8.H5 (MEM_A_o_8); also elsewhere on the board
/memory/MEM_A9: U8.H6 (MEM_A_o_9); also elsewhere on the board
/memory/MEM_A10: U8.A2 (MEM_A_o_10); also elsewhere on the board
/memory/MEM_A11: U8.G5 (MEM_A_o_11); also elsewhere on the board
/memory/MEM_A12: U8.L7 (MEM_A_o_12); also elsewhere on the board
/memory/MEM_A13: U8.J6 (MEM_A_o_13); also elsewhere on the board
/memory/MEM_A14: U8.J5 (MEM_A_o_14); also elsewhere on the board
/memory/MEM_A15: U8.L8 (MEM_A_o_15); also elsewhere on the board
/memory/MEM_A16: U8.K2 (MEM_A_o_16); also elsewhere on the board
/memory/MEM_A17: U8.J3 (MEM_A_o_17); also elsewhere on the board
/memory/MEM_A18: U8.K5 (MEM_A_o_18); also elsewhere on the board
/memory/MEM_A19: U8.T7 (MEM_A_o_19); also elsewhere on the board
/memory/MEM_A20: U8.R7 (MEM_A_o_20); also elsewhere on the board
/memory/MEM_D0: U8.F1 (MEM_D_io_0); also elsewhere on the board
/memory/MEM_D1: U8.F2 (MEM_D_io_1); also elsewhere on the board
/memory/MEM_D2: U8.E1 (MEM_D_io_2); also elsewhere on the board
/memory/MEM_D3: U8.E3 (MEM_D_io_3); also elsewhere on the board
/memory/MEM_D4: U8.D1 (MEM_D_io_4); also elsewhere on the board
/memory/MEM_D5: U8.C1 (MEM_D_io_5); also elsewhere on the board
/memory/MEM_D6: U8.C2 (MEM_D_io_6); also elsewhere on the board
/memory/MEM_D7: U8.B1 (MEM_D_io_7); also elsewhere on the board
/memory/MEM_RAM_nCE1: U8.G6 (MEM_RAM_nCE_o_1); also elsewhere on the board
/memory/MEM_RAM_nCE2: U8.M6 (MEM_RAM_nCE_o_2); also elsewhere on the board
/memory/MEM_RAM_nCE3: U8.M8 (MEM_RAM_nCE_o_3); also elsewhere on the board
/sys_plug_and_buffers/SYS_A0: U8.M14 (SYS_A_o_0); also elsewhere on the board
/sys_plug_and_buffers/SYS_A1: U8.M15 (SYS_A_o_1); also elsewhere on the board
/sys_plug_and_buffers/SYS_A2: U8.L12 (SYS_A_o_2); also elsewhere on the board
/sys_plug_and_buffers/SYS_A3: U8.K14 (SYS_A_o_3); also elsewhere on the board
/sys_plug_and_buffers/SYS_A4: U8.L15 (SYS_A_o_4); also elsewhere on the board
/sys_plug_and_buffers/SYS_A5: U8.L16 (SYS_A_o_5); also elsewhere on the board
/sys_plug_and_buffers/SYS_A6: U8.K15 (SYS_A_o_6); also elsewhere on the board
/sys_plug_and_buffers/SYS_A7: U8.J15 (SYS_A_o_7); also elsewhere on the board
/sys_plug_and_buffers/SYS_A8: U8.H15 (SYS_A_o_8); also elsewhere on the board
/sys_plug_and_buffers/SYS_A9: U8.H16 (SYS_A_o_9); also elsewhere on the board
/sys_plug_and_buffers/SYS_A10: U8.J14 (SYS_A_o_10); also elsewhere on the board
/sys_plug_and_buffers/SYS_A11: U8.J16 (SYS_A_o_11); also elsewhere on the board
/sys_plug_and_buffers/SYS_A12: U8.L11 (SYS_A_o_12); also elsewhere on the board
/sys_plug_and_buffers/SYS_A13: U8.K12 (SYS_A_o_13); also elsewhere on the board
/sys_plug_and_buffers/SYS_A14: U8.K11 (SYS_A_o_14); also elsewhere on the board
/sys_plug_and_buffers/SYS_A15: U8.J12 (SYS_A_o_15); also elsewhere on the board
/sys_plug_and_buffers/SYS_AUX_IO_0: U8.A12 (SYS_AUX_io_0); also elsewhere on the board
/sys_plug_and_buffers/SYS_AUX_IO_1: U8.E10 (SYS_AUX_io_1); also elsewhere on the board
/sys_plug_and_buffers/SYS_AUX_IO_2: U8.B11 (SYS_AUX_io_2); also elsewhere on the board
/sys_plug_and_buffers/SYS_AUX_IO_3: U8.F10 (SYS_AUX_io_3); also elsewhere on the board
/sys_plug_and_buffers/SYS_AUX_IO_4: U8.A11 (SYS_AUX_io_4); also elsewhere on the board
/sys_plug_and_buffers/SYS_AUX_IO_5: U8.B10 (SYS_AUX_io_5); also elsewhere on the board
/sys_plug_and_buffers/SYS_AUX_IO_6: U8.A10 (SYS_AUX_io_6); also elsewhere on the board
/sys_plug_and_buffers/SYS_AUX_O0: U8.R16 (SYS_AUX_o_0); also elsewhere on the board
/sys_plug_and_buffers/SYS_AUX_O1: U8.P14 (SYS_AUX_o_1); also elsewhere on the board
/sys_plug_and_buffers/SYS_AUX_O2: U8.P16 (SYS_AUX_o_2); also elsewhere on the board
/sys_plug_and_buffers/SYS_AUX_O3: U8.P15 (SYS_AUX_o_3); also elsewhere on the board
/sys_plug_and_buffers/SYS_D0: U8.P8 (SYS_D_io_0); also elsewhere on the board
/sys_plug_and_buffers/SYS_D1: U8.H12 (SYS_D_io_1); also elsewhere on the board
/sys_plug_and_buffers/SYS_D2: U8.G14 (SYS_D_io_2); also elsewhere on the board
/sys_plug_and_buffers/SYS_D3: U8.H11 (SYS_D_io_3); also elsewhere on the board
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

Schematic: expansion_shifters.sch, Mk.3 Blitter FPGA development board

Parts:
C511, C512, C521, C522, C531, C541, C551: 100n; C_0805
U51, U52: 74LVC4245A; TSSOP-24_4.4x7.8mm_Pitch0.65mm
U53, U54, U55: 74CB3T16211; TSSOP-56_6.1x14mm_Pitch0.5mm

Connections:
+3V3: C512.1, C522.1, C531.1, C541.1, C551.1, U51.23 (VCCb), U51.24 (VCCb), U52.23 (VCCb), U52.24 (VCCb), U53.17 (Vcc), U54.17 (Vcc), U55.17 (Vcc); also elsewhere on the board
+5V: C511.1, C521.1, U51.1 (VCCa), U52.1 (VCCa); also elsewhere on the board
/exp_PORTA_DIR: U51.2 (A->B); also elsewhere on the board
/exp_PORTA_nOE: U51.22 (CE); also elsewhere on the board
/exp_PORTE_nOE: U55.55 (2nOE); also elsewhere on the board
/exp_PORTF_nOE: U55.56 (1nOE); also elsewhere on the board
/exp_PORTG_nOE: U54.55 (2nOE); also elsewhere on the board
/expansion_headers/5C_exp_PORTA0: U51.3 (A0); also elsewhere on the board
/expansion_headers/5C_exp_PORTA1: U51.4 (A1); also elsewhere on the board
/expansion_headers/5C_exp_PORTA2: U51.7 (A4); also elsewhere on the board
/expansion_headers/5C_exp_PORTA3: U51.8 (A5); also elsewhere on the board
/expansion_headers/5C_exp_PORTA4: U51.10 (A7); also elsewhere on the board
/expansion_headers/5C_exp_PORTA5: U51.5 (A2); also elsewhere on the board
/expansion_headers/5C_exp_PORTA6: U51.6 (A3); also elsewhere on the board
/expansion_headers/5C_exp_PORTA7: U51.9 (A6); also elsewhere on the board
/expansion_headers/5C_exp_PORTB0: U52.4 (A1); also elsewhere on the board
/expansion_headers/5C_exp_PORTB1: U52.6 (A3); also elsewhere on the board
/expansion_headers/5C_exp_PORTB2: U52.8 (A5); also elsewhere on the board
/expansion_headers/5C_exp_PORTB3: U52.10 (A7); also elsewhere on the board
/expansion_headers/5C_exp_PORTB4: U52.3 (A0); also elsewhere on the board
/expansion_headers/5C_exp_PORTB5: U52.5 (A2); also elsewhere on the board
/expansion_headers/5C_exp_PORTB6: U52.7 (A4); also elsewhere on the board
/expansion_headers/5C_exp_PORTB7: U52.9 (A6); also elsewhere on the board
/expansion_headers/5_exp_PORTC0: U53.5 (1A4); also elsewhere on the board
/expansion_headers/5_exp_PORTC1: U53.4 (1A3); also elsewhere on the board
/expansion_headers/5_exp_PORTC2: U53.3 (1A2); also elsewhere on the board
/expansion_headers/5_exp_PORTC3: U53.7 (1A6); also elsewhere on the board
/expansion_headers/5_exp_PORTC4: U53.9 (1A7); also elsewhere on the board
/expansion_headers/5_exp_PORTC5: U53.2 (1A1); also elsewhere on the board
/expansion_headers/5_exp_PORTC6: U53.10 (1A8); also elsewhere on the board
/expansion_headers/5_exp_PORTC7: U53.6 (1A5); also elsewhere on the board
/expansion_headers/5_exp_PORTC8: U53.11 (1A9); also elsewhere on the board
/expansion_headers/5_exp_PORTC9: U53.12 (1A10); also elsewhere on the board
/expansion_headers/5_exp_PORTC10: U53.13 (1A11); also elsewhere on the board
/expansion_headers/5_exp_PORTC11: U53.16 (2A2); also elsewhere on the board
/expansion_headers/5_exp_PORTD0: U53.14 (1A12); also elsewhere on the board
/expansion_headers/5_exp_PORTD1: U53.15 (2A1); also elsewhere on the board
/expansion_headers/5_exp_PORTD2: U53.21 (2A5); also elsewhere on the board
/expansion_headers/5_exp_PORTD3: U53.18 (2A3); also elsewhere on the board
/expansion_headers/5_exp_PORTD4: U53.28 (2A12); also elsewhere on the board
/expansion_headers/5_exp_PORTD5: U53.27 (2A11); also elsewhere on the board
/expansion_headers/5_exp_PORTD6: U53.20 (2A4); also elsewhere on the board
/expansion_headers/5_exp_PORTD7: U53.26 (2A10); also elsewhere on the board
/expansion_headers/5_exp_PORTD8: U53.25 (2A9); also elsewhere on the board
/expansion_headers/5_exp_PORTD9: U53.22 (2A6); also elsewhere on the board
/expansion_headers/5_exp_PORTD10: U53.23 (2A7); also elsewhere on the board
/expansion_headers/5_exp_PORTD11: U53.24 (2A8); also elsewhere on the board
/expansion_headers/5_exp_PORTE0: U55.28 (2A12); also elsewhere on the board
/expansion_headers/5_exp_PORTE1: U55.27 (2A11); also elsewhere on the board
/expansion_headers/5_exp_PORTE2: U55.26 (2A10); also elsewhere on the board
/expansion_headers/5_exp_PORTE3: U55.25 (2A9); also elsewhere on the board
/expansion_headers/5_exp_PORTE4: U55.24 (2A8); also elsewhere on the board
/expansion_headers/5_exp_PORTE5: U55.23 (2A7); also elsewhere on the board
/expansion_headers/5_exp_PORTE6: U55.22 (2A6); also elsewhere on the board
/expansion_headers/5_exp_PORTE7: U55.21 (2A5); also elsewhere on the board
/expansion_headers/5_exp_PORTE8: U55.20 (2A4); also elsewhere on the board
/expansion_headers/5_exp_PORTE9: U55.18 (2A3); also elsewhere on the board
/expansion_headers/5_exp_PORTE10: U55.16 (2A2); also elsewhere on the board
/expansion_headers/5_exp_PORTE11: U55.15 (2A1); also elsewhere on the board
/expansion_headers/5_exp_PORTF0: U55.2 (1A1); also elsewhere on the board
/expansion_headers/5_exp_PORTF1: U55.3 (1A2); also elsewhere on the board
/expansion_headers/5_exp_PORTF2: U55.4 (1A3); also elsewhere on the board
/expansion_headers/5_exp_PORTF3: U55.5 (1A4); also elsewhere on the board
/expansion_headers/5_exp_PORTF4: U55.6 (1A5); also elsewhere on the board
/expansion_headers/5_exp_PORTF5: U55.7 (1A6); also elsewhere on the board
/expansion_headers/5_exp_PORTF6: U55.9 (1A7); also elsewhere on the board
/expansion_headers/5_exp_PORTF7: U55.10 (1A8); also elsewhere on the board
/expansion_headers/5_exp_PORTF8: U55.11 (1A9); also elsewhere on the board
/expansion_headers/5_exp_PORTF9: U55.12 (1A10); also elsewhere on the board
/expansion_headers/5_exp_PORTF10: U55.13 (1A11); also elsewhere on the board
/expansion_headers/5_exp_PORTF11: U55.14 (1A12); also elsewhere on the board
/expansion_headers/5_exp_PORTG0: U54.28 (2A12); also elsewhere on the board
/expansion_headers/5_exp_PORTG1: U54.27 (2A11); also elsewhere on the board
/expansion_headers/5_exp_PORTG2: U54.26 (2A10); also elsewhere on the board
/expansion_headers/5_exp_PORTG3: U54.25 (2A9); also elsewhere on the board
/expansion_headers/5_exp_PORTG4: U54.24 (2A8); also elsewhere on the board
/expansion_headers/5_exp_PORTG5: U54.23 (2A7); also elsewhere on the board
/expansion_headers/5_exp_PORTG6: U54.22 (2A6); also elsewhere on the board
/expansion_headers/5_exp_PORTG7: U54.21 (2A5); also elsewhere on the board
/expansion_headers/5_exp_PORTG8: U54.20 (2A4); also elsewhere on the board
/expansion_headers/5_exp_PORTG9: U54.18 (2A3); also elsewhere on the board
/expansion_headers/5_exp_PORTG10: U54.16 (2A2); also elsewhere on the board
/expansion_headers/5_exp_PORTG11: U54.15 (2A1); also elsewhere on the board
/fpga_top/exp_PORTA_io_0: U51.21 (B0); also elsewhere on the board
/fpga_top/exp_PORTA_io_1: U51.20 (B1); also elsewhere on the board
/fpga_top/exp_PORTA_io_2: U51.17 (B4); also elsewhere on the board
/fpga_top/exp_PORTA_io_3: U51.16 (B5); also elsewhere on the board
/fpga_top/exp_PORTA_io_4: U51.14 (B7); also elsewhere on the board
/fpga_top/exp_PORTA_io_5: U51.19 (B2); also elsewhere on the board
/fpga_top/exp_PORTA_io_6: U51.18 (B3); also elsewhere on the board
/fpga_top/exp_PORTA_io_7: U51.15 (B6); also elsewhere on the board
/fpga_top/exp_PORTB_o_0: U52.20 (B1); also elsewhere on the board
/fpga_top/exp_PORTB_o_1: U52.18 (B3); also elsewhere on the board
/fpga_top/exp_PORTB_o_2: U52.16 (B5); also elsewhere on the board
/fpga_top/exp_PORTB_o_3: U52.14 (B7); also elsewhere on the board
/fpga_top/exp_PORTB_o_4: U52.21 (B0); also elsewhere on the board
/fpga_top/exp_PORTB_o_5: U52.19 (B2); also elsewhere on the board
/fpga_top/exp_PORTB_o_6: U52.17 (B4); also elsewhere on the board
/fpga_top/exp_PORTB_o_7: U52.15 (B6); also elsewhere on the board
/fpga_top/exp_PORTC_io_0: U53.51 (1B4); also elsewhere on the board
/fpga_top/exp_PORTC_io_1: U53.52 (1B3); also elsewhere on the board
/fpga_top/exp_PORTC_io_2: U53.53 (1B2); also elsewhere on the board
/fpga_top/exp_PORTC_io_3: U53.48 (1B6); also elsewhere on the board
/fpga_top/exp_PORTC_io_4: U53.47 (1B7); also elsewhere on the board
/fpga_top/exp_PORTC_io_5: U53.54 (1B1); also elsewhere on the board
/fpga_top/exp_PORTC_io_6: U53.46 (1B8); also elsewhere on the board
/fpga_top/exp_PORTC_io_7: U53.50 (1B5); also elsewhere on the board
/fpga_top/exp_PORTC_io_8: U53.45 (1B9); also elsewhere on the board
/fpga_top/exp_PORTC_io_9: U53.44 (1B10); also elsewhere on the board
/fpga_top/exp_PORTC_io_10: U53.43 (1B11); also elsewhere on the board
/fpga_top/exp_PORTC_io_11: U53.40 (2B2); also elsewhere on the board
/fpga_top/exp_PORTD_io_0: U53.42 (1B12); also elsewhere on the board
/fpga_top/exp_PORTD_io_1: U53.41 (2B1); also elsewhere on the board
/fpga_top/exp_PORTD_io_2: U53.36 (2B5); also elsewhere on the board
/fpga_top/exp_PORTD_io_3: U53.39 (2B3); also elsewhere on the board
/fpga_top/exp_PORTD_io_4: U53.29 (2B12); also elsewhere on the board
/fpga_top/exp_PORTD_io_5: U53.30 (2B11); also elsewhere on the board
/fpga_top/exp_PORTD_io_6: U53.37 (2B4); also elsewhere on the board
/fpga_top/exp_PORTD_io_7: U53.31 (2B10); also elsewhere on the board
/fpga_top/exp_PORTD_io_8: U53.32 (2B9); also elsewhere on the board
/fpga_top/exp_PORTD_io_9: U53.35 (2B6); also elsewhere on the board
/fpga_top/exp_PORTD_io_10: U53.34 (2B7); also elsewhere on the board
/fpga_top/exp_PORTD_io_11: U53.33 (2B8); also elsewhere on the board
/fpga_top/exp_PORTEFG_io_0: U54.29 (2B12), U55.29 (2B12), U55.54 (1B1); also elsewhere on the board
/fpga_top/exp_PORTEFG_io_1: U54.30 (2B11), U55.30 (2B11), U55.53 (1B2); also elsewhere on the board
/fpga_top/exp_PORTEFG_io_2: U54.31 (2B10), U55.31 (2B10), U55.52 (1B3); also elsewhere on the board
/fpga_top/exp_PORTEFG_io_3: U54.32 (2B9), U55.32 (2B9), U55.51 (1B4); also elsewhere on the board
/fpga_top/exp_PORTEFG_io_4: U54.33 (2B8), U55.33 (2B8), U55.50 (1B5); also elsewhere on the board
/fpga_top/exp_PORTEFG_io_5: U54.34 (2B7), U55.34 (2B7), U55.48 (1B6); also elsewhere on the board
/fpga_top/exp_PORTEFG_io_6: U54.35 (2B6), U55.35 (2B6), U55.47 (1B7); also elsewhere on the board
/fpga_top/exp_PORTEFG_io_7: U54.36 (2B5), U55.36 (2B5), U55.46 (1B8); also elsewhere on the board
/fpga_top/exp_PORTEFG_io_8: U54.37 (2B4), U55.37 (2B4), U55.45 (1B9); also elsewhere on the board
/fpga_top/exp_PORTEFG_io_9: U54.39 (2B3), U55.39 (2B3), U55.44 (1B10); also elsewhere on the board
/fpga_top/exp_PORTEFG_io_10: U54.40 (2B2), U55.40 (2B2), U55.43 (1B11); also elsewhere on the board
/fpga_top/exp_PORTEFG_io_11: U54.41 (2B1), U55.41 (2B1), U55.42 (1B12); also elsewhere on the board

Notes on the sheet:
NOTE:U54B is on SYS schema

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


Board: 4 copper layers, 100.0 x 80.0 mm, 169 parts (87 on the bottom side), 342 nets.

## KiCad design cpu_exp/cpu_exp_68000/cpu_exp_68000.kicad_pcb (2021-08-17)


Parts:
C1: 10u; C_1206
C2, C3: 100n; C_0805
LK1, LK2: Jumper_NO_Small; SolderJumper-2_P1.3mm_Open_RoundedPad1.0x1.5mm-domsmallctyd
LK3, LK4: Jumper_NC_Small; SolderJumper-2_P1.3mm_Closed_RoundedPad1.0x1.5mm-domsmallct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
LK6: Conn_02x03_Odd_Even; PinHeader_2x03_P2.54mm_Vertical
R1, R2, R3, R4, R5, R6, R7: 4k7; R_0805

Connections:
+5V: C1.1, C2.1, C3.1, R1.1, R2.1, R3.1, R4.1, R5.1, R6.1, R7.1; also elsewhere on the board
/PORTF0: LK1.1, R1.2; also elsewhere on the board
/PORTF1: LK2.1, R2.2; also elsewhere on the board
/PORTF2: LK3.1, R3.2; also elsewhere on the board
/PORTF3: LK4.1, R4.2; also elsewhere on the board
/PORTG9: LK6.1, R5.2; also elsewhere on the board
/PORTG10: LK6.3, R6.2; also elsewhere on the board
/PORTG11: LK6.5, R7.2; also elsewhere on the board
GND: C1.2, C2.2, C3.2, LK1.2, LK2.2, LK3.2, LK4.2, LK6.2, LK6.4, LK6.6; also elsewhere on the board

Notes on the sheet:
NF NF

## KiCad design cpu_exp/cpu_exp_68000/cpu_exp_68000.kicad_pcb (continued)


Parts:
P5: rpi_gpio_plug; PinHeader_2x20_P2.54mm_Vertical_SMD-dom
P6: MK3J52PLUG; PinSocket_2x20_P2.54mm_Vertical_SMD-dom
P7: mk3J54socket; PinSocket_2x08_P2.54mm_Vertical_SMD-dom

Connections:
+5V: P5.2 (5V), P5.4 (5V), P6.19 (5V), P6.20 (5V), P7.15 (+5V), P7.16 (+5V); also elsewhere on the board
/PORTA0: P6.1 (PORTA0); also elsewhere on the board
/PORTA1: P6.3 (PORTA1); also elsewhere on the board
/PORTA2: P6.5 (PORTA2); also elsewhere on the board
/PORTA3: P6.7 (PORTA3); also elsewhere on the board
/PORTA4: P6.9 (PORTA4); also elsewhere on the board
/PORTA5: P6.6 (PORTA5); also elsewhere on the board
/PORTA6: P6.8 (PORTA6); also elsewhere on the board
/PORTA7: P6.10 (PORTA7); also elsewhere on the board
/PORTB0: P6.11 (PORTB0); also elsewhere on the board
/PORTB1: P6.13 (PORTB1); also elsewhere on the board
/PORTB2: P6.15 (PORTB2); also elsewhere on the board
/PORTB3: P6.17 (PORTB3); also elsewhere on the board
/PORTB4: P6.12 (PORTB4); also elsewhere on the board
/PORTB5: P6.14 (PORTB5); also elsewhere on the board
/PORTB6: P6.16 (PORTB6); also elsewhere on the board
/PORTB7: P6.18 (PORTB7); also elsewhere on the board
/PORTC0: P5.3 (gpio2); also elsewhere on the board
/PORTC1: P5.5 (gpio3); also elsewhere on the board
/PORTC2: P5.7 (gpio4); also elsewhere on the board
/PORTC3: P5.8 (gpio14); also elsewhere on the board
/PORTC4: P5.10 (gpio15); also elsewhere on the board
/PORTC5: P5.11 (gpio17); also elsewhere on the board
/PORTC6: P5.12 (gpio18); also elsewhere on the board
/PORTC7: P5.15 (gpio22); also elsewhere on the board
/PORTC8: P5.19 (gpio10); also elsewhere on the board
/PORTC9: P5.16 (gpio23); also elsewhere on the board
/PORTC10: P5.18 (gpio24); also elsewhere on the board
/PORTC11: P5.24 (gpio8); also elsewhere on the board
/PORTD0: P5.21 (gpio9); also elsewhere on the board
/PORTD1: P5.22 (gpio25); also elsewhere on the board
/PORTD2: P5.23 (gpio11); also elsewhere on the board
/PORTD3: P5.26 (gpio7); also elsewhere on the board
/PORTD4: P5.29 (gpio5); also elsewhere on the board
/PORTD5: P5.31 (gpio6); also elsewhere on the board
/PORTD6: P5.32 (gpio12); also elsewhere on the board
/PORTD7: P5.33 (gpio13); also elsewhere on the board
/PORTD8: P5.35 (gpio19); also elsewhere on the board
/PORTD9: P5.36 (gpio16); also elsewhere on the board
/PORTD10: P5.38 (gpio20); also elsewhere on the board
/PORTD11: P5.40 (gpio21); also elsewhere on the board
/PORTE0: P5.13 (gpio27); also elsewhere on the board
/PORTE1: P5.37 (gpio26); also elsewhere on the board
/PORTE2: P6.22 (PORTE2); also elsewhere on the board
/PORTE3: P6.21 (PORTE3); also elsewhere on the board
/PORTE4: P6.24 (PORTE4); also elsewhere on the board
/PORTE5: P6.23 (PORTE5); also elsewhere on the board
/PORTE6: P6.26 (PORTE6); also elsewhere on the board
/PORTE7: P6.25 (PORTE7); also elsewhere on the board
/PORTE8: P6.30 (PORTE8); also elsewhere on the board
/PORTE9: P6.29 (PORTE9); also elsewhere on the board
/PORTE10: P6.32 (PORTE10); also elsewhere on the board
/PORTE11: P6.31 (PORTE11); also elsewhere on the board
/PORTF0: P6.35 (PORTF0); also elsewhere on the board
/PORTF1: P6.33 (PORTF1); also elsewhere on the board
/PORTF2: P6.36 (PORTF2); also elsewhere on the board
/PORTF3: P6.34 (PORTF3); also elsewhere on the board
/PORTF4: P7.9 (PORTF4); also elsewhere on the board
/PORTF5: P7.10 (PORTF5); also elsewhere on the board
/PORTF6: P7.7 (PORTF6); also elsewhere on the board
/PORTF7: P7.8 (PORTF7); also elsewhere on the board
/PORTF8: P7.5 (PORTF8); also elsewhere on the board
/PORTF9: P7.6 (PORTF9); also elsewhere on the board
/PORTF10: P7.3 (PORTF10); also elsewhere on the board
/PORTF11: P7.4 (PORTF11); also elsewhere on the board
/PORTG9: P6.38 (PORTG9); also elsewhere on the board
/PORTG10: P6.40 (PORTG10); also elsewhere on the board
/PORTG11: P6.39 (PORTG11); also elsewhere on the board
GND: P5.6 (gnd), P5.9 (gnd), P5.14 (gnd), P5.20 (gnd), P5.25 (gnd), P5.30 (gnd), P5.34 (gnd), P5.39 (gnd), P6.27 (GND), P6.28 (GND), P7.1 (GND), P7.2 (GND); also elsewhere on the board


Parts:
J1, J2, J3, J4: Conn_02x09_Odd_Even; PinHeader_2x09_P2.54mm_Vertical_SMD-dom
U1: MC68000FN; PLCC-68_THT-Socket
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

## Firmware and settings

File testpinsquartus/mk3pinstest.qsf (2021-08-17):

# -------------------------------------------------------------------------- #
#
# Copyright (C) 2018  Intel Corporation. All rights reserved.
# Your use of Intel Corporation's design tools, logic functions 
# and other software and tools, and its AMPP partner logic 
# functions, and any output files from any of the foregoing 
# (including device programming or simulation files), and any 
# associated documentation or information are expressly subject 
# to the terms and conditions of the Intel Program License 
# Subscription Agreement, the Intel Quartus Prime License Agreement,
# the Intel FPGA IP License Agreement, or other applicable license
# agreement, including, without limitation, that your use is for
# the sole purpose of programming logic devices manufactured by
# Intel and sold by Intel or its authorized distributors.  Please
# refer to the applicable agreement for further details.
#
# -------------------------------------------------------------------------- #
#
# Quartus Prime
# Version 18.1.0 Build 625 09/12/2018 SJ Lite Edition
# Date created = 18:30:09  March 19, 2021
#
# -------------------------------------------------------------------------- #
#
# Notes:
#
# 1) The default values for assignments are stored in the file:
#		mk3pinstest_assignment_defaults.qdf
#    If this file doesn't exist, see file:
#		assignment_defaults.qdf
#
# 2) Altera recommends that you do not modify this file. This
#    file is updated automatically by the Quartus Prime software
#    and any changes you make may be lost or overwritten.
#
# -------------------------------------------------------------------------- #


set_global_assignment -name FAMILY "MAX 10"
set_global_assignment -name DEVICE 10M16DCF256I7G
set_global_assignment -name TOP_LEVEL_ENTITY mk3pinstest
set_global_assignment -name ORIGINAL_QUARTUS_VERSION 18.1.0
set_global_assignment -name PROJECT_CREATION_TIME_DATE "18:30:09  MARCH 19, 2021"
set_global_assignment -name LAST_QUARTUS_VERSION "18.1.0 Lite Edition"
set_global_assignment -name PROJECT_OUTPUT_DIRECTORY output_files
set_global_assignment -name MIN_CORE_JUNCTION_TEMP "-40"
set_global_assignment -name MAX_CORE_JUNCTION_TEMP 100
set_global_assignment -name ERROR_CHECK_FREQUENCY_DIVISOR 256
set_global_assignment -name PARTITION_NETLIST_TYPE SOURCE -section_id Top
set_global_assignment -name PARTITION_FITTER_PRESERVATION_LEVEL PLACEMENT_AND_ROUTING -section_id Top
set_global_assignment -name PARTITION_COLOR 16764057 -section_id Top
set_global_assignment -name VHDL_FILE mk3pinstest.vhd
set_global_assignment -name POWER_PRESET_COOLING_SOLUTION "23 MM HEAT SINK WITH 200 LFPM AIRFLOW"
set_global_assignment -name POWER_BOARD_THERMAL_MODEL "NONE (CONSERVATIVE)"
set_global_assignment -name ENABLE_OCT_DONE OFF
set_global_assignment -name USE_CONFIGURATION_DEVICE OFF
set_global_assignment -name CRC_ERROR_OPEN_DRAIN OFF
set_global_assignment -name STRATIX_DEVICE_IO_STANDARD "3.3-V LVTTL"
set_global_assignment -name OUTPUT_IO_TIMING_NEAR_END_VMEAS "HALF VCCIO" -rise
set_global_assignment -name OUTPUT_IO_TIMING_NEAR_END_VMEAS "HALF VCCIO" -fall
set_global_assignment -name OUTPUT_IO_TIMING_FAR_END_VMEAS "HALF SIGNAL SWING" -rise
set_global_assignment -name OUTPUT_IO_TIMING_FAR_END_VMEAS "HALF SIGNAL SWING" -fall
set_global_assignment -name ENABLE_CONFIGURATION_PINS ON
set_global_assignment -name EXTERNAL_FLASH_FALLBACK_ADDRESS 00000000



set_instance_assignment -name IO_STANDARD LVDS -to HDMI_CK_o
set_location_assignment PIN_L10 -to HDMI_D2_o
set_location_assignment PIN_M11 -to "HDMI_D2_o(n)"
set_instance_assignment -name IO_STANDARD LVDS -to HDMI_D0_o
set_location_assignment PIN_M10 -to "HDMI_D1_o(n)"
set_location_assignment PIN_L9 -to HDMI_D1_o
set_instance_assignment -name IO_STANDARD LVDS -to HDMI_D1_o
set_instance_assignment -name IO_STANDARD LVDS -to HDMI_D2_o
set_location_assignment PIN_P11 -to HDMI_CK_o
set_location_assignment PIN_P10 -to "HDMI_CK_o(n)"
set_location_assignment PIN_P12 -to HDMI_D0_o
set_location_assignment PIN_P13 -to "HDMI_D0_o(n)"
set_location_assignment PIN_T14 -to HDMI_HPD_i
set_location_assignment PIN_T15 -to HDMI_SCL_o
set_location_assignment PIN_R14 -to HDMI_SDA_io
set_location_assignment PIN_R15 -to SYS_PHI2_o
set_location_assignment PIN_N14 -to SYS_SYNC_o
set_location_assignment PIN_N16 -to SYS_PHI1_o
set_location_assignment PIN_M16 -to SYS_RnW_o

set_location_assignment PIN_T12 -to SD_DET_i
set_location_assignment PIN_R11 -to SD_MISO_i
set_location_assignment PIN_T11 -to SD_MOSI_o
set_location_assignment PIN_R10 -to SD_CS_o
set_location_assignment PIN_P9 -to SD_CLK_o

set_location_assignment PIN_T9 -to SND_R_o
set_location_assignment PIN_M9 -to SND_L_o


set_location_assignment PIN_J11 -to CLK_48M_i

set_location_assignment PIN_T6 -to exp_PORTC_io[5]
set_location_assignment PIN_R6 -to exp_PORTC_io[2]
set_location_assignment PIN_T5 -to exp_PORTC_io[1]
set_location_assignment PIN_R5 -to exp_PORTC_io[0]
set_location_assignment PIN_T4 -to exp_PORTC_io[7]
set_location_assignment PIN_R4 -to exp_PORTC_io[3]
set_location_assignment PIN_T3 -to exp_PORTC_io[4]
set_location_assignment PIN_R3 -to exp_PORTC_io[6]

set_location_assignment PIN_P6 -to exp_PORTC_io[8]
set_location_assignment PIN_P5 -to exp_PORTC_io[9]
set_location_assignment PIN_P4 -to exp_PORTC_io[10]
set_location_assignment PIN_N5 -to exp_PORTD_io[0]
set_location_assignment PIN_N4 -to exp_PORTD_io[1]
set_location_assignment PIN_N3 -to exp_PORTC_io[11]
set_location_assignment PIN_M3 -to exp_PORTD_io[3]
set_location_assignment PIN_T2 -to exp_PORTD_io[6]
set_location_assignment PIN_R2 -to exp_PORTD_io[2]
set_location_assignment PIN_R1 -to exp_PORTD_io[9]
set_location_assignment PIN_P2 -to exp_PORTD_io[10]
set_location_assignment PIN_P1 -to exp_PORTD_io[11]
set_location_assignment PIN_N2 -to exp_PORTD_io[8]
set_location_assignment PIN_N1 -to exp_PORTD_io[7]
set_location_assignment PIN_M2 -to exp_PORTD_io[5]
set_location_assignment PIN_M1 -to exp_PORTD_io[4]

set_location_assignment PIN_M14 -to SYS_A_o[0]
set_location_assignment PIN_M15 -to SYS_A_o[1]
set_location_assignment PIN_L12 -to SYS_A_o[2]
set_location_assignment PIN_K14 -to SYS_A_o[3]
set_location_assignment PIN_L15 -to SYS_A_o[4]
set_location_assignment PIN_L16 -to SYS_A_o[5]
set_location_assignment PIN_K15 -to SYS_A_o[6]
set_location_assignment PIN_J15 -to SYS_A_o[7]
set_location_assignment PIN_L11 -to SYS_A_o[12]
set_location_assignment PIN_K12 -to SYS_A_o[13]
set_location_assignment PIN_K11 -to SYS_A_o[14]
set_location_assignment PIN_J12 -to SYS_A_o[15]
set_location_assignment PIN_J16 -to SYS_A_o[11]
set_location_assignment PIN_J14 -to SYS_A_o[10]
set_location_assignment PIN_H16 -to SYS_A_o[9]
set_location_assignment PIN_H15 -to SYS_A_o[8]
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

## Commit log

2021-07-16 Export from SVN #301
    [CPUSKT_65xxx.sch, CPUSKT_6x09.sch, UI.sch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]
2021-08-17 Mk.3 fixes and new 68000 expansion board
    [CPUSKT_65xxx.sch, CPUSKT_6x09.sch, UI.sch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]
2021-09-10 Updates from SVN to rev3.03
    [UI.sch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]
2021-12-09 Add fixit notes to 68000 cpu board for next revision
    [cpu_exp_68000.sch]
2021-12-09 Add pin mappings for 6800 card
2021-12-09 NEW: 6800 cpu card
    [CPUSKT_6800.sch, cpu_exp_6800.kicad_pcb, cpu_exp_6800.sch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]

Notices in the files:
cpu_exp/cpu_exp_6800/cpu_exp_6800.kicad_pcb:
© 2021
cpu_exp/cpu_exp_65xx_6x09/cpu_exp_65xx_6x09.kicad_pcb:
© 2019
